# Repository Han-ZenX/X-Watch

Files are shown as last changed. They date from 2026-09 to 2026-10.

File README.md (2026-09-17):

# X-Watch

X-Watch 是一款开源智能手表项目，主控芯片为 **STM32L4R9AII6U**，图形界面基于 **TouchGFX** 开发。本仓库统一管理硬件设计、嵌入式固件、配套软件、文档与测试。

> 项目处于早期开发阶段（硬件 Rev1.0），接口与目录结构可能随迭代调整。

## 核心方案

| 项目 | 选型 |
|---|---|
| 主控 MCU | STM32L4R9AII6U（Arm Cortex-M4F，120 MHz，2 MB Flash，640 KB SRAM，UFBGA169） |
| 图形框架 | TouchGFX（配合 TouchGFX Designer 设计界面） |
| 图形加速 | Chrom-ART（DMA2D）、GFXMMU，显示接口可选 LTDC / MIPI DSI |
| 硬件 EDA | KiCad |
| 固件构建 | CMake + GCC ARM（arm-none-eabi） |
| 大文件管理 | Git LFS |

### 为什么选 STM32L4R9

- **超低功耗**：STM32L4+ 系列，适合电池供电的穿戴设备。
- **图形能力完整**：片上集成 LTDC、MIPI DSI Host、Chrom-ART 加速器和 GFXMMU（适合圆形屏帧缓冲），无需外置图形芯片。
- **TouchGFX 官方支持**：ST 提供 STM32L4R9I-DISCO 参考设计（圆形 AMOLED 屏），可作为软硬件起点，手册见 [docs/references/Rev1.0](docs/references/Rev1.0)。

## 目录结构

```
X-Watch/
├── firmware/      # 嵌入式固件（app / hal / drivers / services 四层架构）
├── hardware/      # 硬件设计（原理图、PCB、BOM、Gerber、3D、引脚表）
├── software/      # 配套软件（desktop / mobile / cloud）
├── tools/         # 构建脚本与辅助工具
├── docs/          # 项目文档
├── tests/         # 单元测试 / 集成测试 / 硬件在环测试
└── ci/            # CI/CD 流水线配置
```

完整的架构说明见 [docs/architecture/architecture.md](docs/architecture/architecture.md)。

## 快速开始

### 1. 获取代码

```bash
git lfs install
git clone git@github.com:Han-ZenX/X-Watch.git
```

### 2. 开发环境

- [STM32CubeMX](https://www.st.com/en/development-tools/stm32cubemx.html)：外设与时钟配置
- [TouchGFX Designer](https://www.st.com/en/development-tools/touchgfxdesigner.html)：UI 设计与代码生成
- GCC ARM 工具链（arm-none-eabi-gcc）、CMake ≥ 3.20、Ninja
- [KiCad](https://www.kicad.org/)：打开 `hardware/schematic/v1.0/XWatch_Rev1.0/` 下的工程
- 调试器：ST-LINK

### 3. 编译固件

```bash
cd firmware
cmake -B build -G Ninja -DBOARD=default
cmake --build build
```

或使用构建脚本：

```bash
python tools/scripts/build.py --board=default
```

## 硬件

- 原理图 / PCB：`hardware/schematic/v1.0/XWatch_Rev1.0/`（KiCad 工程）
- 引脚分配：[hardware/pinout/pinout.md](hardware/pinout/pinout.md)
- 每次硬件改版需同步更新引脚表与 `firmware/boards/` 下对应的板级配置。

## 开发计划

- [ ] 硬件 Rev1.0 原理图与 PCB 完成
- [ ] STM32L4R9 板级支持（时钟、电源、调试串口）
- [ ] 显示屏驱动与 TouchGFX 移植
- [ ] 触摸驱动接入
- [ ] 基础表盘与界面
- [ ] 低功耗管理

## 变更记录

见 [CHANGELOG.md](CHANGELOG.md)。

## 许可证

本项目基于 [MIT License](LICENSE) 开源。

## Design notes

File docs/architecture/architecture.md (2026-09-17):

# 项目架构说明文档

## 1. 项目概述

本项目采用 **Monorepo + 分层模块化** 架构，将固件、硬件、上位机软件、工具链、文档和测试统一管理在同一个仓库中。

**设计目标：**
- 支持长期持续迭代（创业级产品生命周期）
- 硬件多版本并行开发
- 团队扩张后各模块可独立维护
- CI/CD 自动化构建与测试

---

## 2. 目录结构总览

```
project-template/
├── firmware/          # 嵌入式固件（MCU代码）
├── hardware/          # 硬件设计（原理图/PCB/BOM）
├── software/          # 上位机 / 配套软件
├── tools/             # 构建脚本与调试工具
├── docs/              # 项目文档
├── tests/             # 系统级测试
├── ci/                # CI/CD 流水线配置
├── .gitignore         # Git忽略规则
├── .gitattributes     # Git LFS 大文件管理
├── CHANGELOG.md       # 变更日志
└── LICENSE            # 许可证
```

---

## 3. 各目录详细说明

### 3.1 firmware/ — 嵌入式固件

固件采用四层分离架构，核心原则：**更换MCU只改HAL层，业务逻辑零修改**。

```
firmware/
├── CMakeLists.txt            # 顶层构建入口
├── src/
│   ├── main.c               # 入口点（初始化→主循环）
│   ├── app/                 # 【应用层】业务逻辑、状态机、UI
│   ├── hal/                 # 【硬件抽象层】GPIO/时钟/外设封装
│   ├── drivers/             # 【驱动层】具体外设驱动(SPI/I2C/UART)
│   └── services/            # 【服务层】通信协议/存储/OTA
├── boards/                  # 板级配置（不同硬件版本）
│   └── default/
│       └── board_config.h   # 引脚映射、时钟频率等
├── include/                 # 对外公开头文件
├── lib/                     # 第三方库（FreeRTOS/FatFS等）
└── tests/                   # 固件模块单元测试
```

#### 分层职责

| 层级 | 职责 | 可替换性 | 示例 |
|---|---|---|---|
| **app** | 业务逻辑、产品功能 | 不可替换（产品核心） | 测试流程、数据算法、用户交互 |
| **hal** | 硬件抽象、引脚映射 | 换MCU时整体替换 | GPIO操作、时钟配置、中断管理 |
| **drivers** | 外设通信协议实现 | 随外设更换替换 | ADS1258驱动、TCA9548A驱动 |
| **services** | 后台持续运行的服务 | 可独立升级 | TCP通信、Flash存储、OTA升级 |

#### 构建方式

```bash
# Debug构建（默认板级）
cmake -B build -DBOARD=default
cmake --build build

# Release构建
cmake -B build -DBOARD=v2.0 -DCMAKE_BUILD_TYPE=Release
cmake --build build
```

#### 新增板级

```bash
# 复制默认板级配置，修改引脚映射即可
cp -r boards/default boards/v2.0
# 编辑 boards/v2.0/board_config.h
cmake -B build -DBOARD=v2.0
```

---

### 3.2 hardware/ — 硬件设计

管理所有硬件设计文件，按版本号组织，支持多版本并行开发。

```
hardware/
├── schematic/               # 原理图
│   └── v1.0/               # 硬件版本1.0的原理图文件
├── pcb/                     # PCB Layout
│   └── v1.0/               # 硬件版本1.0的PCB文件
├── bom/                     # BOM物料清单（CSV/Excel）
├── gerber/                  # 送厂生产的Gerber文件
├── 3d/                      # 3D外壳/结构件模型
└── pinout/                  # 引脚分配表
    └── pinout.md            # MCU引脚功能对照表
```

#### 版本管理规则

| 规则 | 说明 |
|---|---|
| 原理图改版 | 新建 `schematic/v2.0/`，保留旧版本 |
| BOM变更 | 更新 `bom/` 中的文件，CHANGELOG记录 |
| pinout同步 | 每次硬件改版必须更新 `pinout.md` |
| 大文件管理 | `.SchDoc`/`.PcbDoc` 等通过 Git LFS 跟踪 |

---

### 3.3 software/ — 上位机 / 配套软件

```
software/
├── desktop/                 # PC桌面应用（Qt/Electron等）
├── mobile/                  # 移动端App（iOS/Android）
└── cloud/                   # 云端服务（数据平台/API）
```

各子项目独立维护，通过通信协议（TCP/BLE/MQTT）与固件交互。

---

### 3.4 tools/ — 工具链与脚本

```
tools/
├── scripts/                 # 自动化脚本
│   └── build.py            # 一键构建脚本
├── configs/                 # 通用配置模板
└── utilities/               # 辅助工具
                             # - 固件烧录器
                             # - 校准工具
                             # - 日志分析器
```

#### build.py 用法

```bash
python tools/scripts/build.py --board=default          # Debug构建
python tools/scripts/build.py --board=v2.0 --release   # Release构建
python tools/scripts/build.py --flash                  # 构建+烧录
python tools/scripts/build.py --clean                  # 清理
```

---

### 3.5 docs/ — 项目文档

```
docs/
├── architecture/            # 系统架构设计文档
├── api/                     # API接口文档（通信协议）
├── hardware/                # 硬件说明文档
├── manufacturing/           # 生产工艺/SOP文档
└── user-guide/              # 用户使用手册
```

---

### 3.6 tests/ — 系统级测试

```
tests/
├── unit/                    # 单元测试（纯软件，不需要硬件）
├── integration/             # 集成测试（模块间交互）
└── hwt/                     # 硬件在环测试（Hardware-in-the-Loop）
```

#### 测试策略

| 测试类型 | 运行环境 | 触发时机 | 覆盖范围 |
|---|---|---|---|
| unit | PC (Host) | 每次commit | 算法/逻辑函数 |
| integration | PC + 模拟器 | PR合并前 | 模块间通信 |
| hwt | 实际硬件 | 发版前 | 全链路验证 |

---

### 3.7 ci/ — CI/CD 流水线

```
ci/
└── workflows/
    └── build.yml            # GitHub Actions 构建配置
```

流水线自动执行：
1. 编译固件（多板级）
2. 运行单元测试
3. 生成二进制产物
4. （可选）自动烧录/部署

---

## 4. 核心架构原则

| 原则 | 实践方式 |
|---|---|
| **Monorepo** | 硬件+固件+软件在同一仓库，版本一致 |
| **分层隔离** | app不直接调用寄存器，只通过hal/driver接口 |
| **板级抽象** | 引脚映射集中在 `boards/` 目录，代码中无硬编码 |
| **组件化** | 每个驱动/服务是独立编译单元（CMake library） |
| **测试前置** | 新增功能必须配套单元测试 |
| **二进制管理** | 原理图/PCB用Git LFS，避免仓库膨胀 |
| **版本关联** | 硬件版本与固件版本通过Git Tag关联 |

---

## 5. 开发工作流

### 5.1 新功能开发

```
1. 创建分支:  git checkout -b feat/xxx
2. 固件开发:  在 firmware/src/app/ 添加业务逻辑
3. 驱动开发:  在 firmware/src/drivers/ 添加外设驱动
4. 编写测试:  在 firmware/tests/ 或 tests/unit/ 添加测试
5. 本地验证:  python tools/scripts/build.py --board=default
6. 提交PR:    CI自动编译+测试
```

### 5.2 硬件改版

```
1. 新建版本:  cp -r hardware/schematic/v1.0 hardware/schematic/v2.0
2. 更新设计:  在EDA工具中修改v2.0原理图/PCB
3. 更新引脚:  修改 hardware/pinout/pinout.md
4. 新增板级:  cp -r firmware/boards/default firmware/boards/v2.0
5. 适配固件:  修改 boards/v2.0/board_config.h
6. 验证:      cmake -DBOARD=v2.0 编译通过
```

### 5.3 发版流程

```
1. 更新 CHANGELOG.md
2. Git Tag:   git tag v1.2.0-hw1.0 (固件版本-硬件版本)
3. CI自动:    编译Release固件 → 生成Gerber → 打包发布
```

---

## 6. 参考项目

本架构参考以下知名开源项目的组织方式：

| 项目 | 参考要素 |
|---|---|
| ESP-IDF | components组件化、CMake构建系统 |
| Zephyr RTOS | boards板级抽象、Kconfig配置 |
| RIOT-OS | cpu/drivers/sys分层、pkg第三方包 |
| FreeRTOS | 内核源码单一副本、Demo目录分离 |

---

## 7. 技术选型建议

| 领域 | 推荐方案 |
|---|---|
| 构建系统 | CMake + Ninja |
| 版本控制 | Git + Git LFS |
| CI/CD | GitHub Actions / GitLab CI |
| 测试框架 | Unity (C) / Google Test (C++) |
| 文档工具 | Doxygen + Sphinx |
| 硬件EDA | Altium Designer / KiCad |
| 通信协议 | 自定义二进制协议 / MQTT / SCPI |

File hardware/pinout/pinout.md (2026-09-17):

# 引脚分配表

| 引脚 | 功能 | 说明 |
|---|---|---|
| PA9  | UART_TX | 调试串口发送 |
| PA10 | UART_RX | 调试串口接收 |
| PA5  | SPI_SCK | SPI时钟 |
| PA6  | SPI_MISO | SPI主入从出 |
| PA7  | SPI_MOSI | SPI主出从入 |
| PA4  | SPI_CS | SPI片选 |
| PB6  | I2C_SCL | I2C时钟 |
| PB7  | I2C_SDA | I2C数据 |
| PC13 | LED_STATUS | 状态指示灯 |
| PA0  | BTN_USER | 用户按键 |

> 此文件应与原理图保持同步。每次硬件改版需更新。

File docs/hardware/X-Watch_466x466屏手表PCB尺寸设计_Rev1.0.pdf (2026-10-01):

X-Watch 466×466 屏手表 PCB 尺寸设计 Rev1.0 | 第 1 页

# 466×466 屏手表 PCB 尺寸设计

X-Watch Rev2.0 · 1.43″ 466×466 AMOLED（DO0143FMST02）· 主板外形估算 · Rev1.0 · 2026-10-01

## 1. 结论

项目 | 推荐值 | 依据
表壳外径 | Ø46 mm（厚约 11 mm） | 同屏商用表集中在 46–47 mm
中框内腔 | Ø42 mm | 壁厚 2 mm
屏模组 | Ø39.2 mm，显示区 Ø36.35 mm | DO0143FMST02 规格书第 3、6 页
主板 PCB | Ø36 mm，一侧切平 2 mm（可选范围 Ø34–38） | 比屏模组单边缩 1.6 mm，比内腔单边缩 3 mm
可用面积 | 单面约 1000 mm²，双面约 2000 mm² | 扣除安装孔、净空后实际可布约 60–70%
板厚 / 层数 | 0.8 mm，6 层（打样可 1.0 mm 4 层） | 商用表多为 0.6–0.8 mm 多层 HDI

一句话：1.43″ 466×466 屏配 Ø46 mm 表壳，主板做 Ø36 mm 左右的圆板（约 36 × 34 mm），与屏模组投影基本重合、略小一圈。这和项目已有的 1.2″ 屏方案的比例一致：Rev1.0 文档中屏模组 Φ33.22 → 主板约 Φ30，比值 0.90；本方案 39.2 → 36，比值 0.92。

## 2. 同屏商用手表参考

下表都是 1.43″ 466×466 AMOLED 的手表（Waveshare 为同屏开发板）。表壳尺寸来自官方或评测站点公开 参数；电池容量来自拆解报告。这些产品的拆解报告都没有公布主板的毫米尺寸，所以第 3 节用几何约束推算主板大小。

产品 | 表壳尺寸（mm） | 屏幕 | 电池 | 备注
华为 WATCH GT 4 46mm | 46 × 46 × 10.9 | 1.43″ 466×466 | —
Amazfit GTR 4 | 46 × 46 × 10.6 | 1.43″ 466×466 | —
小米 Watch S1 | 46.5 × 46.5 × 11 | 1.43″ 466×466 | 470 mAh | 主控 BES2500BP，PMIC DA9168
小米 Watch S3 | 47 × 47 × 12 | 1.43″ 466×466 | 486 mAh | 主控 BES2700BP，PMIC DA9168
OnePlus Watch 2 | 47 × 46.6 × 12.1 | 1.43″ 466×466 | — | Wear OS
TicWatch Pro 5 | 50 × 48 × 12 | 1.43″ 466×466 | — | Wear OS，双层屏
Waveshare ESP32-S3-Touch-AMOLED-1.43 | 盖板 Ø46，带壳 Ø48 × 12.3 | 1.43″ 466×466 | 外接 | 开发板，主板安装孔距 31.5 mm

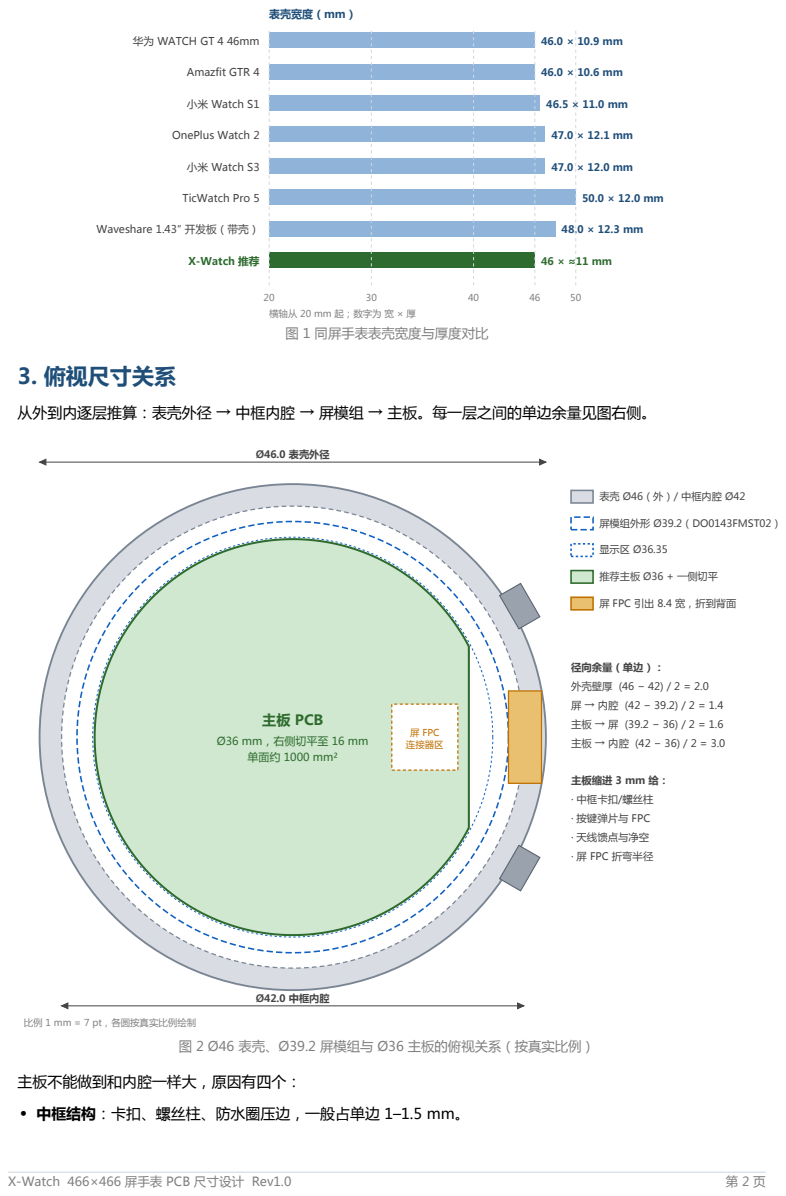
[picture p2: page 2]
X-Watch 466×466 屏手表 PCB 尺寸设计 Rev1.0; 表壳宽度（mm）; 华为 WATCH GT 4 46mm; Amazfit GTR 4; 小米 Watch S1; OnePlus Watch 2; 小米 Watch S3; TicWatch Pro 5; Waveshare 1.43″ 开发板（带壳）; X-Watch 推荐; 3. 俯视尺寸关系; 主板 PCB; 屏 FPC 连接器区; Ø46.0 表壳外径; Ø42.0 中框内腔; 表壳 Ø46（外）/ 中框内腔 Ø42; 屏模组外形 Ø39.2（DO0143FMST02）; 显示区 Ø36.35; 推荐主板 Ø36 + 一侧切平; 径向余量（单边）：; 外壳壁厚 (46 − 42) / 2 = 2.0; 主板缩进 3 mm 给：; · 中框卡扣/螺丝柱; · 按键弹片与 FPC; · 天线馈点与净空; · 屏 FPC 折弯半径; 主板不能做到和内腔一样大，原因有四个：

横轴从 20 mm 起；数字为 宽 × 厚
图 1 同屏手表表壳宽度与厚度对比

从外到内逐层推算：表壳外径 → 中框内腔 → 屏模组 → 主板。每一层之间的单边余量见图右侧。

屏 FPC 引出 8.4 宽，折到背面

Ø36 mm，右侧切平至 16 mm
单面约 1000 mm²

比例 1 mm = 7 pt，各圆按真实比例绘制

图 2 Ø46 表壳、Ø39.2 屏模组与 Ø36 主板的俯视关系（按真实比例）

• 中框结构：卡扣、螺丝柱、防水圈压边，一般占单边 1–1.5 mm。

## 4. 厚度方向堆叠

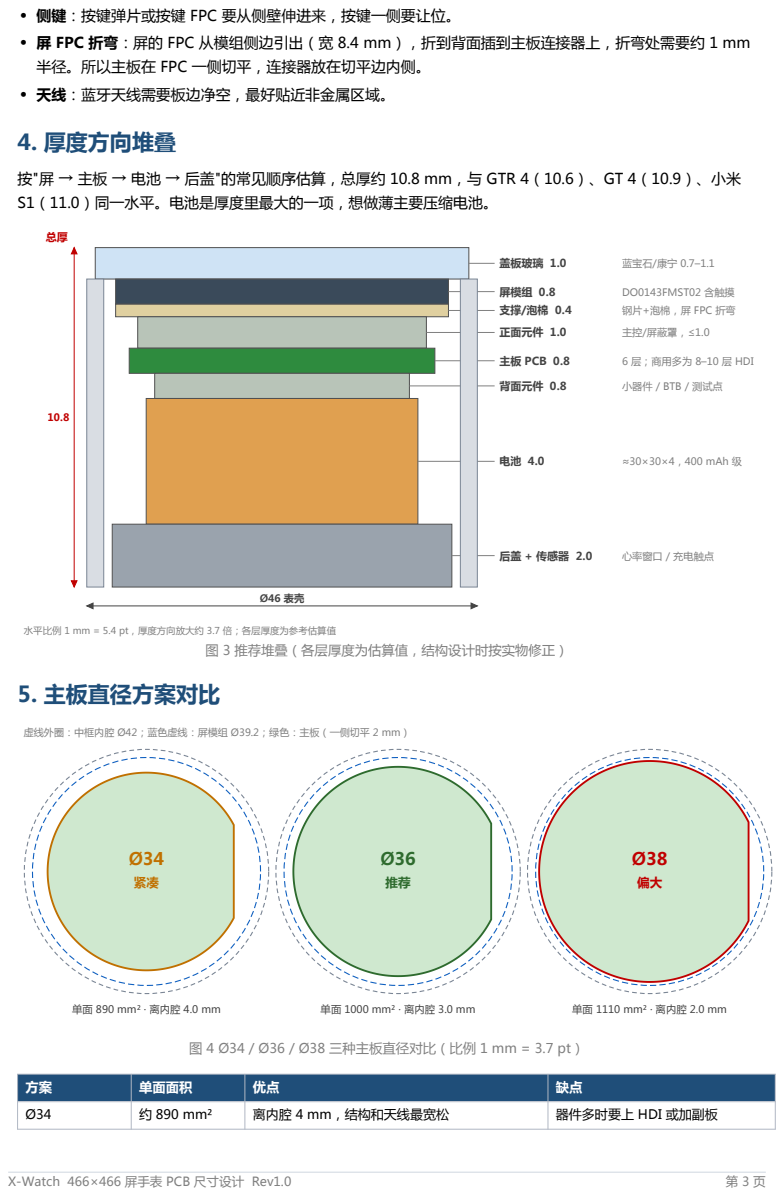
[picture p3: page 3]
X-Watch 466×466 屏手表 PCB 尺寸设计 Rev1.0; 盖板玻璃 1.0; 蓝宝石/康宁 0.7–1.1; 屏模组 0.8; DO0143FMST02 含触摸; 钢片+泡棉，屏 FPC 折弯; 正面元件 1.0; 主控/屏蔽罩，≤1.0; 主板 PCB 0.8; 6 层；商用多为 8–10 层 HDI; 背面元件 0.8; 小器件 / BTB / 测试点; ≈30×30×4，400 mAh 级; 后盖 + 传感器 2.0; 心率窗口 / 充电触点; 5. 主板直径方案对比

• 侧键：按键弹片或按键 FPC 要从侧壁伸进来，按键一侧要让位。
• 屏 FPC 折弯：屏的 FPC 从模组侧边引出（宽 8.4 mm），折到背面插到主板连接器上，折弯处需要约 1 mm
半径。所以主板在 FPC 一侧切平，连接器放在切平边内侧。
• 天线：蓝牙天线需要板边净空，最好贴近非金属区域。

按"屏 → 主板 → 电池 → 后盖"的常见顺序估算，总厚约 10.8 mm，与 GTR 4（10.6）、GT 4（10.9）、小米
S1（11.0）同一水平。电池是厚度里最大的一项，想做薄主要压缩电池。

水平比例 1 mm = 5.4 pt，厚度方向放大约 3.7 倍；各层厚度为参考估算值

图 3 推荐堆叠（各层厚度为估算值，结构设计时按实物修正）

虚线外圈：中框内腔 Ø42；蓝色虚线：屏模组 Ø39.2；绿色：主板（一侧切平 2 mm）

单面 890 mm² · 离内腔 4.0 mm

单面 1000 mm² · 离内腔 3.0 mm

单面 1110 mm² · 离内腔 2.0 mm

图 4 Ø34 / Ø36 / Ø38 三种主板直径对比（比例 1 mm = 3.7 pt）

方案 | 单面面积 | 优点 | 缺点

Ø34 | 约 890 mm² | 离内腔 4 mm，结构和天线最宽松 | 器件多时要上 HDI 或加副板

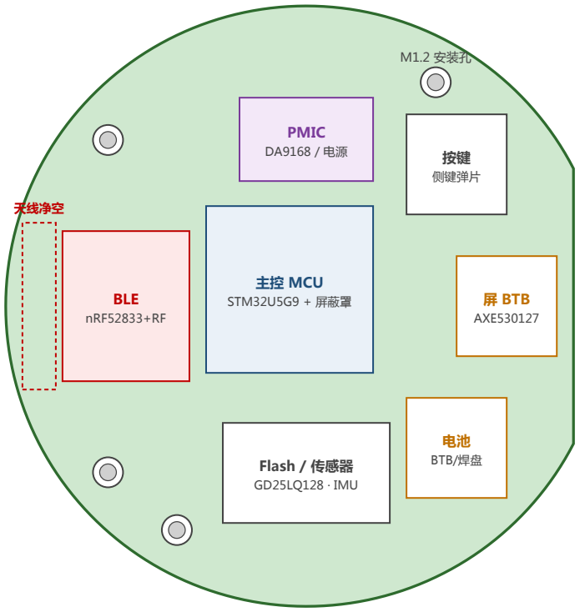
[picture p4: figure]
主控 MCU; STM32U5G9 + 屏蔽罩; 屏 BTB; AXE530127; BLE; nRF52833+RF; PMIC; Flash / 传感器; GD25LQ128 · IMU; 侧键弹片; BTB/焊盘; 天线净空; M1.2 安装孔

X-Watch 466×466 屏手表 PCB 尺寸设计 Rev1.0 | 第 4 页
方案 | 单面面积 | 优点 | 缺点
Ø36（推荐） | 约 1000 mm² | 面积与结构余量平衡；比屏小一圈，组装时屏能完 全盖住主板 | —
Ø38 | 约 1110 mm² | 面积最大 | 离内腔只剩 2 mm，侧键、卡扣、天 线都很挤；几乎与屏外形一样大

面积按"圆减去 2 mm 切平弓形"计算。按现有《商业手表拆解参考与芯片选型》文档的估算，主控、BLE、PMIC 、传感器等器件本体约 530 mm²，Ø36 双面约 2000 mm²，按 60% 可用率算约 1200
mm²，余量充足，不需要 HDI 也有机会放下（BGA 器件扇出除外）。

## 6. 主板分区建议

分区原则

- 屏 BTB 放在屏 FPC 折弯一侧（切平边）
位置按屏规格书第 6 页 FPC 尺寸定
- BLE 射频放在对侧板边，天线朝外
净空区所有层禁铜
- 主控居中，扇出走线最短
- PMIC 靠近电池与充电触点
- 按键区与中框侧键对位
- 安装孔 3–4 个，距板边 ≥1 mm

本图只表达相对位置，

不代表实际器件尺寸和最终布局

图 5 Ø36 主板功能分区示意（相对位置，非实际布局）

## 7. 下一步

- 先定结构，再定板框：表壳和中框的内腔、按键位置、螺丝柱位置确定后，在 KiCad 的 Edge.Cuts 层画 Ø36 板框。
- 导入屏的 3D 模型：用屏规格书第 6 页的 FPC 引出位置确定屏 BTB 连接器坐标，避免 FPC 折弯后够不着。
- 做纸板/3D 打印样件：把屏、主板外形、电池叠在一起验证厚度和装配。
- 确认电池：根据剩余厚度选电池，例如 4 mm 厚约 400 mAh 级；需要更大容量时表壳要加厚。

说明：表壳、屏幕、电池数据来自公开资料；主板尺寸、层厚和面积是按几何关系推算的工程估算值，不是某款产品的 实测值。最终尺寸以结构设计为准。

X-Watch 466×466 屏手表 PCB 尺寸设计 Rev1.0 | 第 5 页

## 8. 参考资料

- DWO DO0143FMST02 规格书 REV 0.0（docs/references/Rev2.0/显示屏）：模组 39.15 × 39.3 × 0.8 mm，显示区 36.35 mm
- HUAWEI WATCH GT 4 规格：consumer.huawei.com/uk/wearables/watch-gt4/specs/
- Amazfit GTR 4 规格：gadgetsandwearables.com/technical-specs/amazfit-gtr-4/
- 小米 Watch S1 / S3 规格：mi.com/global/product/xiaomi-watch-s1/specs/、mi.com/global/product/ xiaomi-watch-s3/specs/
- 小米 Watch S1 / S3 拆解：52audio.com/archives/115291.html、52audio.com/archives/189871.html
- OnePlus Watch 2 规格：gsmarena.com/oneplus_watch_2-12843.php；TicWatch Pro 5：androidcentral.com
- Waveshare ESP32-S3-Touch-AMOLED-1.43 尺寸图：docs.waveshare.com/ESP32-S3-Touch-AMOLED-1.43
- X-Watch 商业手表拆解参考与芯片选型 Rev1.0、显示屏候选方案对比 Rev1.0（docs/hardware）

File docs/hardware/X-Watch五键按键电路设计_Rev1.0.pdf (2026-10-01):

X-Watch 五键按键电路设计 Rev1.0

第 1 页

# 五键按键电路设计

X-Watch Rev2.0 · BUTTONS 页 · SW1–SW5 与 DA9168 / STM32U5G9 连接 · Rev1.0 · 2026-09-28

## 1. 方案概述

X-Watch Rev2.0 的 BUTTONS 页放了 5 个松下 EVPAEDB2A（立创 C79150）侧推轻触开关 SW1–SW5。按键布 局参考佳明 fēnix 7：左 3 右 2，左侧管"看"（电源、上下翻页），右侧管"做"（确认、返回），触摸屏只做辅助。

电路上分两类：SW1 是电源键，同时接 DA9168 的 RIN_N（Ship 模式唤醒、长按 12s 硬件复位）和 MCU； SW2–SW5 是功能键，只接 STM32U5G9 的 GPIO，任何误触都不会让整机断电。

X-Watch

1.43" AMOLED 触摸屏

12

6

SW1
PWR·LIGHT

SW2
UP·MENU

SW3
DOWN

SW4
START·OK

SW5
BACK
位号 位置 | 功能 | 连接
SW1 | 左上 10 点 | 电源 / 背光 | RIN_N + GPIO
SW2 | 左中 9 点 | 上翻 / 菜单 | GPIO
SW3 | 左下 8 点 | 下翻 | GPIO
SW4 | 右上 2 点 | 开始 / 确认 | GPIO
SW5 | 右下 4 点 | 返回 / 计圈 | GPIO

左侧 3 键管"看"：电源、上下翻页
右侧 2 键管"做"：确认、返回
只有 SW1 接 DA9168 RIN_N（唤醒 / 硬件复位）

图 1 五键布局与功能分配（佩戴视角正视图，左手佩戴）

位号 | 位置 | 功能 | 短按 | 长按 | 连接
SW1 | 左上 10 点 | 电源 / 背光 | 亮屏、Ship 唤醒 | 1s 控制菜单；3s 关机菜单；12s 硬件复 位 | DA9168 RIN_N + PA0
SW2 | 左中 9 点 | 上翻 / 菜单 | 向上滚动 | 1s 主菜单 | PA1
SW3 | 左下 8 点 | 下翻 | 向下滚动 | 1s 音乐控制 | PA2
SW4 | 右上 2 点 | 开始 / 确认 | 确认、开始/停止活 动 | 1s 可自定义 | PA3
SW5 | 右下 4 点 | 返回 / 计圈 | 返回、活动中计圈 | 1s 最近应用 | PA4

组合键：SW3 + SW4 同时长按 = 锁定 / 解锁触摸屏（同 fēnix 7 的 DOWN + START）。短按、长按的具体功能由固件定 义，表中为建议值。

## 2. 当前原理图状态

对 BUTTONS.kicad_sch 和顶层 XWatch_Rev2.0.kicad_sch 逐项核对的结果：

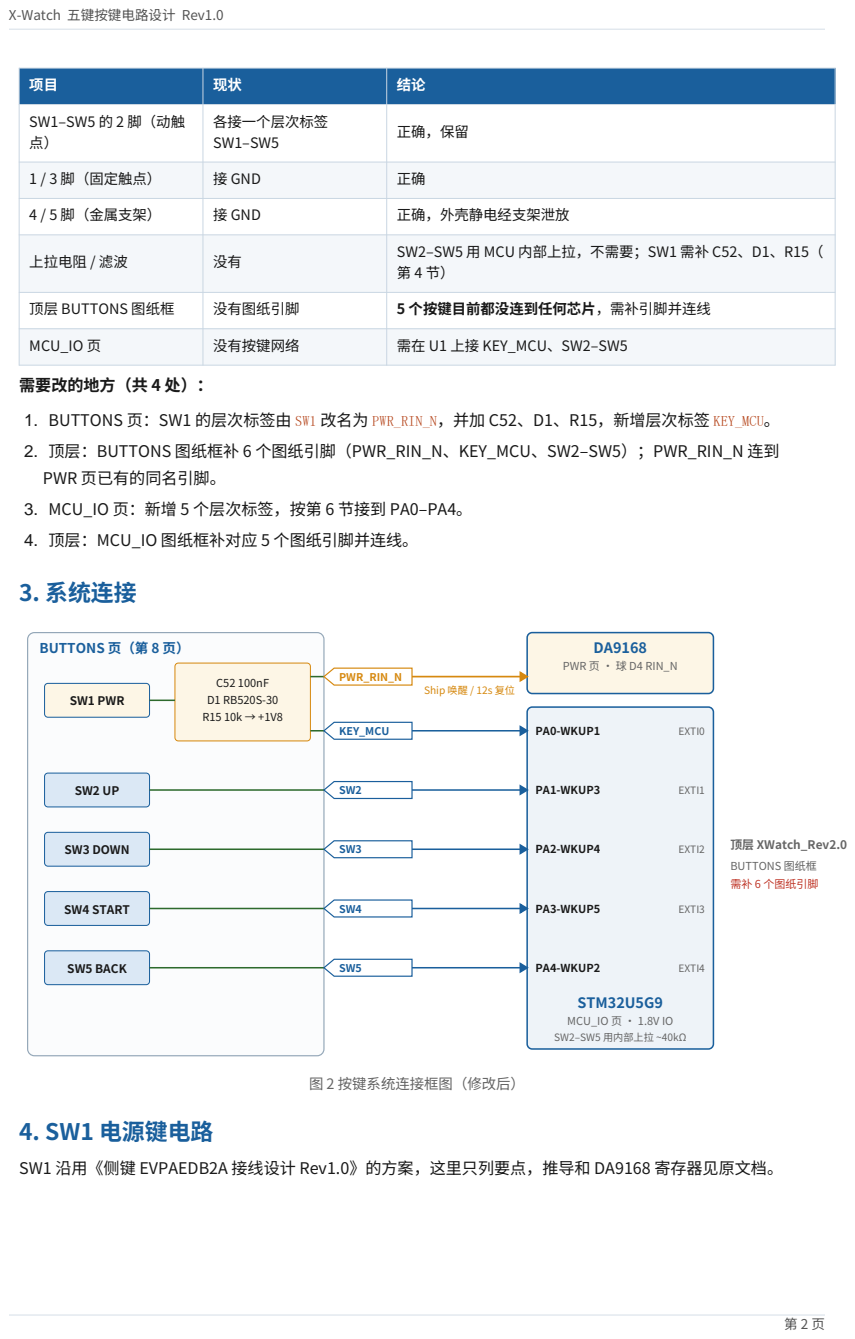
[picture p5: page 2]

SW1–SW5 的 2 脚（动触 点） | 各接一个层次标签 SW1–SW5 | 正确，保留

1 / 3 脚（固定触点） | 接 GND | 正确

4 / 5 脚（金属支架） | 接 GND | 正确，外壳静电经支架泄放

上拉电阻 / 滤波 | 没有 | SW2–SW5 用 MCU 内部上拉，不需要；SW1 需补 C52、D1、R15（ 第 4 节）

顶层 BUTTONS 图纸框 | 没有图纸引脚 | 5 个按键目前都没连到任何芯片，需补引脚并连线

MCU_IO 页 | 没有按键网络 | 需在 U1 上接 KEY_MCU、SW2–SW5

1. BUTTONS 页：SW1 的层次标签由 SW1 改名为 PWR_RIN_N，并加 C52、D1、R15，新增层次标签 KEY_MCU。

2. 顶层：BUTTONS 图纸框补 6 个图纸引脚（PWR_RIN_N、KEY_MCU、SW2–SW5）；PWR_RIN_N 连到
PWR 页已有的同名引脚。
3. MCU_IO 页：新增 5 个层次标签，按第 6 节接到 PA0–PA4。

SW1 沿用《侧键 EVPAEDB2A 接线设计 Rev1.0》的方案，这里只列要点，推导和 DA9168 寄存器见原文档。

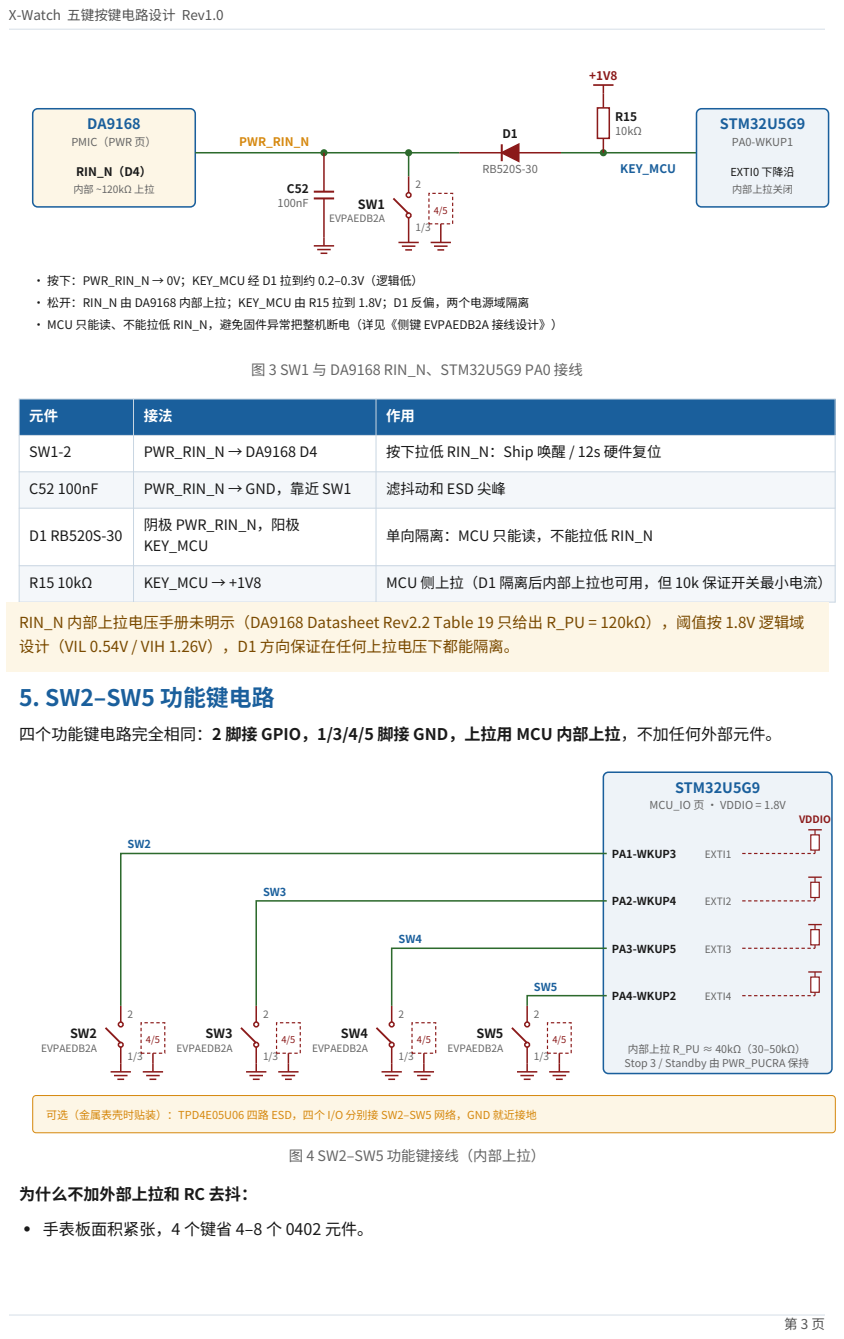
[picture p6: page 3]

• 按下：PWR_RIN_N → 0V；KEY_MCU 经 D1 拉到约 0.2–0.3V（逻辑低）
• 松开：RIN_N 由 DA9168 内部上拉；KEY_MCU 由 R15 拉到 1.8V；D1 反偏，两个电源域隔离
• MCU 只能读、不能拉低 RIN_N，避免固件异常把整机断电（详见《侧键 EVPAEDB2A 接线设计》）

SW1-2 | PWR_RIN_N → DA9168 D4 | 按下拉低 RIN_N：Ship 唤醒 / 12s 硬件复位

C52 100nF | PWR_RIN_N → GND，靠近 SW1 | 滤抖动和 ESD 尖峰

D1 RB520S-30 | 阴极 PWR_RIN_N，阳极 KEY_MCU | 单向隔离：MCU 只能读，不能拉低 RIN_N

R15 10kΩ | KEY_MCU → +1V8 | MCU 侧上拉（D1 隔离后内部上拉也可用，但 10k 保证开关最小电流）

RIN_N 内部上拉电压手册未明示（DA9168 Datasheet Rev2.2 Table 19 只给出 R_PU = 120kΩ），阈值按 1.8V 逻辑域
设计（VIL 0.54V / VIH 1.26V），D1 方向保证在任何上拉电压下都能隔离。

四个功能键电路完全相同：2 脚接 GPIO，1/3/4/5 脚接 GND，上拉用 MCU 内部上拉，不加任何外部元件。

可选（金属表壳时贴装）：TPD4E05U06 四路 ESD，四个 I/O 分别接 SW2–SW5 网络，GND 就近接地

第 4 页

- STM32U5 的内部上拉在 Run、Stop 0/1/2 模式下由 GPIOx_PUPDR 控制；进入 Stop 3、Standby、 Shutdown 时由 PWR_PUCRA 接管（需置 PWR_APCR.APC = 1），按键在所有低功耗模式下都有确定的高电 平。
- 规格书抖动时间最大 10ms，软件去抖 20ms 已足够，硬件 RC 只会增加元件和按下时的充放电电流。

电气校核：

检查项 | 计算 / 依据 | 结论
高电平 | 松开时内部上拉到 VDDIO = 1.8V，开关断开无漏电 | 满足
低电平 | 按下时 GPIO ≈ 0V（触点电阻 ≤ 1Ω，规格书），VIL ≤ 0.3 × 1.8V = 0.54V | 满足
按下电流 | 1.8V / 40kΩ ≈ 45µA（30–50kΩ 对应 36–60µA） | 只在按下期间耗电
开关最小负载 | EVP-AE 额定 10µA / 2V DC 起；45µA 远大于 10µA，但 1.8V 略低于 2V | 可用，同 SW1，样机验证
抖动 | 规格书 Bouncing ≤ 10ms（ON、OFF） | 软件去抖取 20ms，有 2 倍余 量
待机功耗 | 松开时开关断开，上拉无电流 | 0
ESD | 支架（4/5 脚）接 GND 吸收大部分静电 | 金属表壳建议加 TVS（见下）

如果表壳是金属或按键帽是金属，建议在 SW2–SW5 四个网络上加一颗四路 ESD 阵列（如 TI TPD4E05U06，USON-10 ，四个 I/O 正好对应四个键），SW1 那一路已有 C52。塑料外壳可以不贴，原理图上画出来并标 DNP 即可。

## 6. GPIO 分配

分配原则：

1. EXTI 线号不同：STM32 同一编号的 EXTI 线只能选一个端口（PA0 和 PB0 共用 EXTI0），5 个键必须用 5 个 不同的引脚编号，否则中断无法区分。
2. WKUP 编号不同：Stop 3、Standby、Shutdown 模式下普通 EXTI 不能唤醒，只能靠 WKUP1–WKUP8。每 个 WKUPn 只能从候选脚中选一个（PWR_WUCR3.WUSELn），所以 5 个键要占 5 个不同的 WKUP 编号。
3. 避开已用和特殊引脚：PG13/PG14（I2C1）、PH4/PH5（I2C5）、PH7/PH8（I2C3）已用；PA13/PA14（ SWD）、PH3（BOOT0）、PC14/PC15、PH0/PH1（晶振）不用。
网络 | 建议引脚 | EXTI | WKUP | 备选引脚（同一 WKUP 编号）
KEY_MCU（SW1） | PA0 | EXTI0 | WKUP1 | PB2、PE4
SW2 | PA1 | EXTI1 | WKUP3 | PB6、PE6
SW3 | PA2 | EXTI2 | WKUP4 | PB1、PB7
SW4 | PA3 | EXTI3 | WKUP5 | PB8、PC5
SW5 | PA4 | EXTI4 | WKUP2 | PC13、PE5

PA0–PA4 在同一端口，初始化和 PWR_PUCRA 配置最简单。如果 PCB 上这几个球离按键太远，可以换成备选列里的引 脚，但换完要再查一遍 EXTI 编号不能重复（比如 SW2 换 PB6 后，EXTI6 就不能再给别的键用）。WKUP 候选脚以 RM0456 的 PWR_WUCR3 为准，表中来自原理图符号的引脚名。

## 7. 元件清单

第 5 页

位号 | 规格 | 封装 | 数量 | 说明
SW1–SW5 | EVPAEDB2A（C79150），3.0N，20 万 次 | 板边侧推 4.5 × 2.6mm | 5 | 已放置
D1 | RB520S-30，30V / 200mA 肖特基 | SOD-523 | 1 | SW1 用，待添加
R15 | 10kΩ / 1% | 0402 | 1 | SW1 用，待添加
C52 | 100nF / 10V / X5R | 0402 | 1 | SW1 用，待添加
U13 | TPD4E05U06 四路 ESD | USON-10 | 1 | 可选，金属外壳时贴装，否则 DNP

位号按当前原理图顺延：已用到 R14、C49、U12；D1 目前未使用。

## 8. PCB 与结构要点

- 板边缺口：EVPAEDB2A 封装自带 3.8 × 1.35mm 的 Edge.Cuts 缺口，5 个开关都要让缺口正好落在板框上并 连成一体。左侧 3 个开关在同一条板边上，间距按表壳按键孔位定，建议中心距不小于 7mm，避免手指同时 按到两个键。
- 走线：按键信号是低速信号，没有阻抗要求；1/3 脚各打一个 GND 过孔，4/5 脚就近接地。SW1 的 C52 紧靠 2 脚；ESD 阵列（如贴装）放在开关和 MCU 之间、靠近开关。
- 结构：按键帽与开关按压头之间留 0.1–0.2mm 间隙，每个按键轴加 O 型圈防水。SW4（START）按键帽建议 用红色或带标识，方便盲按。

## 9. 固件要点

0 | 20ms | 1s | 3s | 12s按住时间
SW1 电源 | 去抖 | 短按：亮屏 | 长按 1s：控制菜单 | 按住 3s：关机菜单 | 硬复位
SW2 UP | 去抖 | 短按：上翻 | 长按 1s：主菜单
SW3 DOWN | 去抖 | 短按：下翻 | 长按 1s：音乐控制
SW4 START | 去抖 | 短按：确认/开始 | 长按 1s：自定义
SW5 BACK | 去抖 | 短按：返回/计圈 | 长按 1s：最近应用

DA9168 t_PRESS

图 5 按住时间与动作阈值（示意，时间轴非比例）

- GPIO 配置：PA1–PA4 设为输入 + 内部上拉；PA0（KEY_MCU）设为输入、关闭内部上拉（外部已有 R15）。 全部配置为 EXTI 下降沿中断。
- 去抖：中断触发后启动 20ms 定时器，到时再读电平确认；按住期间用定时器计时，区分短按（1s 内松开） 和长按（按住满 1s）。
- 低功耗：进入 Stop 3 / Standby 前，把 PWR_PUCRA 的 PU0–PU4 置 1、PWR_APCR.APC 置 1，并在 PWR_WUCR1/2/3 里使能 WKUP1–WKUP5、选下降沿和对应引脚。
- 与硬件复位的关系：SW1 的关机菜单设在 3s，远小于 DA9168 的 12s 硬件复位（t_PRESS），两者不冲突； 其他 4 个键没有硬件复位功能，长按多久都安全。

第 6 页

- 组合键：两个键都处于按下状态并持续 ≥ 1s 才触发组合功能，先按下的键的单键长按要推迟到另一个键确定 没有按下后再执行。

## 10. 待确认事项

- 引脚：规格书 Circuit Diagram 标为 1、2、1'（1 与 1' 内部相连），与工程符号的 1/3 固定触点、2 动触点一 致；首批样品仍建议用万用表确认一次。
- 1.8V 下开关导通可靠性（额定最小 2V / 10µA）需在样机上做按压寿命和接触电阻测试。
- 外壳材质确定后决定 U13（ESD 阵列）是否贴装。
- PCB 布局后按实际 BGA 球位置复核第 6 节的引脚分配。

## 11. 参考资料

- X-Watch 侧键 EVPAEDB2A 接线设计 Rev1.0（docs/hardware）
- X-Watch 佳明 fēnix 7 按键布局与功能分析 Rev1.0（docs/hardware）
- EVPAEDB2A 规格书：docs/references/Rev2.0/按键/C79150_轻触开关_EVPAEDB2A_规格书 _WJ129045.PDF
- ST RM0456 STM32U5 参考手册：GPIO、EXTI、PWR（WUCR、PUCR、APCR）章节
- 原理图：hardware/schematic/v1.0/XWatch_Rev2.0/BUTTONS.kicad_sch、MCU_IO.kicad_sch

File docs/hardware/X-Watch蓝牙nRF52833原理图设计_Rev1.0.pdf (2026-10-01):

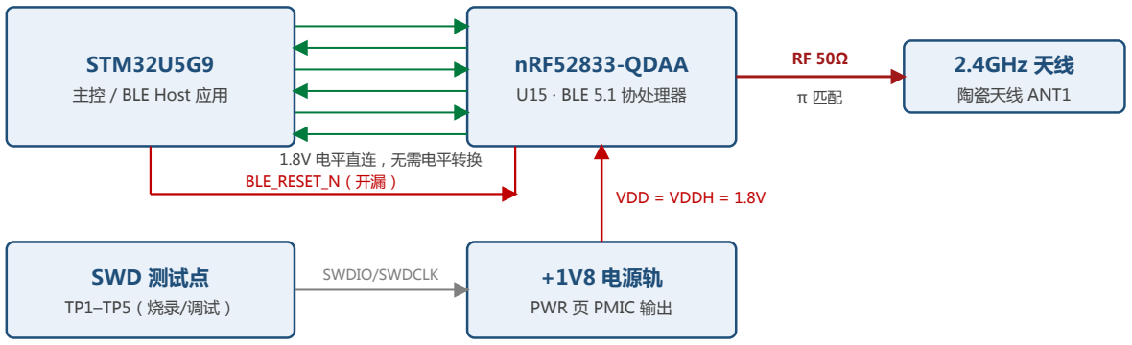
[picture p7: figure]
STM32U5G9; 主控 / BLE Host 应用; nRF52833-QDAA; U15 · BLE 5.1 协处理器; 2.4GHz 天线; 陶瓷天线 ANT1; +1V8 电源轨; PWR 页 PMIC 输出; SWD 测试点; 1.8V 电平直连，无需电平转换 BLE_RESET_N（开漏）; VDD = VDDH = 1.8V; SWDIO/SWDCLK

X-Watch 蓝牙 nRF52833 原理图设计 Rev1.0 | 第 1 页

# 蓝牙 nRF52833 原理图设计

X-Watch Rev2.0 · nRF52833-QDAA-R（QFN40）蓝牙协处理器 · Rev1.0 · 2026-10-01

## 1. 方案概述

nRF52833-QDAA-R（立创 C2895249）作为 BLE 协处理器，挂在 STM32U5G9 的一路 UART 上（4 线带硬件流控），另用 BLE_IRQ / BLE_WAKE 两根 GPIO 做双向唤醒，STM32 通过 BLE_RESET_N 控制蓝牙芯片复位。

供电直接取系统 +1V8 轨：VDD 与 VDDH 短接，芯片工作在 Normal Voltage 模式，GPIO 电平 = 1.8V，与 STM32U5G9 的 IO 电平一致，不需要电平转换。开启 REG1 DC/DC（外接 L6/L7）降低收发电流。USB 和 NFC 不使用。

外围电路取自 Nordic《nRF52833 Product Specification v1.7》第 7.3 节 QDAA QFN40 参考电路：以配置 6（外部供电、无 USB/NFC）为基础，加上配置 5 的 DC/DC 滤波（L3 10µH + L4 15nH + C14 47nF），元件值与官方一致。位号按当前 Rev2.0 原理图已用编号顺延（U14、C78、L3、X2、R22 之后）。

## 2. 系统连接框图

UART 4 线 + 2 根握手

工作模式：Normal Voltage（VDD 与 VDDH 短接）+ REG1 DC/DC；不用 USB / NFC 时钟：32MHz 晶振（必须）+ 32.768kHz 晶振（低功耗计时）

图 1 蓝牙子系统连接关系

## 3. 详细原理图

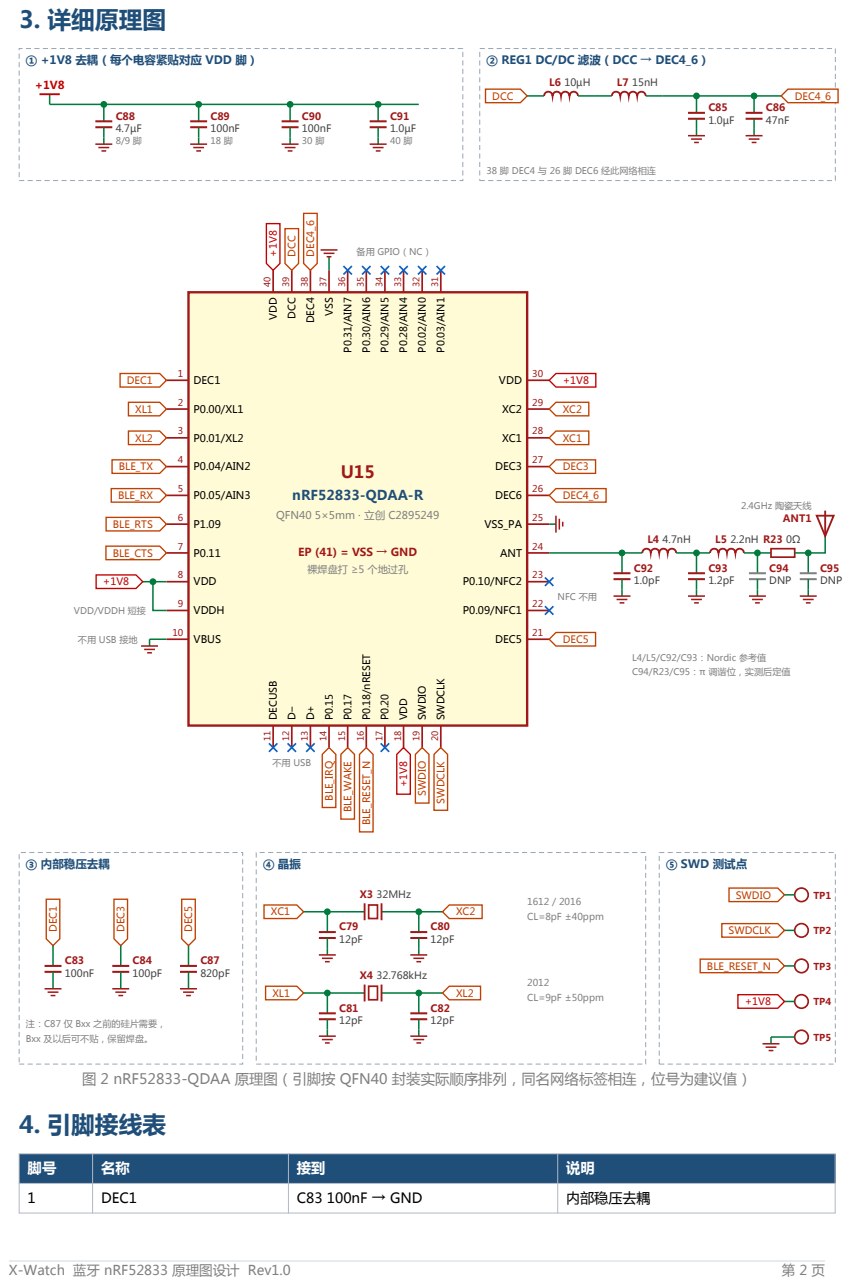
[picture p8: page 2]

② REG1 DC/DC 滤波（DCC → DEC4_6）

图 2 nRF52833-QDAA 原理图（引脚按 QFN40 封装实际顺序排列，同名网络标签相连，位号为建议值）
4. 引脚接线表

1 | DEC1 | C83 100nF → GND | 内部稳压去耦

X-Watch 蓝牙 nRF52833 原理图设计 Rev1.0 | 第 3 页
脚号 | 名称 | 接到 | 说明
2 / 3 | P0.00/XL1 · P0.01/XL2 | X4 32.768kHz + C81/C82 12pF | 低频晶振；不贴时这两脚可作 GPIO，改用内部 RC（精度 ±500ppm，更耗电）
4 | P0.04 | BLE_TX → STM32 RX | UART TXD（nRF 发送）
5 | P0.05 | BLE_RX ← STM32 TX | UART RXD（nRF 接收）
6 | P1.09 | BLE_RTS → STM32 CTS | UART RTS（硬件流控）
7 | P0.11 | BLE_CTS ← STM32 RTS | UART CTS（硬件流控）
8 / 9 | VDD / VDDH | +1V8，C88 4.7µF | 两脚短接 → Normal Voltage 模式
10 | VBUS | GND | 不用 USB 时接地（按参考电路配置 6）
11–13 | DECUSB / D− / D+ | 悬空 | 不用 USB
14 | P0.15 | BLE_IRQ → STM32 EXTI | nRF 有数据时拉高，唤醒主控
15 | P0.17 | BLE_WAKE ← STM32 GPIO | 主控唤醒 nRF（配合 UART 低功耗）
16 | P0.18/nRESET | BLE_RESET_N ← STM32（开漏）+ TP3 | 需在 UICR.PSELRESET 中使能为复位脚；片内有上拉
17 | P0.20 | 悬空 | 备用 GPIO
18 | VDD | +1V8，C89 100nF
19 / 20 | SWDIO / SWDCLK | TP1 / TP2 | 烧录调试；SWDCLK 片内下拉、SWDIO 片内上拉
21 | DEC5 | C87 820pF（Bxx 版 DNP） | 仅 Bxx 之前的硅片版本需要，保留焊盘
22 / 23 | P0.09/NFC1 · P0.10/NFC2 | 悬空 | 不用 NFC；默认即 NFC 模式，悬空无影响
24 | ANT | C92 / L4 / C93 / L5 → π 匹配 → ANT1 | 50Ω 单端射频输出
25 | VSS_PA | GND | 功放地，就近打过孔
26 | DEC6 | DEC4_6 | 与 38 脚 DEC4 相连
27 | DEC3 | C84 100pF → GND
28 / 29 | XC1 / XC2 | X3 32MHz + C79/C80 12pF | 射频主时钟，必须外接
30 | VDD | +1V8，C90 100nF
31–36 | P0.03 / P0.02 / P0.28–P0.31 | 悬空 | 备用 GPIO / ADC
37 | VSS | GND
38 | DEC4 | DEC4_6：C85 1.0µF + C86 47nF | 1.3V 内核电源
39 | DCC | L6 10µH → L7 15nH → DEC4_6 | DC/DC 开关输出
40 | VDD | +1V8，C91 1.0µF
41 (EP) | VSS | GND | 裸焊盘，≥5 个过孔连到地平面

注意：DC/DC 打开（DCDCEN=1）之前必须已经贴好 L6/L7，否则芯片无法工作，连 SWD 都连不上。Normal 模式下 DC/DC 输入只有 1.8V，省电效果比 3V 供电时小；如果首版想简化，可以 L6/L7 不贴、固件不开 DC/DC，芯片用内部 LDO 照样能用。

## 5. 外围元件清单

位号 | 规格 | 封装 | 用途
U15 | nRF52833-QDAA-R（C2895249） | QFN40 5×5mm | BLE 5.1 SoC
X3 | 32MHz，CL=8pF，总误差 ±40ppm | 1612 或 2016 | 高频主时钟

X-Watch 蓝牙 nRF52833 原理图设计 Rev1.0 | 第 4 页
位号 | 规格 | 封装 | 用途
X4 | 32.768kHz，CL=9pF，±50ppm | 2012 | 低频时钟
C79, C80, C81, C82 | 12pF / NP0 / ±2% | 0201 | 晶振负载电容
C83 | 100nF / X7R | 0201 | DEC1
C84 | 100pF / NP0 | 0201 | DEC3
C85 | 1.0µF / X7R | 0402 | DEC4_6
C86 | 47nF / X7R | 0201 | DEC4_6（DC/DC 高频）
C87 | 820pF / X7R（Bxx 版 DNP） | 0201 | DEC5
C88 | 4.7µF / X7R / 6.3V | 0603 | VDD/VDDH 储能
C89, C90 | 100nF / X7R | 0201 | VDD 18、30 脚
C91 | 1.0µF / X7R | 0402 | VDD 40 脚
C92 | 1.0pF / NP0 / ±5% | 0201 | RF 匹配
C93 | 1.2pF / NP0 / ±5% | 0201 | RF 匹配
L4 | 4.7nH 高频电感 ±5% | 0201 | RF 匹配
L5 | 2.2nH 高频电感 ±5% | 0201 | RF 匹配
L6 | 10µH，IDC ≥ 50mA，±20% | 0603 | DC/DC 功率电感
L7 | 15nH 高频电感 ±10% | 0402 | DC/DC 高频滤波
C94, C95, R23 | π 调谐位：R23 = 0Ω，C94/C95 DNP | 0201 | 天线调谐，由网络分析仪实测 确定
ANT1 | 2.4GHz 贴片陶瓷天线（如 Johanson 2450AT18A100E） | 按选型 | 具体型号以立创库存为准
TP1–TP5 | Ø0.8–1.0mm 测试焊盘 | — | SWDIO / SWDCLK / RESET / +1V8 / GND

RF 匹配和去耦元件的封装按 Nordic 参考设计用 0201；匹配值和封装、走线有关，改成 0402 或改动布局后需要重新测试匹配。C87 是否需要，取决于采购批次的硅片版本：Nordic 说明 Bxx 及以后版本不需要，焊盘保留、默认不贴即可。

## 6. PCB 布局建议

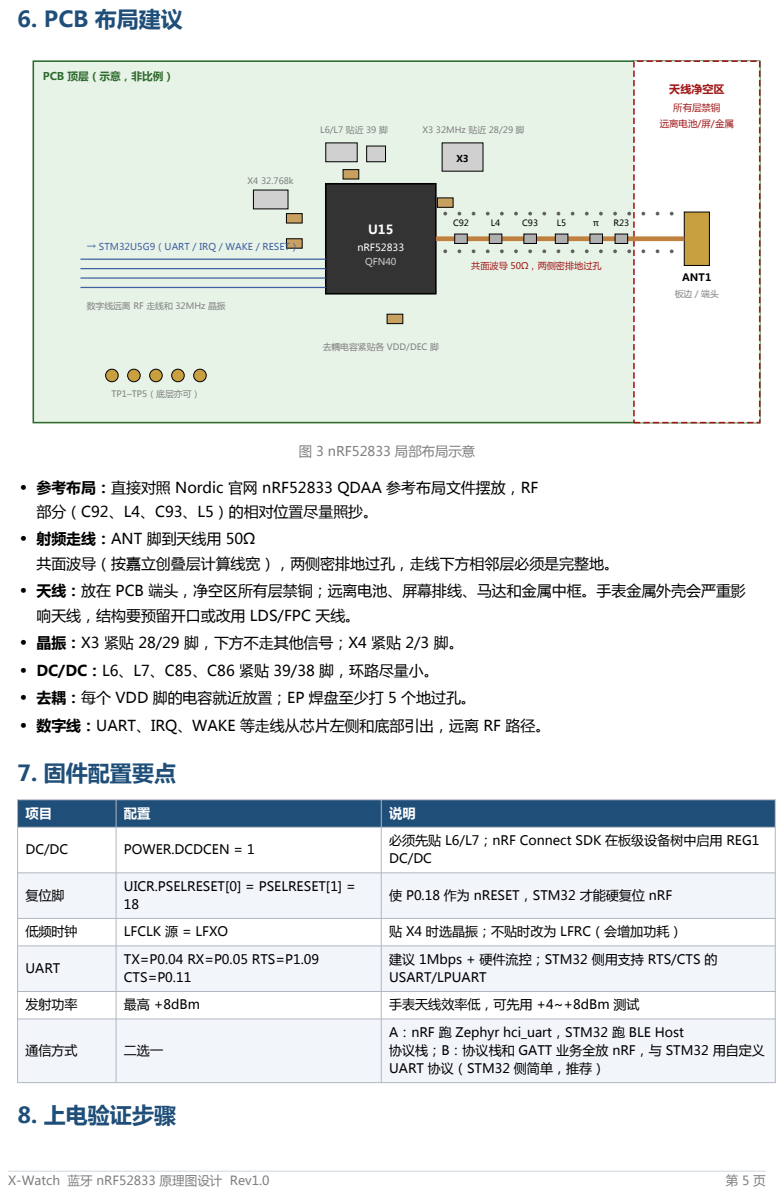
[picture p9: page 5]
X-Watch 蓝牙 nRF52833 原理图设计 Rev1.0; 天线净空区; 所有层禁铜; 远离电池/屏/金属; ANT1; nRF52833 QFN40; 共面波导 50Ω，两侧密排地过孔; X3 32MHz 贴近 28/29 脚; TP1–TP5（底层亦可）; 图 3 nRF52833 局部布局示意; 7. 固件配置要点; 8. 上电验证步骤

PCB 顶层（示意，非比例）

→ STM32U5G9（UART / IRQ / WAKE / RESET）

数字线远离 RF 走线和 32MHz 晶振

去耦电容紧贴各 VDD/DEC 脚

• 参考布局：直接对照 Nordic 官网 nRF52833 QDAA 参考布局文件摆放，RF
部分（C92、L4、C93、L5）的相对位置尽量照抄。
• 射频走线：ANT 脚到天线用 50Ω
共面波导（按嘉立创叠层计算线宽），两侧密排地过孔，走线下方相邻层必须是完整地。
• 天线：放在 PCB 端头，净空区所有层禁铜；远离电池、屏幕排线、马达和金属中框。手表金属外壳会严重影
响天线，结构要预留开口或改用 LDS/FPC 天线。
• 晶振：X3 紧贴 28/29 脚，下方不走其他信号；X4 紧贴 2/3 脚。
• DC/DC：L6、L7、C85、C86 紧贴 39/38 脚，环路尽量小。
• 去耦：每个 VDD 脚的电容就近放置；EP 焊盘至少打 5 个地过孔。
• 数字线：UART、IRQ、WAKE 等走线从芯片左侧和底部引出，远离 RF 路径。

DC/DC | POWER.DCDCEN = 1 | 必须先贴 L6/L7；nRF Connect SDK 在板级设备树中启用 REG1 DC/DC

复位脚 | UICR.PSELRESET[0] = PSELRESET[1] = 18 | 使 P0.18 作为 nRESET，STM32 才能硬复位 nRF

低频时钟 | LFCLK 源 = LFXO | 贴 X4 时选晶振；不贴时改为 LFRC（会增加功耗）

UART | TX=P0.04 RX=P0.05 RTS=P1.09 CTS=P0.11 | 建议 1Mbps + 硬件流控；STM32 侧用支持 RTS/CTS 的 USART/LPUART

发射功率 | 最高 +8dBm | 手表天线效率低，可先用 +4~+8dBm 测试

通信方式 | 二选一 | A：nRF 跑 Zephyr hci_uart，STM32 跑 BLE Host 协议栈；B：协议栈和 GATT 业务全放 nRF，与 STM32 用自定义 UART 协议（STM32 侧简单，推荐）

X-Watch 蓝牙 nRF52833 原理图设计 Rev1.0 | 第 6 页
步骤 | 操作 | 预期结果
1 | 不上电，量 +1V8 对地、DEC4_6 对地电阻 | 无短路
2 | 上电，量 8/9/18/30/40 脚电压 | ≈ 1.8V
3 | 量 DEC4（38 脚） | 约 1.3V
4 | 用 J-Link / nRF 调试器经 TP1–TP5 连接，nrfjprog --deviceversion 读芯片型号 | 能识别 nRF52833
5 | 烧录测试固件，确认 32MHz 和 32.768kHz 晶振起振 | HFXO / LFXO 启动成功
6 | 烧录 Beacon 例程，手机 nRF Connect App 扫描 | 能扫到设备；RSSI 与 DK 板对比
7 | 网络分析仪测天线回损，调整 C94/R23/C95 | 2.40–2.48GHz 内 S11 ≤ −10dB
8 | STM32 与 nRF 互发 UART 数据，测试 IRQ / WAKE / RESET | 收发正常，复位有效

## 9. 参考资料

- Nordic nRF52833 Product Specification v1.7，第 7.3.11、7.3.12 节（QDAA QFN40 参考电路配置 5、6）
- Nordic nRF52833 QDAA 参考布局：nordicsemi.com → nRF52833 → Downloads
- 立创商城 nRF52833-QDAA-R：编号 C2895249
- X-Watch 电源模块接线设计 Rev2.0、STM32U5G9 电源域原理图设计 Rev2.0（docs/hardware）

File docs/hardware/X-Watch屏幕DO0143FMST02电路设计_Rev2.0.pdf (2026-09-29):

# X-Watch 屏幕 DO0143FMST02 电路设计（Rev2.0）

## 设计要点

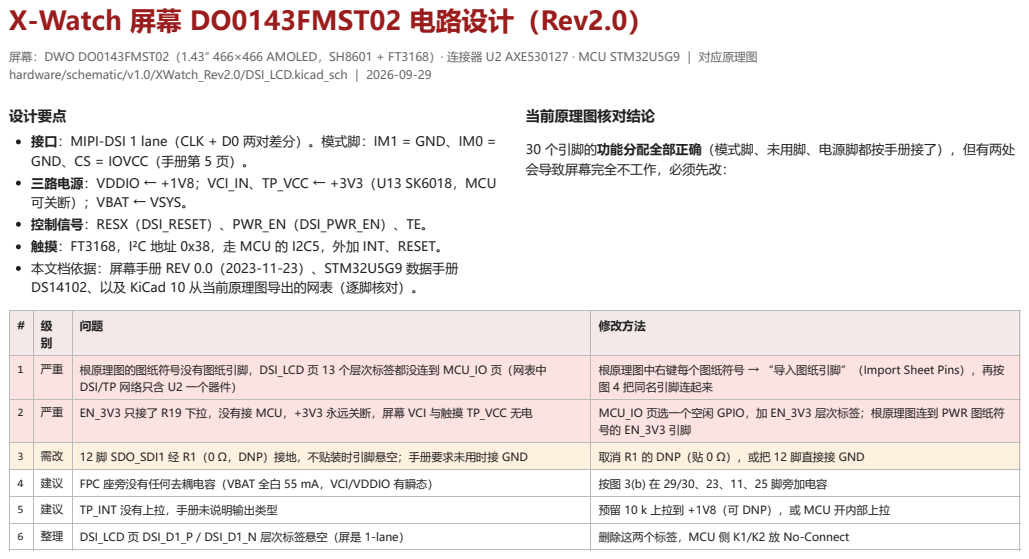
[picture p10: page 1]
当前原理图核对结论

屏幕：DWO DO0143FMST02（1.43″ 466×466 AMOLED，SH8601 + FT3168）· 连接器 U2 AXE530127 · MCU STM32U5G9 ｜ 对应原理图
hardware/schematic/v1.0/XWatch_Rev2.0/DSI_LCD.kicad_sch ｜ 2026-09-29

接口：MIPI-DSI 1 lane（CLK + D0 两对差分）。模式脚：IM1 = GND、IM0 =
GND、CS = IOVCC（手册第 5 页）。
三路电源：VDDIO ← +1V8；VCI_IN、TP_VCC ← +3V3（U13 SK6018，MCU
可关断）；VBAT ← VSYS。
控制信号：RESX（DSI_RESET）、PWR_EN（DSI_PWR_EN）、TE。
触摸：FT3168，I²C 地址 0x38，走 MCU 的 I2C5，外加 INT、RESET。
本文档依据：屏幕手册 REV 0.0（2023-11-23）、STM32U5G9 数据手册
DS14102、以及 KiCad 10 从当前原理图导出的网表（逐脚核对）。

30 个引脚的功能分配全部正确（模式脚、未用脚、电源脚都按手册接了），但有两处
会导致屏幕完全不工作，必须先改：

# | 级 别 | 问题 | 修改方法

1 | 严重 | 根原理图的图纸符号没有图纸引脚，DSI_LCD 页 13 个层次标签都没连到 MCU_IO 页（网表中 DSI/TP 网络只含 U2 一个器件） | 根原理图中右键每个图纸符号 → “导入图纸引脚”（Import Sheet Pins），再按 图 4 把同名引脚连起来

2 | 严重 | EN_3V3 只接了 R19 下拉，没有接 MCU，+3V3 永远关断，屏幕 VCI 与触摸 TP_VCC 无电 | MCU_IO 页选一个空闲 GPIO，加 EN_3V3 层次标签；根原理图连到 PWR 图纸符 号的 EN_3V3 引脚

3 | 需改 | 12 脚 SDO_SDI1 经 R1（0 Ω，DNP）接地，不贴装时引脚悬空；手册要求未用时接 GND | 取消 R1 的 DNP（贴 0 Ω），或把 12 脚直接接 GND
4 | 建议 | FPC 座旁没有任何去耦电容（VBAT 全白 55 mA，VCI/VDDIO 有瞬态） | 按图 3(b) 在 29/30、23、11、25 脚旁加电容
5 | 建议 | TP_INT 没有上拉，手册未说明输出类型 | 预留 10 k 上拉到 +1V8（可 DNP），或 MCU 开内部上拉
6 | 整理 | DSI_LCD 页 DSI_D1_P / DSI_D1_N 层次标签悬空（屏是 1-lane） | 删除这两个标签，MCU 侧 K1/K2 放 No-Connect

## 图 1 · 屏幕子系统框图

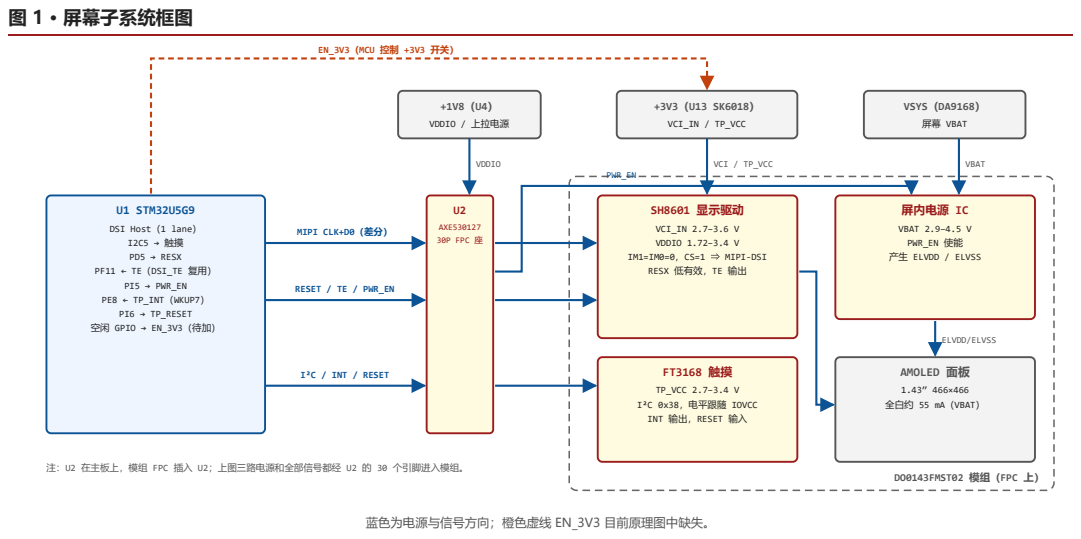
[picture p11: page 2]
U1 STM32U5G9; DSI Host（1 lane） I2C5 → 触摸 PD5 → RESX PF11 ← TE（DSI_TE 复用） PI5 → PWR_EN PE8 ← TP_INT（WKUP7） PI6 → TP_RESET 空闲 GPIO → EN_3V3（待加）; VDDIO / 上拉电源; VCI_IN / TP_VCC; VSYS（DA9168）; 屏幕 VBAT; AXE530127 30P FPC 座; DO0143FMST02 模组（FPC 上）; SH8601 显示驱动; 屏内电源 IC; AMOLED 面板; RESET / TE / PWR_EN; PWR_EN; VDDIO; VCI / TP_VCC; VBAT; ELVDD/ELVSS

EN_3V3（MCU 控制 +3V3 开关）

MIPI CLK+D0（差分）

VCI_IN 2.7–3.6 V
VDDIO 1.72–3.4 V
IM1=IM0=0，CS=1 ⇒ MIPI-DSI
RESX 低有效，TE 输出

VBAT 2.9–4.5 V
PWR_EN 使能
产生 ELVDD / ELVSS

I²C / INT / RESET

TP_VCC 2.7–3.4 V
I²C 0x38，电平跟随 IOVCC
INT 输出，RESET 输入

全白约 55 mA（VBAT）

注：U2 在主板上，模组 FPC 插入 U2；上图三路电源和全部信号都经 U2 的 30 个引脚进入模组。

蓝色为电源与信号方向；橙色虚线 EN_3V3 目前原理图中缺失。

## 图 2 · U2 FPC 座 30 脚完整接线

D0 差分对
100 Ω

CLK 差分对
100 Ω

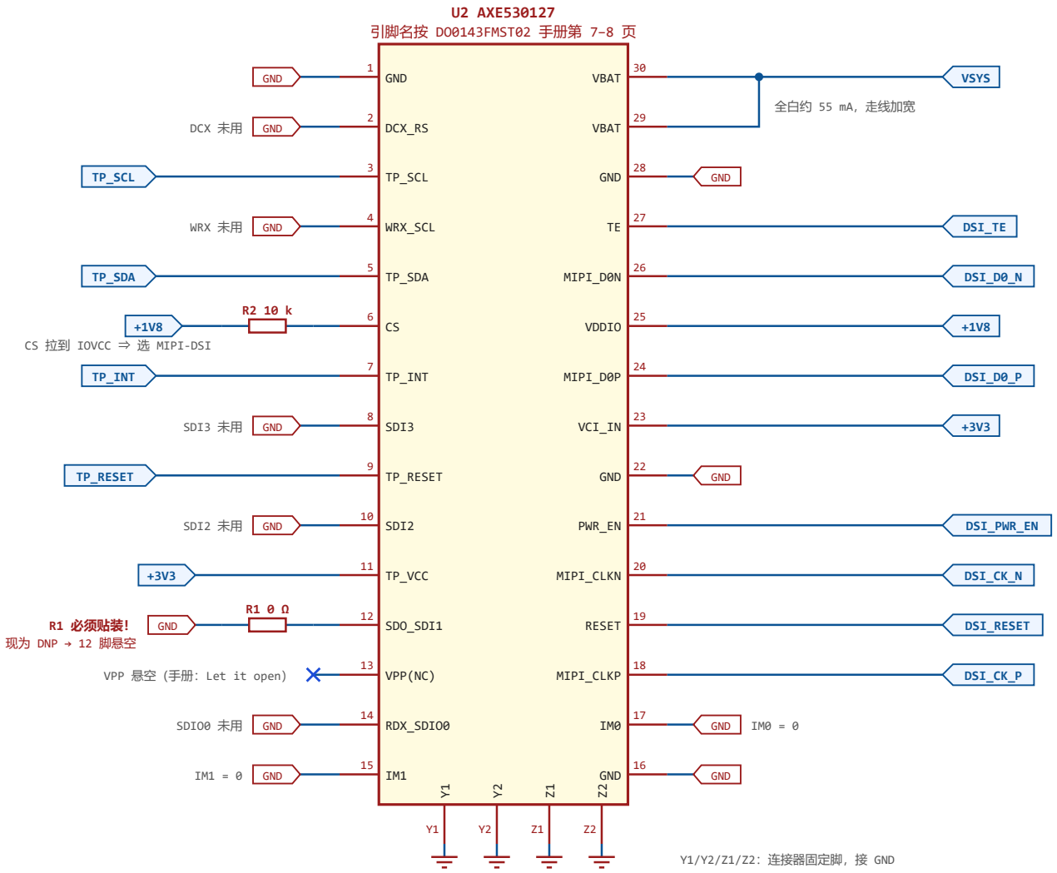
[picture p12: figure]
U2 AXE530127 引脚名按 DO0143FMST02 手册第 7–8 页; GND; DCX_RS; TP_SCL; WRX_SCL; TP_SDA; TP_INT; SDI3; TP_RESET; SDI2; TP_VCC; SDO_SDI1; VPP(NC); RDX_SDIO0; VBAT; MIPI_D0N; VDDIO; MIPI_D0P; VCI_IN; PWR_EN; MIPI_CLKN; RESET; MIPI_CLKP; DCX 未用; WRX 未用; SDI3 未用; SDI2 未用; SDIO0 未用; +1V8 CS 拉到 IOVCC ⇒ 选 MIPI-DSI; R1 必须贴装！; 现为 DNP → 12 脚悬空; VPP 悬空（手册：Let it open）; VSYS; 全白约 55 mA，走线加宽; DSI_TE; DSI_D0_N; DSI_D0_P; DSI_PWR_EN; DSI_CK_N; DSI_RESET; DSI_CK_P; Y1/Y2/Z1/Z2：连接器固定脚，接 GND

模式选择（手册第 5 页）：IM1 = GND、IM0 = GND、CS = IOVCC ⇒ MIPI-DSI；其余并口/SPI 数据脚未用时接 GND

引脚排布与 DSI_LCD.kicad_sch 中 U2 符号一致（左 1–15，右 30–16）；框内为屏幕手册引脚名。蓝色旗形框为网络/层次标签，红色 GND 框为接地。

## 图 3 · 触摸上拉 / FPC 座旁去耦 / +3V3 LDO

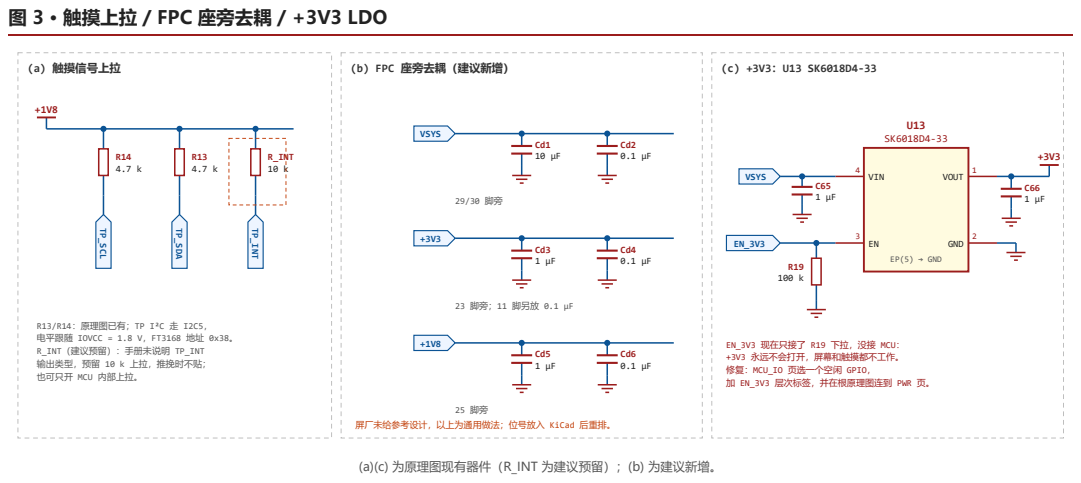
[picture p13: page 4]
(a) 触摸信号上拉; (b) FPC 座旁去耦（建议新增）; TP_SCL; TP_SDA; R_INT 10 k; TP_INT; VSYS; VIN; VOUT; GND; EP(5) → GND

23 脚旁；11 脚另放 0.1 µF

R13/R14：原理图已有；TP I²C 走 I2C5，
电平跟随 IOVCC = 1.8 V，FT3168 地址 0x38。
R_INT（建议预留）：手册未说明 TP_INT
输出类型，预留 10 k 上拉，推挽时不贴；
也可只开 MCU 内部上拉。

EN_3V3 现在只接了 R19 下拉，没接 MCU：
+3V3 永远不会打开，屏幕和触摸都不工作。
修复：MCU_IO 页选一个空闲 GPIO，
加 EN_3V3 层次标签，并在根原理图连到 PWR 页。

屏厂未给参考设计，以上为通用做法；位号放入 KiCad 后重排。

(a)(c) 为原理图现有器件（R_INT 为建议预留）；(b) 为建议新增。

## 图 4 · 跨页连接（根原理图需补的连线）

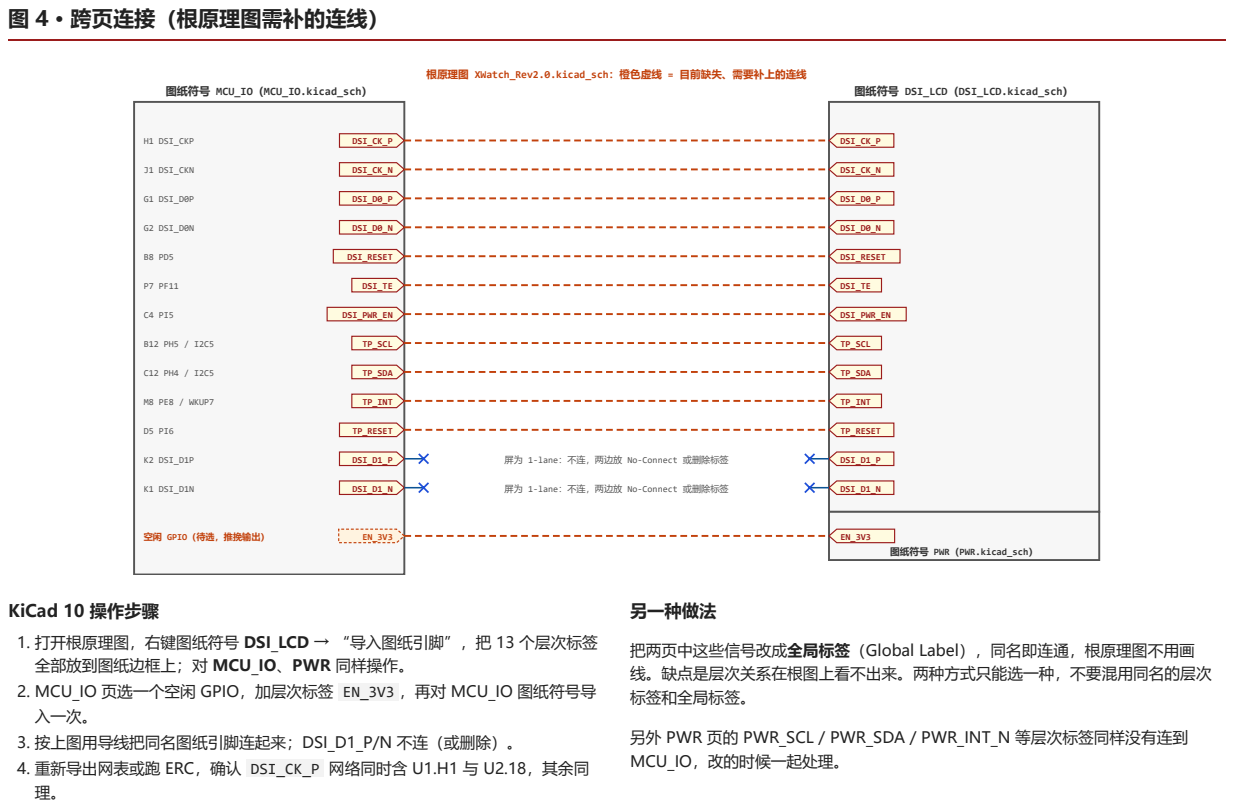
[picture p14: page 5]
图纸符号 MCU_IO（MCU_IO.kicad_sch）; 图纸符号 DSI_LCD（DSI_LCD.kicad_sch）; H1 DSI_CKP; DSI_CK_P; J1 DSI_CKN; DSI_CK_N; G1 DSI_D0P; DSI_D0_P; G2 DSI_D0N; DSI_D0_N; DSI_RESET; DSI_TE; DSI_PWR_EN; TP_SCL; TP_SDA; M8 PE8 / WKUP7; TP_INT; TP_RESET; K2 DSI_D1P; DSI_D1_P; 屏为 1-lane：不连，两边放 No-Connect 或删除标签; K1 DSI_D1N; DSI_D1_N; 空闲 GPIO（待选，推挽输出）; 2. MCU_IO 页选一个空闲 GPIO，加层次标签; EN_3V3 ，再对 MCU_IO 图纸符号导; 4. 重新导出网表或跑 ERC，确认; 网络同时含 U1.H1 与 U2.18，其余同; 另一种做法

根原理图 XWatch_Rev2.0.kicad_sch：橙色虚线 = 目前缺失、需要补上的连线

图纸符号 PWR（PWR.kicad_sch）

KiCad 10 操作步骤
1. 打开根原理图，右键图纸符号 DSI_LCD → “导入图纸引脚”，把 13 个层次标签
全部放到图纸边框上；对 MCU_IO、PWR 同样操作。
入一次。
3. 按上图用导线把同名图纸引脚连起来；DSI_D1_P/N 不连（或删除）。

把两页中这些信号改成全局标签（Global Label），同名即连通，根原理图不用画
线。缺点是层次关系在根图上看不出来。两种方式只能选一种，不要混用同名的层次
标签和全局标签。

另外 PWR 页的 PWR_SCL / PWR_SDA / PWR_INT_N 等层次标签同样没有连到
MCU_IO，改的时候一起处理。

## 图 5 · 屏幕上电 / 下电时序（依据屏幕手册 8.1 节）

+1V8（VDDI）

EN_3V3 / +3V3（VCI）

VSYS（VBAT）

DSI_RESET（RESX）

MIPI 链路

DSI_PWR_EN（PWR_EN）

上电（亮屏）

LP11+初始化 SLPOUT | DISPON

≥10 ms

≥20 ms

≥50 ms

+1 帧

下电（熄屏断电）

DISPOFF SLPIN

≥5 帧（60 Hz ≥83 ms）

≥0

+1V8 与 VSYS 常开，不参与屏幕开关

## 复位参数（手册 7-1 节）

参数 | 符号 | 要求
复位低脉宽 | tRW | ≥ 10 µs
复位完成时间（Sleep In 中复位） | tSRT | ≤ 5 ms
复位完成时间（Sleep Out 中复位） | tSRT | ≤ 150 ms
不响应的毛刺宽度 | tET | ≤ 5 µs

## 固件顺序（摘要）

EN_3V3 = 1 | // +3V3 上电，+1V8 常开
delay ≥ 10 ms
DSI_RESET = 1 | // 释放复位（此前保持 0）
delay ≥ 20 ms ; DSI 进入 LP11，发初始化序列 + SLPOUT delay ≥ 50 ms ; DISPON
wait 1 frame ; DSI_PWR_EN = 1 // 打开 ELVDD/ELVSS -- 熄屏 --
DISPOFF ; SLPIN ; DSI_PWR_EN = 0
delay ≥ 83 ms ; DSI_RESET = 0 ; EN_3V3 = 0

## 逐脚核对表（手册 vs 当前原理图网表）

脚 | 手册引脚 | 手册要求 | 当前原理图 | 结论
1 | GND | 地 | GND | ✔ 正确
3 | TP_SCL | 触摸 I²C 时钟，电平跟 随 IOVCC | TP_SCL，R14 4.7 k→+1V8 | ⚠ 未连到 MCU（见图 4）
5 | TP_SDA | 触摸 I²C 数据 | TP_SDA，R13 4.7 k→+1V8 | ⚠ 未连到 MCU
7 | TP_INT | 触摸中断输出 | TP_INT | ⚠ 未连 MCU；建议预 留上拉
9 | TP_RESET | 触摸复位输入 | TP_RESET | ⚠ 未连到 MCU
11 | TP_VCC | 2.7–3.4 V | +3V3 | ⚠ +3V3 不会打开 （EN_3V3）
13 | VPP(NC) | OTP 电源，悬空 | 未连（NC） | ✔ 正确
15 | IM1 | MIPI：接 GND | GND | ✔ 正确
17 | IM0 | MIPI：接 GND | GND | ✔ 正确
19 | RESET | AMOLED 复位 （RESX） | DSI_RESET | ⚠ 未连到 MCU
21 | PWR_EN | 屏内电源 IC 使能 | DSI_PWR_EN | ⚠ 未连到 MCU
23 | VCI_IN | 2.7–3.6 V | +3V3 | ⚠ +3V3 不会打开 （EN_3V3）
25 | VDDIO | 1.72–3.4 V | +1V8 | ✔ 正确
脚 | 手册引脚 | 手册要求 | 当前原理图 | 结论
2 | DCX_RS | SPI 用，MIPI 下不用 | GND | ✔ 正确
4 | WRX_SCL | SPI 用，MIPI 下不用 | GND | ✔ 正确
6 | CS | MIPI：接 IOVCC | R2 10 k → +1V8 | ✔ 正确
8 | SDI3 | 未用接 GND | GND | ✔ 正确
10 | SDI2 | 未用接 GND | GND | ✔ 正确
12 | SDO_SDI1 | 未用接 GND | R1 0 Ω（DNP）→ GND | ✘ R1 不贴 ⇒ 悬空
14 | RDX_SDIO0 | 未用接 GND | GND | ✔ 正确
16 | GND | 地 | GND | ✔ 正确
18 | MIPI_CLKP | DSI 时钟 + | DSI_CK_P | ⚠ 未连到 MCU
20 | MIPI_CLKN | DSI 时钟 − | DSI_CK_N | ⚠ 未连到 MCU
22 | GND | 地 | GND | ✔ 正确
24 | MIPI_D0P | DSI 数据 0 + | DSI_D0_P | ⚠ 未连到 MCU
26 | MIPI_D0N | DSI 数据 0 − | DSI_D0_N | ⚠ 未连到 MCU
28 | GND | 地 | GND | ✔ 正确
30 | VBAT | 2.9–4.5 V | VSYS | ✔ 正确

### Y1/Y2/Z1/Z2（连接器固定脚）→ GND ✔。“未连到 MCU”的根因都是问题 1；修好层次连接后这些行全部变为 ✔。

## MCU 引脚分配（取自 MCU_IO 页现有标签）

信号 | MCU 球号 / 端口 | 方向 | 说明
DSI_CK_P / DSI_CK_N | H1 / J1（DSI_CKP / CKN） | MCU→屏 | DSI 专用引脚
DSI_D0_P / DSI_D0_N | G1 / G2（DSI_D0P / D0N） | 双向 | DSI 专用引脚；D0 在 LP 模式可回读
DSI_D1_P / DSI_D1_N | K2 / K1 | — | 屏为 1-lane，不用
DSI_RESET | B8（PD5） | MCU→屏 | 推挽输出，上电时保持低电平
DSI_TE | P7（PF11） | 屏→MCU | PF11 有 GFXTIM_TE/DSI_TE 复用；CubeMX 中确认后用硬件 TE
DSI_PWR_EN | C4（PI5） | MCU→屏 | 推挽输出，DISPON 之后拉高
TP_SCL / TP_SDA | B12（PH5）/ C12（PH4），I2C5 | 双向 | 开漏复用，上拉 R14/R13 在屏幕页
TP_INT | M8（PE8，WKUP7） | 屏→MCU | EXTI；可作为低功耗唤醒源（抬腕/点击亮屏）
TP_RESET | D5（PI6） | MCU→屏 | 推挽输出
EN_3V3 | 待选空闲 GPIO | MCU→LDO | 推挽输出；R19 保证 MCU 复位期间关断

### MCU 侧 DSI 电源已核对：VDDDSI(G5) → +1V8，VDD11DSI(H5) → VDD11，VSSDSI → GND，符合 DS14102 要求。

## 物料（屏幕部分）

位号 | 规格 | 状态 | 用途
U2 | Panasonic AXE530127（30P 板对板座） | 已有 | 屏幕 FPC 连接
U13 | SK6018D4-33（DFN1x1-4L） | 已有 | +3V3 LDO
C65 / C66 | 1 µF X5R | 已有 | U13 输入 / 输出
R19 | 100 kΩ | 已有 | EN_3V3 下拉
R2 | 10 kΩ | 已有 | CS → IOVCC
R1 | 0 Ω | 改为贴装 | SDO_SDI1 → GND
R13 / R14 | 4.7 kΩ | 已有 | TP I²C 上拉
R_INT | 10 kΩ（可 DNP） | 建议新增 | TP_INT 上拉
Cd1 / Cd2 | 10 µF 10 V / 0.1 µF | 建议新增 | VBAT(29/30) 去耦
Cd3 / Cd4 + 0.1 µF | 1 µF / 0.1 µF / 0.1 µF | 建议新增 | VCI(23) / TP_VCC(11) 去耦
Cd5 / Cd6 | 1 µF / 0.1 µF | 建议新增 | VDDIO(25) 去耦

## PCB 布局与 MIPI 布线

### 1. 差分阻抗 100 Ω（按板厂叠层计算线宽/线距），CLK 与 D0 两对都按差分对走

线。

2. 对内等长：P/N 长度差尽量 < 0.1 mm；对间 CLK 与 D0 长度差尽量 < 1 mm。 3. 参考平面保持完整的 GND，不跨分割；换层时在过孔旁加 GND 回流过孔，P/N 过孔对称。 4. 差分对远离 DC-DC 开关节点（U3 的 L1/CHG_LX、U4 的 L2/SW）和 32 kHz、 16 MHz 晶振。 5. U2 尽量靠近 MCU 的 DSI 球（G1/G2/H1/J1），走线越短越好；差分对之间及与 其他信号间距 ≥ 3 倍线宽。 6. VSYS 到 29/30 脚按 55 mA 以上加宽；去耦电容贴 U2 引脚放，地孔就近。 7. TP_SCL/SDA、RESET、TE 等低速信号与差分对分开走。

## 待确认事项

1. U2 封装引脚 1 的朝向：AXE530127 与屏 FPC 上的 AXE630124 面对面扣合， PCB 上 1 脚位置要对照屏幕外形图（手册第 6 页）和连接器规格书确认，避免左 右镜像。 2. TP_INT 输出类型（开漏/推挽）向屏厂确认，决定 R_INT 是否贴装。 3. 屏厂是否有 FPC 座旁去耦的参考设计；有则以其为准替换图 3(b)。 4. PF11 的 DSI_TE 复用在 CubeMX 中确认（本文依据数据手册引脚表）。 5. 熄屏策略：常亮/只睡眠时保持 EN_3V3 = 1、只发 SLPIN；彻底断电则按图 5 下 电时序。 6. 触摸 I²C（I2C5）上若还挂其他器件，确认地址不与 0x38 冲突，且上拉只保留一

组。

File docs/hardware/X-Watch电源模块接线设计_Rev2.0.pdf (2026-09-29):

# X-Watch 电源模块接线设计（Rev2.0）

器件：U3 DA9168 · U4 TPS62840DLCR · U5 MAX17048G+T10 · U7 SK6018D4-33 ｜ 对应原理图 hardware/schematic/v1.0/XWatch_Rev2.0/PWR.kicad_sch ｜ 2026-09-29 更新：新增 3.3 V LDO 与屏幕电源连接

### 设计目标

单节锂电池（3.0–4.2 V）供电，5 V 触点充电。
产生 +1V8 给 MCU（STM32U5G9）及全部 1.8 V 负载，最大 750 mA。
产生 +3V3 给 AMOLED 屏幕的 VCI_IN 与触摸 TP_VCC（<5 mA），可由 MCU 关断。
通过 I²C 读取充电状态（DA9168）和电量（MAX17048）。

### 四颗芯片的分工

U3 DA9168：充电器 + 动态电源路径，输出系统母线 VSYS 。 U4 TPS62840： VSYS → +1V8 ，VSET 接地即 1.8 V，无需反馈 电阻。
U5 MAX17048：直接挂在电池 VBAT 上测量电量。
U7 SK6018D4-33： VSYS → +3V3 ，只给屏幕用，EN 由 MCU 控制。

### 为什么屏幕要单独一路 3.3 V

屏幕手册：VCI_IN 2.7–3.6 V、TP_VCC 2.7–3.4 V。1.8 V 不够；VSYS （最高约 4.5 V）又超上限，所以只能单独稳压。DA9168 的 VOUT1/VOUT2 由 VMID 供电，纯电池时需开反向升压（空载 25–60 µA），因此不用。

### 网络名约定（KiCad 中照此命名即可连通各页）

网络名 | 说明
VBUS | 充电触点 5 V 输入
VBAT | 电池正极（DA9168 VBAT、VBAT_SNS、MAX17048 CELL/VDD）
VSYS | DA9168 系统输出 → TPS62840 VIN、SK6018 VIN、屏幕 VBAT
+1V8 | TPS62840 输出，使用现有 power:+1V8 符号
+3V3 | SK6018D4-33 输出，屏幕 VCI_IN / TP_VCC，使用现有 power:+3V3 符号
BAT_NTC | 电池 NTC ↔ DA9168 TMP_SNS
PWR_SCL / PWR_SDA | 电源 I²C 总线（0x68 + 0x36）
PMIC_INT_N / FG_ALRT_N | 两个开漏中断，接 MCU EXTI
CHG_EN_N | 充电使能（低有效），可选接 MCU
LCD_3V3_EN | U7 使能（高有效），接 MCU GPIO
DSI_PWR_ON | 屏幕 PWR_EN（屏内 ELVDD/ELVSS 使能），原理图已有

## 图 1 · 电源树与信号关系

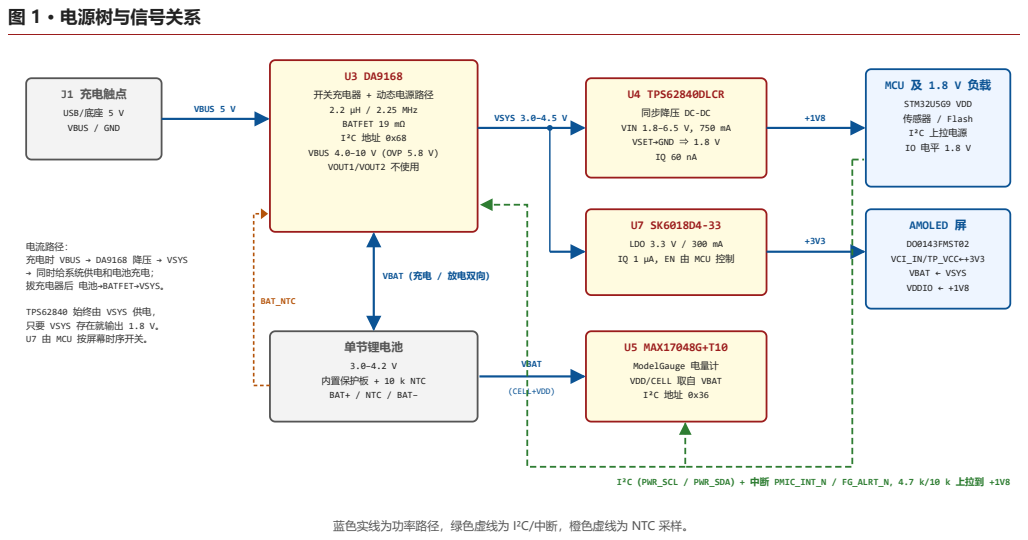
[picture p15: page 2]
J1 充电触点; USB/底座 5 V VBUS / GND; 开关充电器 + 动态电源路径 2.2 µH / 2.25 MHz BATFET 19 mΩ I²C 地址 0x68 VBUS 4.0–10 V (OVP 5.8 V) VOUT1/VOUT2 不使用; MCU 及 1.8 V 负载; STM32U5G9 VDD 传感器 / Flash I²C 上拉电源 IO 电平 1.8 V; AMOLED 屏; DO0143FMST02 VCI_IN/TP_VCC←+3V3 VBAT ← VSYS VDDIO ← +1V8; 单节锂电池; VBUS 5 V; VSYS 3.0–4.5 V; VBAT; (CELL+VDD); BAT_NTC

U4 TPS62840DLCR
同步降压 DC-DC
VIN 1.8–6.5 V, 750 mA
VSET→GND ⇒ 1.8 V

LDO 3.3 V / 300 mA
IQ 1 µA, EN 由 MCU 控制

电流路径：
充电时 VBUS → DA9168 降压 → VSYS
→ 同时给系统供电和电池充电；
拔充电器后 电池→BATFET→VSYS。

VBAT（充电 / 放电双向）

TPS62840 始终由 VSYS 供电，
只要 VSYS 存在就输出 1.8 V。
U7 由 MCU 按屏幕时序开关。

U5 MAX17048G+T10
ModelGauge 电量计
VDD/CELL 取自 VBAT
I²C 地址 0x36

内置保护板 + 10 k NTC
BAT+ / NTC / BAT−

I²C（PWR_SCL / PWR_SDA）+ 中断 PMIC_INT_N / FG_ALRT_N，4.7 k/10 k 上拉到 +1V8

蓝色实线为功率路径，绿色虚线为 I²C/中断，橙色虚线为 NTC 采样。

## 图 2 · U3 DA9168 完整接线

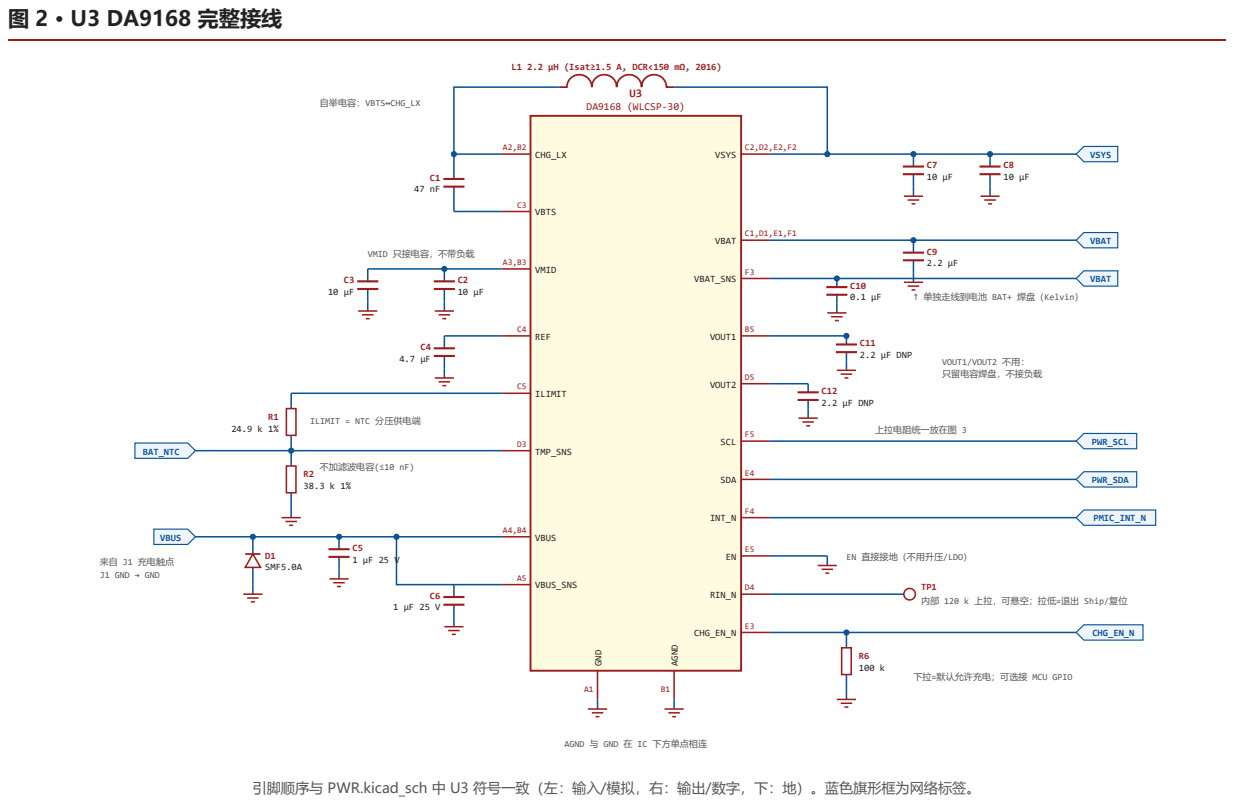
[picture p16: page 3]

L1 2.2 µH (Isat≥1.5 A, DCR<150 mΩ, 2016)

↑ 单独走线到电池 BAT+ 焊盘（Kelvin）

EN 直接接地（不用升压/LDO）

内部 120 k 上拉，可悬空；拉低=退出 Ship/复位

下拉=默认允许充电；可选接 MCU GPIO

AGND 与 GND 在 IC 下方单点相连

引脚顺序与 PWR.kicad_sch 中 U3 符号一致（左：输入/模拟，右：输出/数字，下：地）。蓝色旗形框为网络标签。

## 图 3 · U4 TPS62840 / U5 MAX17048 / 电池 / 上拉与 MCU

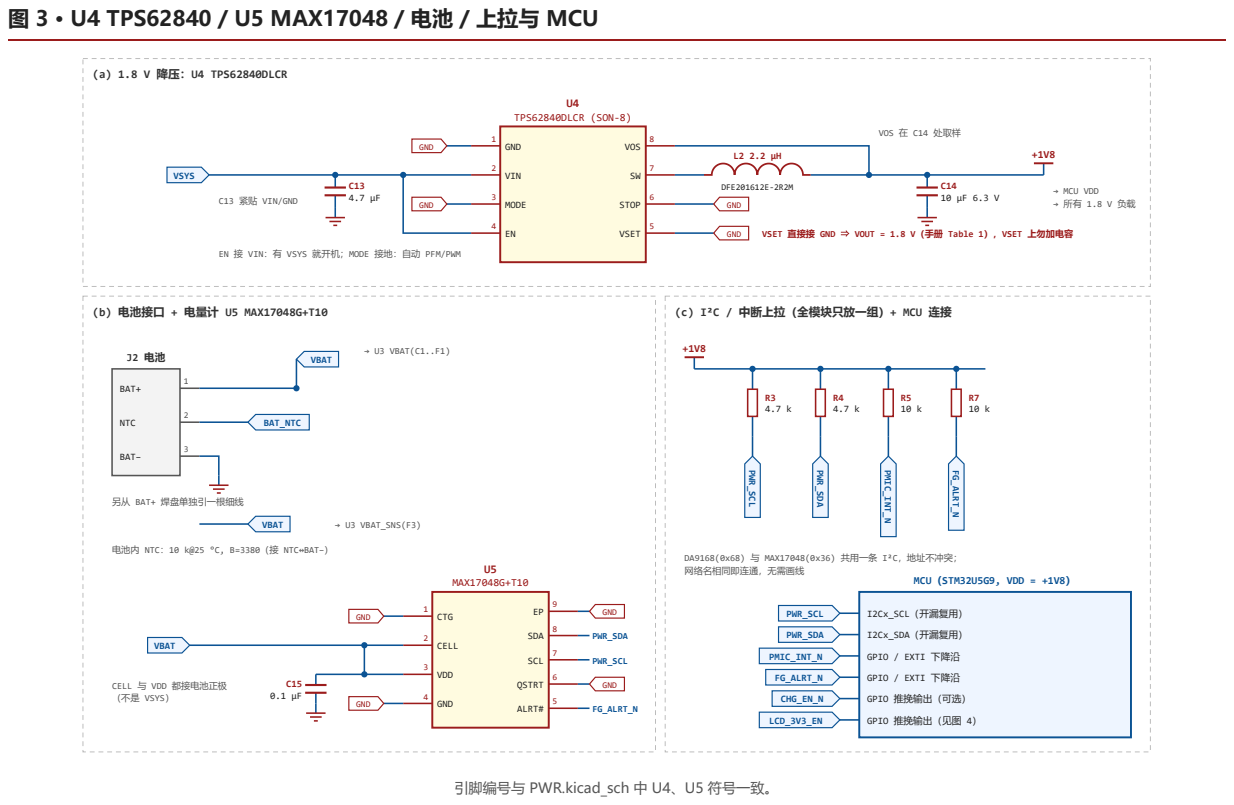
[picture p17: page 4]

EN 接 VIN：有 VSYS 就开机；MODE 接地：自动 PFM/PWM

电池内 NTC：10 k@25 °C, B=3380（接 NTC↔BAT−）

## 图 4 · U7 SK6018D4-33（+3V3）与屏幕电源连接

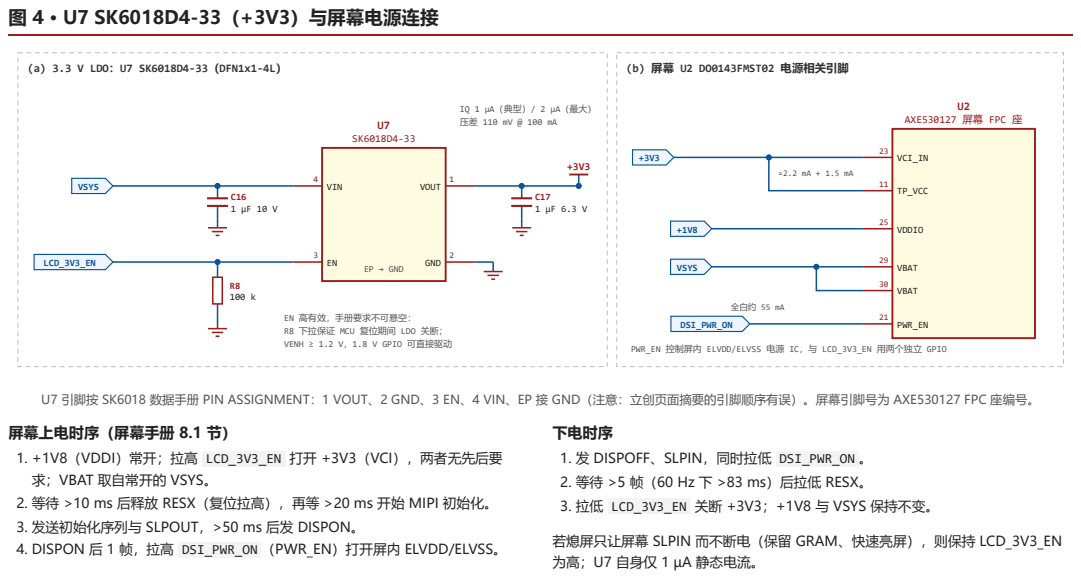
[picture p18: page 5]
(a) 3.3 V LDO：U7 SK6018D4-33（DFN1x1-4L）; (b) 屏幕 U2 DO0143FMST02 电源相关引脚; VIN; VOUT; GND; EP → GND; VSYS; LCD_3V3_EN; U2 AXE530127 屏幕 FPC 座; VCI_IN; TP_VCC; VDDIO; VBAT; PWR_EN; 全白约 55 mA; DSI_PWR_ON

EN 高有效，手册要求不可悬空：
R8 下拉保证 MCU 复位期间 LDO 关断；
VENH ≥ 1.2 V，1.8 V GPIO 可直接驱动

PWR_EN 控制屏内 ELVDD/ELVSS 电源 IC，与 LCD_3V3_EN 用两个独立 GPIO

U7 引脚按 SK6018 数据手册 PIN ASSIGNMENT：1 VOUT、2 GND、3 EN、4 VIN、EP 接 GND（注意：立创页面摘要的引脚顺序有误）。屏幕引脚号为 AXE530127 FPC 座编号。
屏幕上电时序（屏幕手册 8.1 节）
1. +1V8（VDDI）常开；拉高 LCD_3V3_EN 打开 +3V3（VCI），两者无先后要
求；VBAT 取自常开的 VSYS。
2. 等待 >10 ms 后释放 RESX（复位拉高），再等 >20 ms 开始 MIPI 初始化。
3. 发送初始化序列与 SLPOUT，>50 ms 后发 DISPON。
4. DISPON 后 1 帧，拉高 DSI_PWR_ON （PWR_EN）打开屏内 ELVDD/ELVSS。

下电时序
1. 发 DISPOFF、SLPIN，同时拉低 DSI_PWR_ON 。
2. 等待 >5 帧（60 Hz 下 >83 ms）后拉低 RESX。
3. 拉低 LCD_3V3_EN 关断 +3V3；+1V8 与 VSYS 保持不变。

若熄屏只让屏幕 SLPIN 而不断电（保留 GRAM、快速亮屏），则保持 LCD_3V3_EN
为高；U7 自身仅 1 µA 静态电流。

## 逐脚接线表 · U3 DA9168

球号 | 引脚 | 连接到 | 说明
A2, B2 | CHG_LX | L1(2.2 µH) 一端；C1(47 nF) 一端 | L1 另一端 → VSYS；C1 另一端 → VBTS。开关节点，铜皮尽量小
C3 | VBTS | C1(47 nF) → CHG_LX | 自举电容，紧贴 IC
A3, B3 | VMID | C2、C3 10 µF → GND | 仅接电容，不带任何负载
C4 | REF | C4 4.7 µF → GND | 电容紧贴 IC
C5 | ILIMIT | R1 24.9 k → TMP_SNS | 当前 OTP 下 ILIMIT 仅作 NTC 分压供电端（手册 Table 1 注）
D3 | TMP_SNS | R1 / R2 38.3 k→GND / BAT_NTC | 不要加 >10 nF 的滤波电容
A4, B4 | VBUS | J1 充电触点 +5 V；C5 1 µF；D1 TVS | 两个球都要连
A5 | VBUS_SNS | 接 VBUS；C6 1 µF
C2, D2, E2, F2 | VSYS | L1 另一端；C7、C8 10 µF；→ U4 VIN、U7 VIN、屏幕 VBAT | 四个球全部连通，宽铜皮
C1, D1, E1, F1 | VBAT | J2 BAT+；C9 2.2 µF；→ U5 CELL/VDD | 四个球全部连通，宽铜皮
F3 | VBAT_SNS | 单独细线到 BAT+ 焊盘；C10 0.1 µF | Kelvin 采样，保证 4.2 V ±0.5% 精度
B5 | VOUT1 | C11 2.2 µF（DNP） | 不使用，不接负载
D5 | VOUT2 | C12 2.2 µF（DNP） | 不使用，不接负载
F5 | SCL | PWR_SCL | R3 4.7 k 上拉到 +1V8（图 3c）
E4 | SDA | PWR_SDA | R4 4.7 k 上拉到 +1V8
F4 | INT_N | PMIC_INT_N | 开漏，R5 10 k 上拉到 +1V8
E5 | EN | GND | 只控制反向升压/LDO，本设计不用；内部下拉默认关闭，不能悬空
D4 | RIN_N | TP1（可选侧键到 GND） | 内部 120 k 上拉，可悬空
E3 | CHG_EN_N | R6 100 k → GND；可选接 MCU GPIO | 低电平允许充电
A1 | GND | GND 平面 | 功率地
B1 | AGND | GND | 与 GND 在 IC 下方单点相连

## 逐脚接线表 · U4 TPS62840DLCR

脚 | 引脚 | 连接到 | 说明
1 | GND | GND | C13、C14 地端就近回到此脚
2 | VIN | VSYS；C13 4.7 µF → GND | C13 是最关键的布局元件，贴脚放
3 | MODE | GND | 自动 PFM/PWM（轻载省电）；必须端接，不能悬 空
4 | EN | VIN（VSYS） | VSYS 上电即输出 1.8 V
5 | VSET | GND（直连） | TPS62840DLC：VSET=GND ⇒ 1.8 V；寄生电容 须 <100 pF
6 | STOP | GND | 正常开关工作
7 | SW | L2 2.2 µH → +1V8 | 开关节点，走线短
8 | VOS | +1V8（在 C14 焊盘处 取样） | 反馈脚，远离 SW/L2

## 逐脚接线表 · U5 MAX17048G+T10

脚 | 引脚 | 连接到 | 说明
1 | CTG | GND
2 | CELL | VBAT（电池正极） | 测电池电压，不要接 VSYS
3 | VDD | VBAT；C15 0.1 µF → GND | 供电范围 2.5–4.5 V
4 | GND | GND
5 | ALRT# | FG_ALRT_N | 开漏，R7 10 k 上拉到 +1V8
6 | QSTRT | GND | 不用快速启动
7 | SCL | PWR_SCL | 与 DA9168 共用总线
8 | SDA | PWR_SDA | 与 DA9168 共用总线
9 | EP | GND | 散热焊盘

## 逐脚接线表 · U7 SK6018D4-33

脚 | 引脚 | 连接到 | 说明
1 | VOUT | +3V3；C17 1 µF → GND | → 屏幕 VCI_IN(23)、 TP_VCC(11)
2 | GND | GND
3 | EN | LCD_3V3_EN（MCU GPIO）；R8 100 k → GND

高有效，不可悬空；VENH ≥
1.2 V
4 | VIN | VSYS；C16 1 µF → GND | 输入 2.5–6.5 V
EP | 散热焊盘 | GND

## 屏幕电源脚 · U2 DO0143FMST02

脚 | 引脚 | 连接到 | 说明
23 | VCI_IN | +3V3 | 显示驱动 SH8601 模拟电源，2.7–3.6 V
11 | TP_VCC | +3V3 | 触摸 FT3168 模拟电源，2.7–3.4 V（TP 表 2.8–3.6 V）
25 | VDDIO | +1V8 | IO 电平 1.72–3.4 V
29, 30 | VBAT | VSYS | 屏内 ELVDD/ELVSS 电源 IC，2.9–4.5 V； 不能接 VBUS
21 | PWR_EN | DSI_PWR_ON（MCU GPIO）

屏内电源 IC 使能，DISPON 之后再拉高

## MCU 需要的连接

网络 | MCU 侧 | 方向 | 说明
+1V8 | VDD / VDDA / VDDIO2 等 | 电源 | MCU_PWR 页已使用 +1V8 符号，直接相连
PWR_SCL | 任一 I2C 的 SCL | MCU→ | 可与传感器 I²C 共用：LSM6DSOX 0x6A/0x6B、LIS2MDL 0x1E 与 0x68/0x36 不冲突
PWR_SDA | 同一 I2C 的 SDA | 双向 | 上拉只保留一组（本模块 R3/R4），共用总线时别处不再重复上拉
PMIC_INT_N | GPIO + EXTI（下降沿） | →MCU | DA9168 发 256 µs 低脉冲，必须用边沿中断，轮询会漏
FG_ALRT_N | GPIO + EXTI（下降沿） | →MCU | 低电量/SOC 变化告警，电平保持直到清除
CHG_EN_N | GPIO 推挽（可选） | MCU→ | 不接则由 R6 下拉，充电始终允许（仍可用 I²C 的 CHG_EN 位关闭）
LCD_3V3_EN | GPIO 推挽 | MCU→ | 高=打开 +3V3；MCU 复位期间 IO 为高阻，由 R8 下拉保持关断
DSI_PWR_ON | GPIO 推挽（原理图已有） | MCU→ | 屏幕 PWR_EN，与 LCD_3V3_EN 分开，按时序先 +3V3 后 PWR_EN

## 物料清单（本模块）

位号 | 规格 | 封装 | 用途
U3 | DA9168-xxU72 | WLCSP-30 2.145×2.545 | 充电 + 电源路径
U4 | TPS62840DLCR | SON-8 1.5×2 | 1.8 V 降压
U5 | MAX17048G+T10 | TDFN-8 2×2 | 电量计
U7 | SK6018D4-33（立创 C2682758） | DFN1x1-4L | 3.3 V LDO（屏 幕）
L1 | 2.2 µH, Isat≥1.5 A, DCR<150 mΩ | 2016 | DA9168 充电电 感
L2 | 2.2 µH, 如 Murata DFE201612E-2R2M | 2016 | TPS62840 电感
C1 | 47 nF X7R 10 V | 0201/0402 | VBTS
C2, C3 | 10 µF X5R 6.3 V | 0402 | VMID
C4 | 4.7 µF X5R 6.3 V | 0402 | REF
C5, C6 | 1 µF X5R 25 V | 0402 | VBUS / VBUS_SNS
C7, C8 | 10 µF X5R 10 V | 0603 | VSYS
C9 | 2.2 µF X5R 6.3 V | 0402 | VBAT
位号 | 规格 | 封装 | 用途
C13 | 4.7 µF X5R 10 V | 0402 | U4 输入
C14 | 10 µF X5R 6.3 V | 0402 | U4 输出（+1V8）
C15 | 0.1 µF X7R | 0201/0402 | U5 VDD
C16 | 1 µF X5R 10 V | 0201/0402 | U7 输入
C17 | 1 µF X5R 6.3 V | 0201/0402 | U7 输出（+3V3）
R1 | 24.9 kΩ 1% | 0201/0402 | NTC 分压 R_HI
R2 | 38.3 kΩ 1% | 0201/0402 | NTC 分压 R_LO
R3, R4 | 4.7 kΩ | 0201/0402 | I²C 上拉
R5, R7 | 10 kΩ | 0201/0402 | INT_N / ALRT# 上拉
R6 | 100 kΩ | 0201/0402 | CHG_EN_N 下拉
R8 | 100 kΩ | 0201/0402 | LCD_3V3_EN 下拉
D1 | SMF5.0A 或同类 5 V TVS | SOD-123FL | VBUS 浪涌
TP1 | 测试点 | — | RIN_N
J1 / J2 | 充电触点 / 电池座 | — | 按结构定

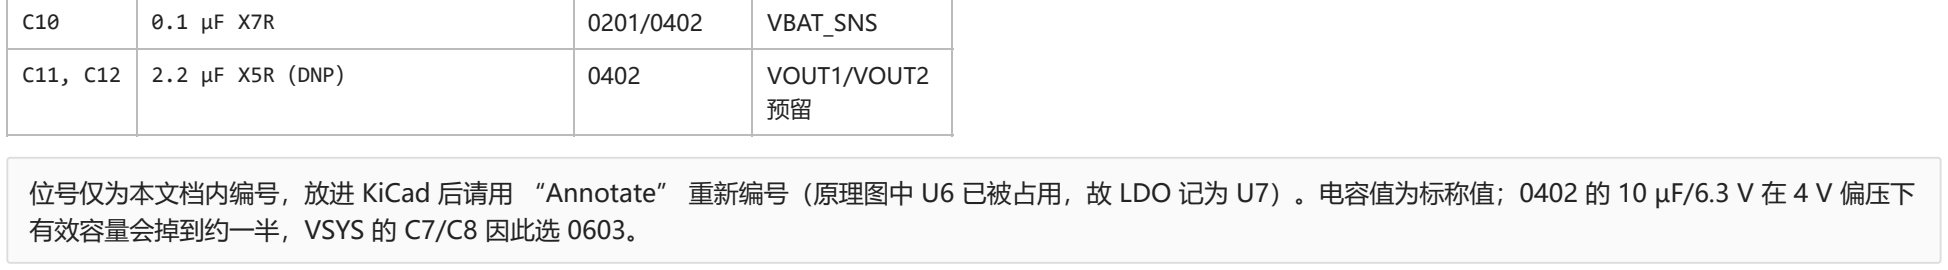
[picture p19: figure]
VBAT_SNS; 2.2 µF X5R（DNP）; VOUT1/VOUT2 预留; 有效容量会掉到约一半，VSYS 的 C7/C8 因此选 0603。

位号仅为本文档内编号，放进 KiCad 后请用 “Annotate” 重新编号（原理图中 U6 已被占用，故 LDO 记为 U7）。电容值为标称值；0402 的 10 µF/6.3 V 在 4 V 偏压下

## 关键参数计算

### 1. 输出电压 1.8 V

TPS62840DLC 的 VSET 表（手册 Table 1）中 VSET 电阻 = GND（<10 Ω）对应 1.8 V。所以 VSET 直接接地，不用电阻。电压只在上电启动时读取一次。

### 2. NTC 分压（R1、R2）

DA9168 温度门限为 REF 电压的固定百分比：T_LO 39.8 %、T_COOL 36 %、 T_WARM 20.5 %、T_HI 15 %。以 10 k/B3380 NTC、充电窗口 0–45 °C 计算（R(0 °C)=28.2 k，R(45 °C)=4.90 k）：

R_LO = Rc·Rh·(1/0.398−1/0.15) / [Rh·(1/0.15−1) − Rc·(1/0.398−1)] = 38.6 k
R_HI = (1/0.398−1) / (1/R_LO + 1/Rc) = 24.7 k

取 E96：R2 = 38.3 k，R1 = 24.9 k。电池 NTC 参数不同时需重算。

### 3. 电流能力

TPS62840 最大 750 mA，对 MCU + 1.8 V 外设有充足余量。 SK6018D4-33 最大 300 mA；屏幕 VCI 约 2.2 mA + 触摸约 1.5 mA，余量约 60 倍。
U7 压差 110 mV @ 100 mA，在 5 mA 下仅几 mV：VSYS ≥ 约 3.35 V 时稳在 3.3 V；更低时输出≈VSYS，直到 VSYS ≈ 2.8 V 仍满足 VCI/TP_VCC 下限。 U7 损耗 (4.2−3.3) V × 5 mA ≈ 4.5 mW，可忽略。

## 上电与工作状态

状态 | VSYS | +1V8 | +3V3 | 说明
只插电池 | ≈VBAT | 有 | MCU 控 制 | BATFET 导通，电池直接供 VSYS
插充电器 | VSYS_MIN~4.5 V | 有 | MCU 控 制 | 充电同时给系统供电
MCU 复位中 | 有 | 有 | 关 | R8 下拉使 U7 关断
Ship 模式 | 0 | 无 | 无 | 整机 <1 µA；插充电器或拉低 RIN_N 退出
MAX17048 | — | — | — | 由 VBAT 直接供电，Ship 模式下仍 在（约 3 µA）

## 上电后软件初始化（摘要）

DA9168（0x68）：先读 OTP_VARIANT_ID(0x0043) 确认 OTP 版本；按电池规 格写充电电流 CHG_ICHG 、终止电压 CHG_VBATREG （4.20 V）、输入限流 IINDPM ；清中断并按需配置 MASK。
MAX17048（0x36）：读 VERSION 确认通信；按电池写 RCOMP ，设置 CONFIG.ATHD 低电量告警阈值。
屏幕：按图 4 下方时序操作 LCD_3V3_EN → RESX → MIPI 初始化 → DISPON → DSI_PWR_ON。
详细寄存器表见 X-WatchDA9168电源子系统设计_Rev1.0.pdf 第 8 节。

## PCB 布局要点

## 接线自检清单

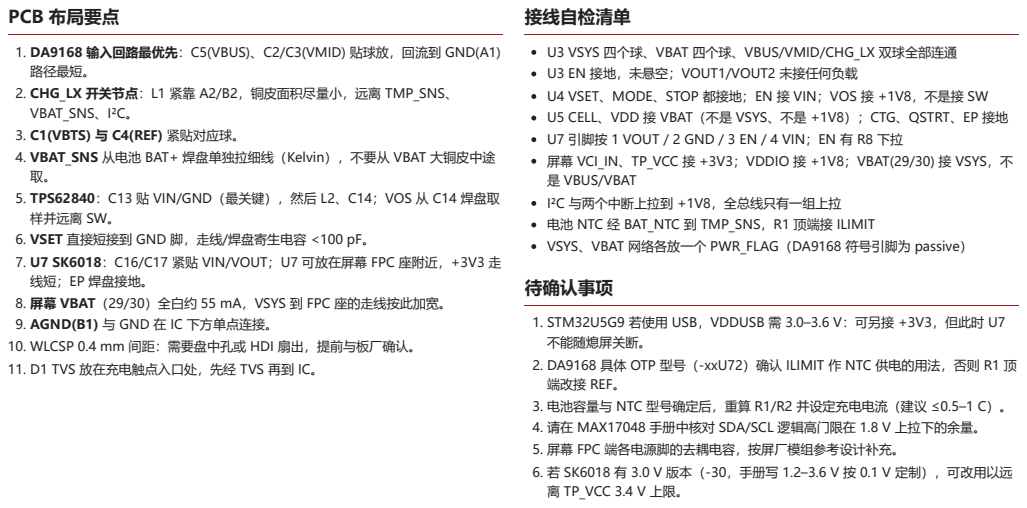
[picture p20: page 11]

1. DA9168 输入回路最优先：C5(VBUS)、C2/C3(VMID) 贴球放，回流到 GND(A1)
路径最短。
2. CHG_LX 开关节点：L1 紧靠 A2/B2，铜皮面积尽量小，远离 TMP_SNS、
VBAT_SNS、I²C。
3. C1(VBTS) 与 C4(REF) 紧贴对应球。
4. VBAT_SNS 从电池 BAT+ 焊盘单独拉细线（Kelvin），不要从 VBAT 大铜皮中途
5. TPS62840：C13 贴 VIN/GND（最关键），然后 L2、C14；VOS 从 C14 焊盘取
样并远离 SW。
6. VSET 直接短接到 GND 脚，走线/焊盘寄生电容 <100 pF。
7. U7 SK6018：C16/C17 紧贴 VIN/VOUT；U7 可放在屏幕 FPC 座附近，+3V3 走
线短；EP 焊盘接地。
8. 屏幕 VBAT（29/30）全白约 55 mA，VSYS 到 FPC 座的走线按此加宽。
9. AGND(B1) 与 GND 在 IC 下方单点连接。
10. WLCSP 0.4 mm 间距：需要盘中孔或 HDI 扇出，提前与板厂确认。
11. D1 TVS 放在充电触点入口处，先经 TVS 再到 IC。

U3 VSYS 四个球、VBAT 四个球、VBUS/VMID/CHG_LX 双球全部连通
U3 EN 接地，未悬空；VOUT1/VOUT2 未接任何负载
U4 VSET、MODE、STOP 都接地；EN 接 VIN；VOS 接 +1V8，不是接 SW
U5 CELL、VDD 接 VBAT（不是 VSYS、不是 +1V8）；CTG、QSTRT、EP 接地
U7 引脚按 1 VOUT / 2 GND / 3 EN / 4 VIN；EN 有 R8 下拉
屏幕 VCI_IN、TP_VCC 接 +3V3；VDDIO 接 +1V8；VBAT(29/30) 接 VSYS，不
是 VBUS/VBAT
I²C 与两个中断上拉到 +1V8，全总线只有一组上拉
电池 NTC 经 BAT_NTC 到 TMP_SNS，R1 顶端接 ILIMIT
VSYS、VBAT 网络各放一个 PWR_FLAG（DA9168 符号引脚为 passive）
待确认事项

1. STM32U5G9 若使用 USB，VDDUSB 需 3.0–3.6 V：可另接 +3V3，但此时 U7
不能随熄屏关断。
2. DA9168 具体 OTP 型号（-xxU72）确认 ILIMIT 作 NTC 供电的用法，否则 R1 顶
端改接 REF。
3. 电池容量与 NTC 型号确定后，重算 R1/R2 并设定充电电流（建议 ≤0.5–1 C）。
4. 请在 MAX17048 手册中核对 SDA/SCL 逻辑高门限在 1.8 V 上拉下的余量。
5. 屏幕 FPC 端各电源脚的去耦电容，按屏厂模组参考设计补充。
6. 若 SK6018 有 3.0 V 版本（-30，手册写 1.2–3.6 V 按 0.1 V 定制），可改用以远
离 TP_VCC 3.4 V 上限。

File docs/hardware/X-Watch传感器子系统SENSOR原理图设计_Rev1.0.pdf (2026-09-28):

# X-Watch 传感器子系统 SENSOR 原理图设计

## 1. 设计概述

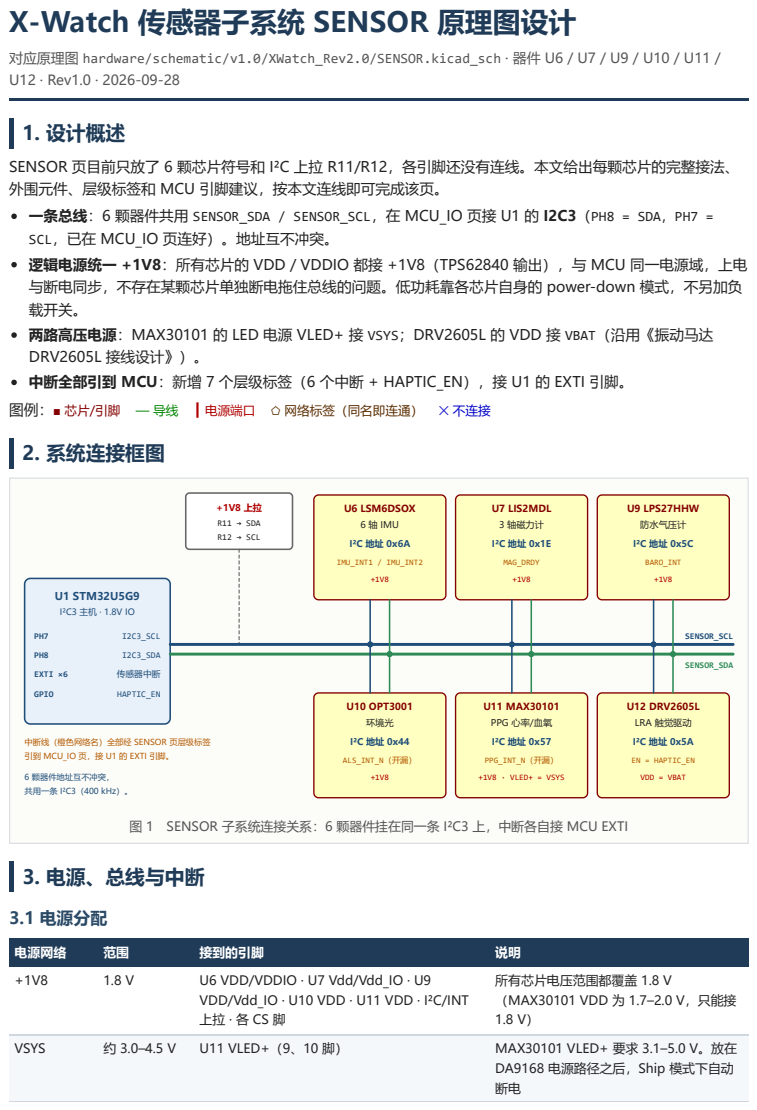
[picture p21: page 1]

对应原理图 hardware/schematic/v1.0/XWatch_Rev2.0/SENSOR.kicad_sch · 器件 U6 / U7 / U9 / U10 / U11 /
U12 · Rev1.0 · 2026-09-28

SENSOR 页目前只放了 6 颗芯片符号和 I²C 上拉 R11/R12，各引脚还没有连线。本文给出每颗芯片的完整接法、
外围元件、层级标签和 MCU 引脚建议，按本文连线即可完成该页。
一条总线：6 颗器件共用 SENSOR_SDA / SENSOR_SCL，在 MCU_IO 页接 U1 的 I2C3（PH8 = SDA，PH7 =
SCL，已在 MCU_IO 页连好）。地址互不冲突。
逻辑电源统一 +1V8：所有芯片的 VDD / VDDIO 都接 +1V8（TPS62840 输出），与 MCU 同一电源域，上电
与断电同步，不存在某颗芯片单独断电拖住总线的问题。低功耗靠各芯片自身的 power-down 模式，不另加负
载开关。
两路高压电源：MAX30101 的 LED 电源 VLED+ 接 VSYS；DRV2605L 的 VDD 接 VBAT（沿用《振动马达
DRV2605L 接线设计》）。
中断全部引到 MCU：新增 7 个层级标签（6 个中断 + HAPTIC_EN），接 U1 的 EXTI 引脚。
图例：■ 芯片/引脚 — 导线 ┃ 电源端口 ⬠ 网络标签（同名即连通） ✕ 不连接
2. 系统连接框图

中断线（橙色网络名）全部经 SENSOR 页层级标签
引到 MCU_IO 页，接 U1 的 EXTI 引脚。

图 1 SENSOR 子系统连接关系：6 颗器件挂在同一条 I²C3 上，中断各自接 MCU EXTI

VDD/Vdd_IO · U10 VDD · U11 VDD · I²C/INT

## 3.2 I²C 地址

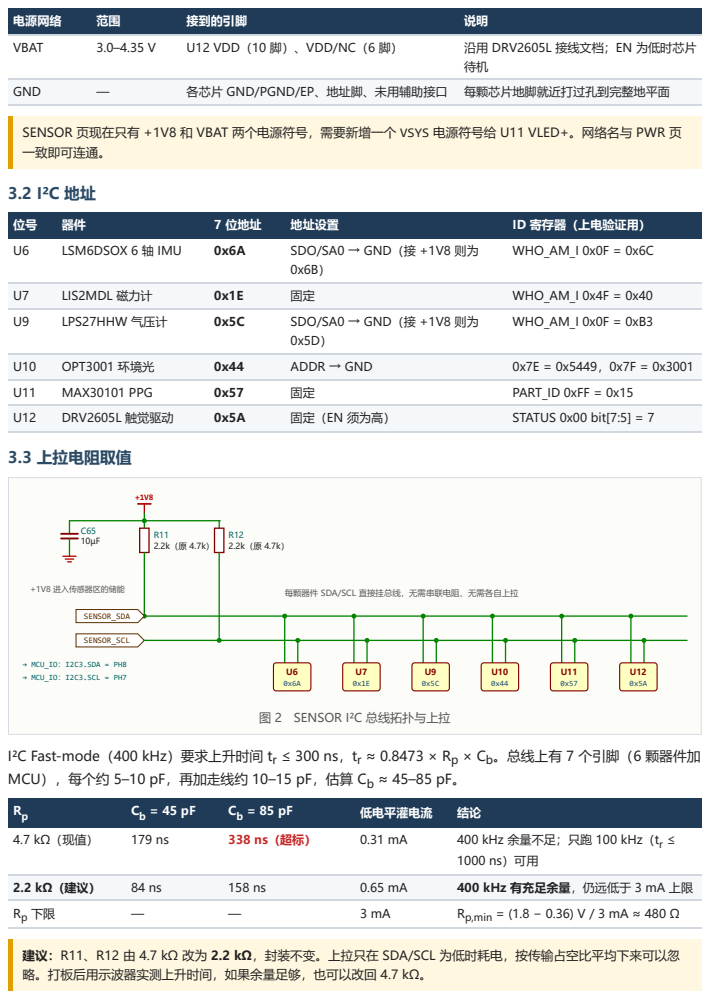
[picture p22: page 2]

SENSOR 页现在只有 +1V8 和 VBAT 两个电源符号，需要新增一个 VSYS 电源符号给 U11 VLED+。网络名与 PWR 页
一致即可连通。

每颗器件 SDA/SCL 直接挂总线，无需串联电阻、无需各自上拉

I²C Fast-mode（400 kHz）要求上升时间 tr ≤ 300 ns，tr ≈ 0.8473 × Rp × Cb。总线上有 7 个引脚（6 颗器件加
MCU），每个约 5–10 pF，再加走线约 10–15 pF，估算 Cb ≈ 45–85 pF。

建议：R11、R12 由 4.7 kΩ 改为 2.2 kΩ，封装不变。上拉只在 SDA/SCL 为低时耗电，按传输占空比平均下来可以忽
略。打板后用示波器实测上升时间，如果余量足够，也可以改回 4.7 kΩ。

## 3.4 层级标签与 MCU 引脚建议

SENSOR 页需要新增以下层级标签，并在顶层图的 SENSOR 页框上补出对应引脚，连到 MCU_IO 页。STM32U5 的 EXTI 线按引脚号分配（PA0 与 PB0 共用 EXTI0），所以 6 个中断必须用不同编号的引脚。MCU_IO 中已用 PE8（触摸 INT，EXTI8）和 PF11（屏 TE，EXTI11），下表避开了这两个编号。

层级标签 | 来源 | 电气特性 | 建议 MCU 引脚 | EXTI | MCU 配置
SENSOR_SDA /
SCL
总线 | 开漏，外部上拉 PH8 / PH7（已
| | | 连） | — | I2C3 AF，开漏
IMU_INT1 | U6 4 脚 | 推挽，高有效 | PA0-WKUP1 | 0 | 上升沿；可做 Standby 唤醒（抬腕/计步）
IMU_INT2 | U6 9 脚 | 推挽，高有效 | PB1 | 1 | 上升沿；FIFO 水位
PPG_INT_N | U11 13 脚 | 开漏，低有效 | PF2-WKUP8 | 2 | 下降沿；外部 R16 上拉
ALS_INT_N | U10 5 脚 | 开漏，低有效 | PF3 | 3 | 下降沿；外部 R15 上拉
BARO_INT | U9 7 脚 | 推挽，高有效 | PB9 | 9 | 上升沿
MAG_DRDY | U7 7 脚 | 推挽，高有效 | PC10 | 10 | 上升沿
HAPTIC_EN | → U12 5 脚 | MCU 输出 | PD4 | — | 推挽输出，默认低；外部 R17 下拉

上表只是建议：所选引脚在 MCU_IO 页当前均为空闲，且避开了 PG 口（VDDIO2 需软件使能）和 SWD 引脚 PA13/PA14。最终以 MCU_IO 整体引脚规划为准，只要保证 EXTI 编号不冲突即可。PWR 页的 PMIC_INT_N、 FG_ALRT_N 还没分配引脚，可以用剩下的 EXTI12/15。

## 4. 各器件详细接线

下列各图的引脚排列与 SENSOR.kicad_sch 中的符号一致（左侧、右侧顺序相同），可以对照着直接连线。网络标 签同名即连通，去耦电容单独画在芯片下方，布局时必须贴近标注的引脚。新增位号从现有最大编号顺延：C50 起、R15 起（全工程已用到 C49、R14）。

## 4.1 U6 LSM6DSOX 6 轴 IMU（加速度 + 陀螺仪）

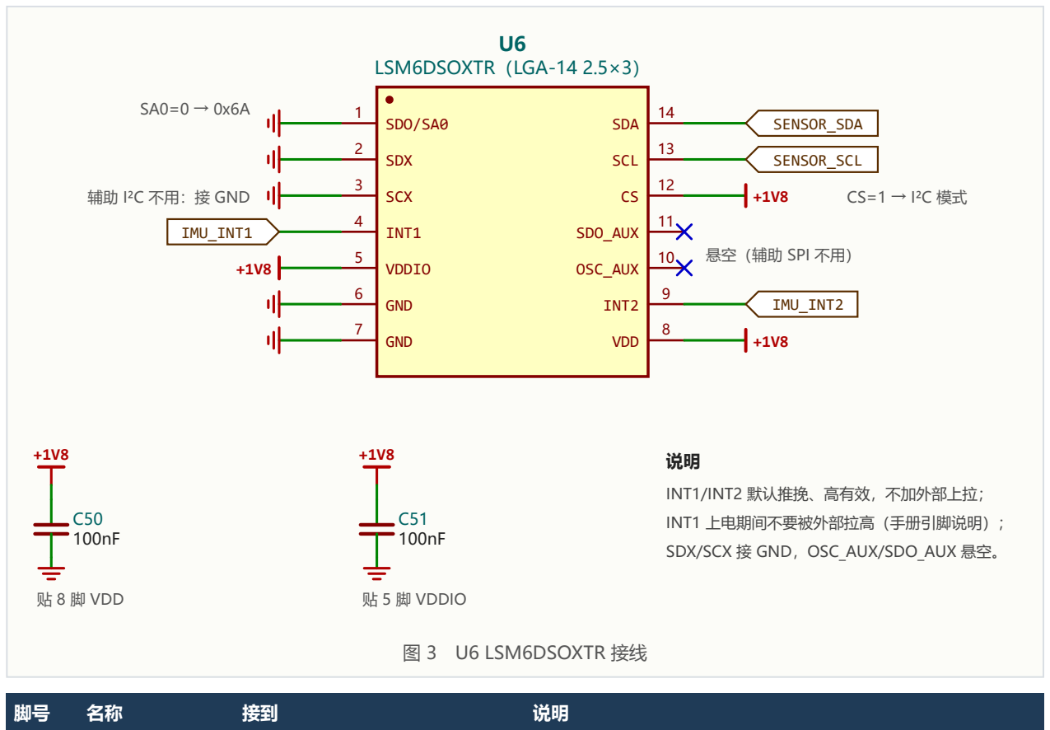
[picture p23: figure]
U6 LSM6DSOXTR（LGA-14 2.5×3）; SDO/SA0; SDX; SCX; INT1; VDDIO; GND; SDA; SCL; SDO_AUX; OSC_AUX; INT2; VDD; 辅助 I²C 不用：接 GND; IMU_INT1; SENSOR_SDA; SENSOR_SCL; CS=1 → I²C 模式; 悬空（辅助 SPI 不用）; IMU_INT2; 贴 8 脚 VDD; 贴 5 脚 VDDIO; INT1/INT2 默认推挽、高有效，不加外部上拉； INT1 上电期间不要被外部拉高（手册引脚说明）； SDX/SCX 接 GND，OSC_AUX/SDO_AUX 悬空。; 图 3 U6 LSM6DSOXTR 接线

1 | SDO/SA0 | GND | I²C 地址最低位 = 0 → 0x6A
2 | SDX | GND | 辅助 I²C 主机数据（Mode 1 不用），手册要求接 VDDIO 或 GND
3 | SCX | GND | 辅助 I²C 主机时钟，同上
4 | INT1 | IMU_INT1 | 推挽高有效；抬腕、计步、FIFO 等中断。不要外加上拉
5 | VDDIO | +1V8 + C51 100nF | IO 电源 1.62–3.6 V
6, 7 | GND | GND
8 | VDD | +1V8 + C50 100nF | 内核电源 1.71–3.6 V
9 | INT2 | IMU_INT2 | 推挽高有效；第二路中断（数据就绪/FIFO）
10 | OSC_AUX | 悬空 | 辅助 SPI 不用
11 | SDO_AUX | 悬空 | 辅助 SPI 不用（也可接 VDDIO）
12 | CS | +1V8 | 高电平 = I²C 模式；悬空或为低会进入 SPI 模式
13 | SCL | SENSOR_SCL
14 | SDA | SENSOR_SDA

## 4.2 U7 LIS2MDL 3 轴磁力计

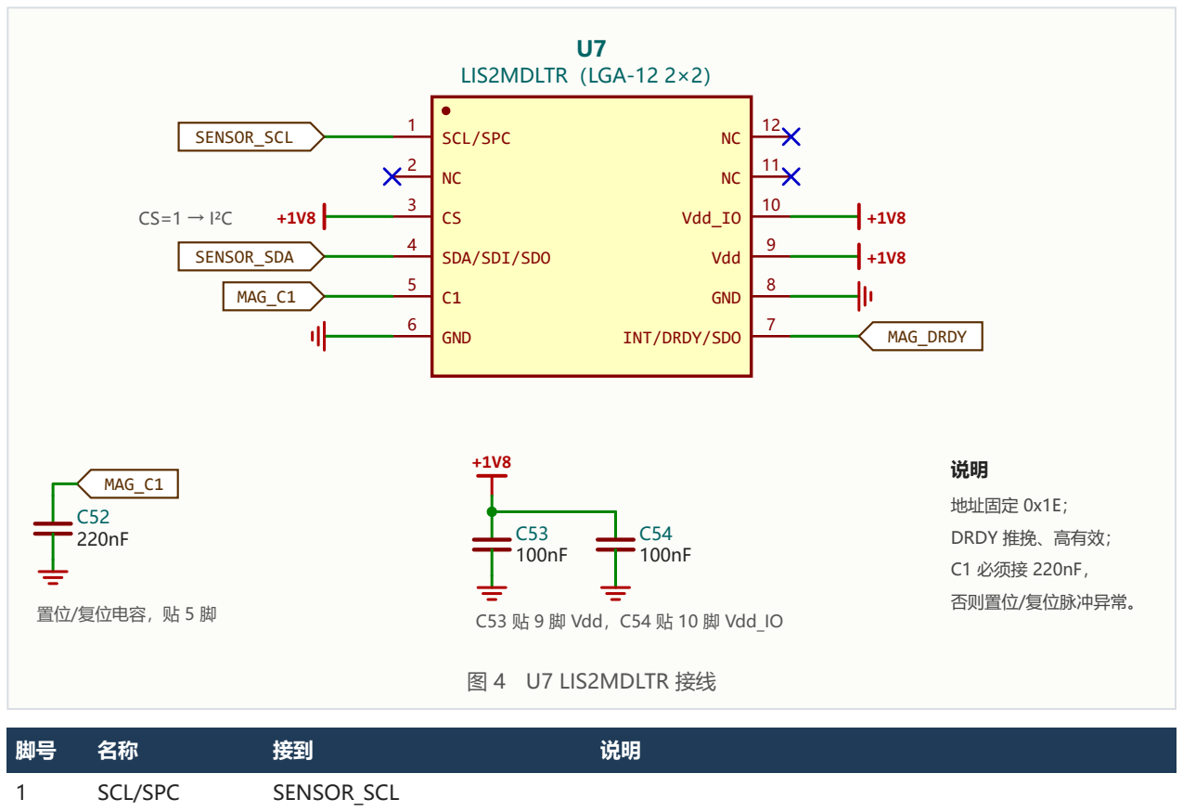
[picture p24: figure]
U7 LIS2MDLTR（LGA-12 2×2）; SCL/SPC; SDA/SDI/SDO; GND; Vdd_IO; Vdd; INT/DRDY/SDO; SENSOR_SCL; CS=1 → I²C; SENSOR_SDA; MAG_C1; MAG_DRDY; MAG_C1 C52 220nF; 置位/复位电容，贴 5 脚; C53 贴 9 脚 Vdd，C54 贴 10 脚 Vdd_IO; 地址固定 0x1E； DRDY 推挽、高有效； C1 必须接 220nF， 否则置位/复位脉冲异常。; 图 4 U7 LIS2MDLTR 接线

2 | NC | 悬空
3 | CS | +1V8 | 高电平 = I²C 使能
4 | SDA/SDI/SDO | SENSOR_SDA
5 | C1 | C52 220nF → GND | 置位/复位电路的外接电容，必须按手册取 220 nF
6, 8 | GND | GND
7 | INT/DRDY/SDO MAG_DRDY | I²C 模式下作数据就绪/中断输出，推挽高有效
9 | Vdd | +1V8 + C53 100nF | 1.71–3.6 V
10 | Vdd_IO | +1V8 + C54 100nF | 不高于 Vdd + 0.1 V；与 Vdd 同接 +1V8 满足要求
11, 12 NC | 悬空

磁力计对磁场干扰很敏感。LRA 马达（内有永磁体）、功率电感 L1/L2/L3、电池、大电流走线都会造成硬铁/软铁偏 移。布局上尽量远离这些器件，U7 下方不要走大电流线。固件里仍需做硬铁/软铁校准。

## 4.3 U9 LPS27HHW 防水气压计

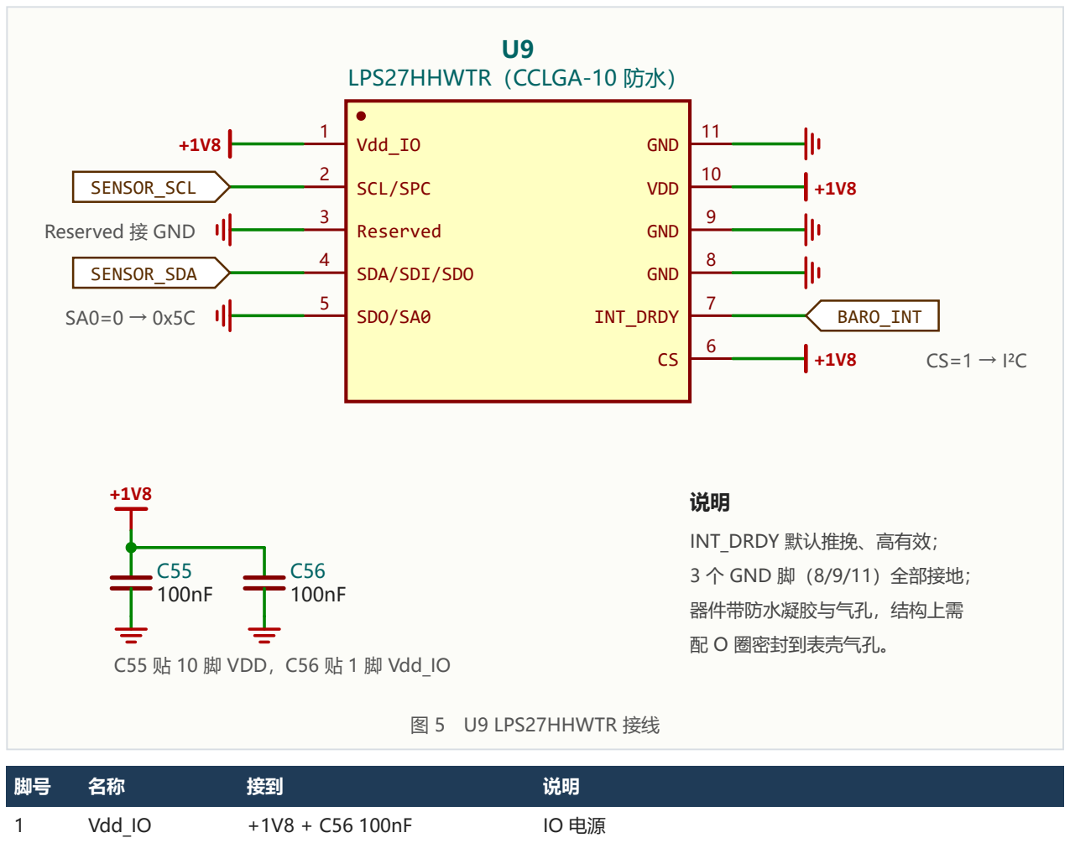
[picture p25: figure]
U9 LPS27HHWTR（CCLGA-10 防水）; Vdd_IO; SCL/SPC; Reserved; SDA/SDI/SDO; SDO/SA0; GND; VDD; INT_DRDY; SENSOR_SCL; Reserved 接 GND; SENSOR_SDA; BARO_INT; CS=1 → I²C; C55 贴 10 脚 VDD，C56 贴 1 脚 Vdd_IO; INT_DRDY 默认推挽、高有效； 3 个 GND 脚（8/9/11）全部接地； 器件带防水凝胶与气孔，结构上需 配 O 圈密封到表壳气孔。; 图 5 U9 LPS27HHWTR 接线

2 | SCL/SPC | SENSOR_SCL
3 | Reserved | GND | 手册要求接 GND
4 | SDA/SDI/SDO | SENSOR_SDA
5 | SDO/SA0 | GND | 地址最低位 = 0 → 0x5C
6 | CS | +1V8 | 高电平 = I²C 模式
7 | INT_DRDY | BARO_INT | 默认推挽高有效（可改为开漏）
8, 9,
11 | GND | GND | 三个地脚全部接地
10 | VDD | +1V8 + C55 100nF | 1.7–3.6 V

## 4.4 U10 OPT3001 环境光传感器

U10 OPT3001DNPR（USON-6 2×2）; VDD; ADDR; GND; SDA; INT; SCL; ADDR=GND → 0x44; SENSOR_SDA; ALS_INT_N; SENSOR_SCL; EP 接 GND; 贴 1 脚 VDD; ALS_INT_N INT 为开漏，需上拉; ADDR 可选 GND/VDD/SDA/SCL → 0x44/0x45/0x46/0x47； INT 低有效，可设窗口阈值中断； 感光面朝上，对准表壳透光窗。; 图 6 U10 OPT3001DNPR 接线

2 | ADDR | GND | → 0x44；接 VDD/SDA/SCL 分别为 0x45/0x46/0x47
3 | GND | GND
4 | SCL | SENSOR_SCL
5 | INT | ALS_INT_N + R15 10k 上拉 +1V8 | 开漏低有效；可设亮度上下阈值，越限才唤醒 MCU
6 | SDA | SENSOR_SDA
7 | EP | GND | 散热焊盘，内部不连电路，接 GND（手册也允许悬空）

OPT3001 放在 TOP 面，感光面朝向表盘玻璃上的透光孔（常见做法是放在屏幕边框下方开小窗或加导光柱）。盖板玻 璃或油墨会衰减光强，固件里要乘一个结构校准系数。

## 4.5 U11 MAX30101 PPG 心率/血氧传感器

U11 MAX30101EFD+T（OESIP-14）; SCL; SDA; PGND; INT#; GND; VDD; VLED+; SENSOR_SCL; SENSOR_SDA; LED 功率地; NC 焊盘照常焊接（机械固定）; PPG_INT_N; VSYS; （3.1–5.0V，两脚并联）; 贴 11 脚 VDD（1.7–2.0V）; 贴 9/10 脚 VLED+，承受 LED 脉冲; PPG_INT_N INT# 开漏，低有效; 图 7 U11 MAX30101EFD+T 接线; 焊盘照常焊接，起机械固定作用

14
2 | SCL | SENSOR_SCL
3 | SDA | SENSOR_SDA
4 | PGND | GND | LED 驱动功率地，就近打过孔
9, 10 | VLED+ | VSYS + C60 100nF + C61 10µF LED 电源 3.1–5.0 V；两脚并联。LED 脉冲电流大（最高约 50
| | | mA），电容紧贴
11 | VDD | +1V8 + C58 100nF + C59 1µF | 1.7–2.0 V，只能接 1.8 V
12 | GND | GND
13 | INT# | PPG_INT_N + R16 10k 上拉 +1V8 | 开漏低有效；FIFO 将满、数据就绪等

电池电量低时 VSYS 可能低于 3.1 V，绿光 LED 电流会下降、信号变差。固件里应结合 MAX17048 电量，在 VBAT < 3.3 V 时停止 PPG 或降低 LED 电流。MAX30101 放在 BOTTOM 面（贴皮肤一侧），LED 与光电管之间要有挡光墙， 开窗区用黑色阻焊。

## 4.6 U12 DRV2605L 触觉驱动


内部 LDO 输出，只接电容

本节与《X-Watch 振动马达 DRV2605L 接线设计 Rev1.0》接法相同，但位号不同：原文档的 U13、C49–C51、R13
在当前工程中已被占用（U12 已是 DRV2605L，C49 在 PWR 页，R13 在 DSI_LCD 页），本文改为 U12、C62–C64、
R17。另外 HAPTIC 页目前是空的，U12 放在 SENSOR 页或挪到 HAPTIC 页都可以，电气上没有区别。
5. 新增外围元件清单


位号 | 规格 | 封装 | 所属器件 / 用途 | 放置要求
C57 | 100nF / 10V / X5R | 0201/0402 | U10 VDD 去耦 | 贴 1 脚

合计新增 16 颗电容、3 颗电阻，改值 2 颗（R11/R12）。手表板空间紧，1.8 V 网络上的 100 nF 可以用 0201；
VBAT/VSYS 上的电容额定电压选 ≥10 V，以减小直流偏压带来的容值衰减。
6. PCB 布局建议

磁力计与马达/电感保持 ≥10 mm（越远越好）

OUT± 走线远离 PPG 模拟区

U6 IMU：尽量靠近 PCB 几何中心、远离板边和安装孔，避免板弯应力；不要放在马达正上方，以免振动饱
U7 磁力计：远离马达、功率电感、电池、充电触点磁铁，建议 ≥10 mm；正下方各层不走大电流线。
U9 气压计：对准表壳气孔，用 O 圈或防水透气膜密封；远离 MCU、充电芯片等发热源，避免温漂。
U10 环境光：TOP 面，正对透光窗；周围不放高器件挡光；AMOLED 屏发光会漏进来，结构上要隔光。
U11 PPG：BOTTOM 面居中，对准后盖光学窗；LED 与 PD 间挡光墙；VLED+ 电容紧贴，PGND 就近多打过
U12 DRV2605L：靠近马达焊盘；OUT± 并行短走线，远离 PPG 模拟区和天线。

## 7. 上电验证步骤

预期结果; 测 +1V8、VSYS、VBAT 到各芯片电源脚的电压; +1V8 = 1.8 V ±3%；VLED+ ≈ VSYS；U12 VDD ≈ VBAT; HAPTIC_EN 拉高，I2C3 以 100 kHz 扫描 0x08–; 应答地址：0x1E、0x44、0x57、0x5A、0x5C、0x6A，共 6 个; 逐个读 ID 寄存器（见 3.2 节表格）; 6 颗芯片的 ID 全部正确; 示波器测 SCL 上升沿（10%–90%）; 400 kHz 下 ≤ 300 ns；否则减小 R11/R12; IMU 设 104 Hz 数据就绪中断到 INT1; IMU_INT1 出现 104 Hz 脉冲，MCU EXTI0 触发; OPT3001 连续转换，遮光/照光; 照度读数随光变化；设阈值后 ALS_INT_N 拉低; MAX30101 SpO2 模式，手指贴上; FIFO 有数据，PPG_INT_N 周期拉低；红光/红外波形随脉搏起; LPS27HHW / LIS2MDL 单次测量; 气压约 1013 hPa（随海拔）；磁场模值约 25–65 µT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

I²C 走线：SDA/SCL 一起走，总长尽量短；不要与 DSI 差分对、开关电源节点平行长距离走线。
去耦：所有 100 nF 电容放在对应电源脚旁边，地端就近打孔。

去耦电容取值按各芯片数据手册“典型应用电路”取常用值，尤其是 MAX30101 的 VDD/VLED+ 和 LIS2MDL
的电容，画图前请再对照一次手册。
R11/R12 改为 2.2 kΩ 是按估算的总线电容给出的；打板后以示波器实测上升时间为准。
3.4 节的 MCU 引脚是建议值，需与 MCU_IO 页整体规划（屏、触摸、按键、电源中断）统一确认。
PPG 选型文档推荐的是 MAX86141，而原理图用的是 MAX30101。两者引脚与寄存器不兼容，请确认最终以
哪一颗为准；本文按原理图中的 MAX30101 编写。
OPT3001、LPS27HHW、MAX30101 的开孔位置与结构设计需要和外壳一起确定。
9. 参考资料

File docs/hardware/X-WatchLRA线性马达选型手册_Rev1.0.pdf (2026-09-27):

X-Watch LRA 线性马达选型手册 Rev1.0 | 第 1 页

# LRA 线性马达选型手册

X-Watch Rev2.0 触觉反馈子系统 · 配套驱动 TI DRV2605LDGSR · Rev1.0 · 2026-09-27

## 1. 结论速览

定位 | 推荐型号 | 尺寸 | 理由
首选 | Vybronics VG0832013D | Φ8.0 × 3.25 mm | 235 Hz / 1.8 Vrms，自带双面胶便于装配；资料完整 ，官方页面直接注明适配 DRV2605 类驱动
同款无胶 | Vybronics VG0832012 | Φ8.0 × 3.25 mm | 电气参数与 VG0832013D 相同，不带背胶，需要自行点胶固定
国产替代 | NFP-ELV0832B（235 Hz 款） | Φ8.0 × 3.25 mm | 振感更强（1.2–1.5 Grms），100 mm 引线，价格更低；205 Hz 款可选
薄型备选 | 通用 0825 LRA（如 LRA0825BC-0167F） | Φ8.0 × 2.5 mm | 厚度受限时使用；额定 1.2 Vrms，振感较弱。Vybronics 的 0825 系列均已停产

建议：X-Watch Rev2.0 第一版选用 VG0832013D（或参数一致的国产 0832/235 Hz LRA）。0832 规格是手表和手环最常见的尺寸，Z 轴振动方向垂直于表盘，佩戴时手腕感知最明显。

## 2. 推荐型号参数对比

参数 | VG0832013D / VG0832012 | NFP-ELV0832B (235 Hz) | LRA0825BC-0167F
厂商 | Vybronics（金龙机电品牌） | NFP Motor | 通用 0825（MikroE 模块所用）
尺寸 | Φ8.0 × 3.25 mm | Φ8.0 ± 0.1 × 3.25 ± 0.05 mm | Φ8 × 2.5 mm
振动方向 | Z 轴 | Z 轴 | Z 轴
额定电压 | 1.8 Vrms（AC 正弦） | 1.8 Vrms（AC 正弦） | 1.2 ± 0.05 Vrms
工作电压范围 | 0.1 – 1.85 Vrms | — | —
谐振频率 | 235 Hz | 235 ± 5 Hz（另有 205 Hz 款） | 240 ± 10 Hz
电流 | 典型 58 mA / 最大 80 mA | 典型 50–70 mA / 最大 90 mArms | ≤ 90 mArms
振动量 | 1.00 Grms | 1.2 – 1.5 Grms | ≥ 0.7 Grms
线圈电阻 | 未公布 | 22.5 Ω ± 10% | —
启动 / 停止时间 | ≤ 50 ms / ≤ 80 ms（50% 最大 G） | — | —
引线 / 安装 | 013D 带双面胶；012 无胶；022D 为 100 mm 长引线版 | 100 mm 引线，长度可定制 | —
重量 | — | 1.00 ± 0.1 g | —

参数来自各厂商产品页（2026-09
查询），“—”表示页面未公布。下单前请以最新数据手册为准；嘉立创/立创商城是否有现货未核实，国产同规格 0832 LRA 较多，选型时对照本表参数即可替换。

X-Watch LRA 线性马达选型手册 Rev1.0 | 第 2 页

## 3. 选型要点

检查项 | 要求 | 原因
类型 | LRA（线性谐振），不要选 ERM（偏心转子） | DRV2605L 的 LRA 闭环模式支持自动谐振追踪，振感清脆、启停快、功耗低
谐振频率 | 150–240 Hz，手册必须写明具体值和公差 | 用来计算 DRIVE_TIME 寄存器；手腕对 150–250 Hz 振动最敏感
额定电压 | 明确的 Vrms 值和最大工作电压 | 用来计算 RATED_VOLTAGE 与 OD_CLAMP，超压会损坏弹簧和线圈
电流 | ≤ 100 mA | 从 VBAT 直接取电，减小对电池和其他电源轨的冲击
厚度 | 0832（3.25 mm）优先；空间不够再用 0825（2.5 mm） | 越薄的马达动子质量越小，振感越弱
引线形式 | 焊线或 FPC | 焊线便于调试；量产可换 FPC 或弹片接触

## 4. 与 DRV2605L 的硬件连接

DRV2605L 引脚 | 连接 | 说明
VDD | VBAT，就近放 1 µF + 4.7–10 µF | 工作电压 2.0–5.2 V；不要接 +1V8（低于最低工作电压）
REG | 1 µF 到 GND | 内部 LDO 输出，不能给其他器件供电
SDA / SCL | SENSOR_SDA / SENSOR_SCL（上拉到 +1V8） | I²C 地址固定 0x5A，与现有传感器不冲突；VIH 最小 1.3 V，1.8 V 电平可直接用
EN | MCU GPIO（1.8 V） | 不振动时拉低，关断电流极小，有利于续航
IN/TRIG | GND（纯 I²C 控制）或 MCU GPIO | 需要外部触发或 PWM 输入时才接 GPIO
OUT+ / OUT− | 马达两根引线 | 内部 H 桥驱动，不需要续流二极管；LRA 不分极性
GND | GND | —

## 5. DRV2605L 寄存器计算（LRA 闭环模式）

公式来自 TI DRV2605L 数据手册，默认采样时间 SAMPLE_TIME = 300 µs。 额定电压：VLRA,rms = 20.58×10⁻³ × RATED_VOLTAGE / √(1 − (4×tsample + 300 µs) × fLRA)

过驱钳位：VOD(峰值) = 21.96×10⁻³ × OD_CLAMP

驱动时间：LRA 驱动时间 = DRIVE_TIME × 0.1 ms + 0.5 ms，取谐振周期的一半

寄存器 | VG0832013D / NFP 235 Hz | NFP 205 Hz | 0825（1.2 Vrms / 240 Hz）
RATED_VOLTAGE (0x16) | 70 → 0x46 | 73 → 0x49 | 47 → 0x2F
OD_CLAMP (0x17) | 116 → 0x74（2.55 Vpk） | 116 → 0x74 | 77 → 0x4D（1.70 Vpk）
DRIVE_TIME（0x1B[4:0]） | 16 → 0x10 | 19 → 0x13 | 16 → 0x10
CONTROL1 (0x1B) | 0x90（STARTUP_BOOST=1） | 0x93 | 0x90
FEEDBACK (0x1A) | 0xB6（LRA 模式，默认增益） | 0xB6 | 0xB6
LIBRARY_SEL (0x03) | 0x06（LRA 效果库） | 0x06 | 0x06

OD_CLAMP 按“额定 Vrms × √2”取值，属于保守设置。VG0832 系列允许最大 1.85 Vrms，对应 OD_CLAMP 最大约 0x77。换用其他马达时，把新的额定电压和谐振频率代入上面三个公式重新计算。

X-Watch LRA 线性马达选型手册 Rev1.0 | 第 3 页

## 6. 初始化与自动校准流程

首次上电执行一次自动校准，把结果存入 MCU Flash，以后上电直接写回，不必每次校准。

1. EN 拉高，等待 > 250 µs
2. MODE(0x01) = 0x07 ; 退出待机，进入自动校准模式
3. RATED_VOLTAGE(0x16) = 0x46
4. OD_CLAMP(0x17) = 0x74
5. FEEDBACK(0x1A) = 0xB6 ; N_ERM_LRA=1
6. CONTROL1(0x1B) = 0x90 ; DRIVE_TIME=16
7. CONTROL4(0x1E) = 0x30 ; AUTO_CAL_TIME=1000 ms
8. GO(0x0C) = 0x01，轮询直到 GO 变回 0
9. 读 STATUS(0x00)，DIAG_RESULT(bit3)=0 表示校准成功
10. 保存 0x18 (A_CAL_COMP)、0x19 (A_CAL_BEMF)、0x1A[1:0] (BEMF_GAIN)
11. LIBRARY_SEL(0x03) = 0x06，MODE(0x01) = 0x00 ; 内部触发模式
12. 播放效果：WAV_SEQ1(0x04) = 效果编号，WAV_SEQ2(0x05) = 0，GO = 0x01

校准失败（DIAG_RESULT=1）的常见原因：马达没有固定、处于悬空状态；引线虚焊；RATED_VOLTAGE 或 DRIVE_TIME 与马达参数不匹配。

## 7. 结构与装配注意事项

- 马达要用背胶或结构胶牢牢贴在外壳或中框上，不能只靠 PCB 上的两个焊点支撑，否则振感会被吸收，校准也可能失败。
- Z 轴马达的安装面要与表盘平行，这样振动方向垂直于手腕，感知最明显。
- 马达周围预留约 0.2 mm 间隙，避免振动时碰到电池或屏幕 FPC 产生异响。
- 引线走线远离 PPG 传感器和天线，马达驱动电流会带来干扰。
- 马达不要贴在电池正上方直接受力的位置，长期振动可能损伤软包电池。

## 8. 参考资料

Vybronics VG0832012：https://www.vybronics.com/coin-vibration-motors/lra/v-g0832012
Vybronics VG0832013D：https://www.vybronics.com/coin-vibration-motors/lra/v-g0832013d
Vybronics VG0825001D（已停产）：https://www.vybronics.com/coin-vibration-motors/lra/v-g0825001dNFP-ELV0832B：https://nfpmotor.com/8mm-linear-resonant-actuator-3mm-type-nfp-elv0832b-205hz-or-235hz MikroE Vibration LRA Motor 240Hz（LRA0825BC-0167F）：https://www.mikroe.com/vibration-lra-motor-240hz TI DRV2605L 数据手册：https://www.ti.com/product/DRV2605L

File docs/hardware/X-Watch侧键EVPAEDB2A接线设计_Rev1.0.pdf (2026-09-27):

X-Watch 侧键 EVPAEDB2A 接线设计 Rev1.0 | 第 1 页

# 侧键 EVPAEDB2A 接线设计

X-Watch Rev2.0 · BUTTONS 页 · SW1 与 DA9168 RIN_N / STM32U5G9 GPIO 连接 · Rev1.0 · 2026-09-27

## 1. 方案概述

手表侧键 SW1 选用松下 EVPAEDB2A（立创 C79150）侧推式轻触开关。一个按键同时承担三个功能：给 MCU 当普通按键、在 Ship 模式下唤醒 DA9168、死机时长按硬件复位。按键一端接 GND，另一端直接接 DA9168 的 RIN_N（网络 PWR_RIN_N），再经过一个肖特基二极管接到 STM32U5G9 的 GPIO（网络 KEY_MCU）。

按键动作 | 谁响应 | 效果
短按 | STM32U5G9（KEY_MCU 下降沿中断） | 普通按键：亮屏、返回、菜单等，由固件定义
Ship 模式下按住 ≥ t_EXIT_KEY | DA9168（RIN_N） | 退出 Ship 模式，整机上电。时间由 RIN_N_SHIP_EXIT_TMR 选 2s 或 20–50ms
长按 ≥ t_PRESS（默认 12s） | DA9168（RIN_N） | 硬件复位：VSYS 断电，松开后经 SYS_WAIT 重新上电，寄存器复位

## 2. EVPAEDB2A 引脚定义

脚号 | 功能 | 说明
1 | 固定触点 | 与 3 脚内部相连
2 | 动触点 | 按下时与 1/3 脚导通；松开时断开（常开）
3 | 固定触点 | 与 1 脚内部相连
4、5 | 接地端（金属支架） | 松下官网标注本型号带 Ground Terminal；焊在板边，承受按压的横向力

注意：1/3 与 2 的对应关系来自立创 EasyEDA 符号（工程库 XWatch_Rev2.0.kicad_sym）。松下原厂数据手册本次没能下载核对。首批样品到手后请用万用表确认：按下时 2 脚与 1、3 脚导通，松开时断开。即使实际是其他组合，也只需把“动触点”那一脚接 PWR_RIN_N、另一组接 GND。

PMIC（PWR 页） D4 RIN_N; D4 PWR_RIN_N; SW1 EVPAEDB2A; 内部相连; 接地端（金属支架） 引到 GND 泄放 ESD; R15 10k KEY_MCU; STM32U5G9; GPIO / EXTI; 下降沿中断

X-Watch 侧键 EVPAEDB2A 接线设计 Rev1.0 | 第 2 页

## 3. 详细接线原理图

- 按下：2 脚与 1/3 脚导通 → PWR_RIN_N 被拉到 GND；KEY_MCU 经 D1 被拉到约 0.2–0.3V（逻辑低）。
- 松开：PWR_RIN_N 由 DA9168 内部上拉为高；KEY_MCU 由 R15 上拉到 1.8V；D1 反偏，两个电源域互不干扰。
- 引脚按 LCSC 符号绘制，未按实际封装位置排列；位号 C52 / D1 / R15 为建议值。
图 1 SW1 与 DA9168 RIN_N、STM32U5G9 GPIO 接线原理图

## 4. 连接说明

连接 | 接法 | 原因
SW1-2 | PWR_RIN_N（→ DA9168 D4） | RIN_N 内部有约 120kΩ 上拉，按下即拉低。VIL ≤ 0.54V，接 GND 完全满足
SW1-1、SW1-3 | GND（两脚都接） | 两脚内部相连，都焊到 GND 能增加焊接强度和触点冗余
SW1-4、SW1-5 | GND | 金属支架接地，外壳静电经支架泄放到地，不打进 RIN_N
C52 100nF | PWR_RIN_N → GND，靠近 SW1 | 滤除按键抖动和 ESD 尖峰；DA9168 内部另有 10µs 去抖
D1 RB520S-30 | 阴极接 PWR_RIN_N，阳极接 KEY_MCU | 隔离两个电源域：RIN_N 内部上拉电压未知（可能是 VSYS），不能直接灌进 1.8V 的 MCU 引脚
R15 10k | KEY_MCU → +1V8 | MCU 侧上拉；按下时开关电流约 180µA，保证触点可靠导通（见第 6 节）
KEY_MCU | STM32U5G9 任一 1.8V GPIO | 配置为输入、下降沿 EXTI 中断，可从 Stop 模式唤醒 MCU；内部上拉可关闭

### 为什么不让 MCU 直接驱动 RIN_N：

RIN_N 被拉低超过 t_PRESS 会让 DA9168 切断 VSYS，整机掉电。MCU 如果用输出脚驱动 RIN_N，一旦固件异常把它拉低，就会把自己断电。所以这里用二极管单向连接：MCU 只能读，不能拉低 RIN_N。需要软件重启时，用 I²C 写 DA9168 的 RST_SYS 位（PMC_SYS_06 bit7）。

X-Watch 侧键 EVPAEDB2A 接线设计 Rev1.0 | 第 3 页

## 5. 外围元件清单

位号 | 规格 | 封装 | 说明
SW1 | EVPAEDB2A（C79150），3.0N，20 万次 | 板边侧推 4.5 × 2.6mm | 已在 BUTTONS 页放置
D1 | RB520S-30，30V / 200mA 肖特基 | SOD-523 | 也可用 BAT54 系列、RB521S 等低 Vf 肖特基
C52 | 100nF / 10V / X5R | 0402 | 靠近 SW1-2 放置
R15 | 10kΩ / 1% | 0402 | 上拉到 +1V8
位号按当前原理图已用编号顺延（已用到 R14、C48）。C49–C51 已在振动马达文档中预留，故电容从 C52 起。

## 6. 电气校核

检查项 | 计算 / 依据 | 结论
RIN_N 低电平 | 按下时 RIN_N ≈ 0V；DA9168 VIL 最大 0.54V | 满足
KEY_MCU 低电平 | 按下时 = D1 正向压降，约 0.2–0.3V（电流 180µA）；STM32U5 VIL ≤ 0.3 × 1.8V = 0.54V | 满足
KEY_MCU 高电平 | 松开时 R15 拉到 1.8V；D1 反偏漏电 < 1µA，压降可忽略 | 满足
开关最小负载 | EVP-AE 额定 10µA / 2V DC 起；MCU 侧 1.8V × 180µA，电压略低于 2V，电流远大于 10µA | 可用，建议样机验证
待机功耗 | 松开时无电流；按下时约 180µA（R15）+ 约 15–35µA（RIN_N 内部上拉） | 只在按下期间耗电
ESD | 外壳静电经支架（4/5 脚）到 GND；C52 吸收残余尖峰 | 如外壳为金属，可在 PWR_RIN_N 加一颗 TVS

## 7. 按键行为时序

RIN_N

KEY_MCU

VSYS

① 短按
MCU 读键

② 按住 ≥ t_EXIT_KEY
Ship 模式下唤醒

③ 长按 ≥ t_PRESS
硬件复位（整机断电重启）
2s（或 20–50ms） | t_PRESS = 12s（默认）
VSYS 关断 | t_SHDN / SYS_WAIT RIN_N 松开后 等 SYS_WAIT 恢复

示意图，时间轴非比例。RST_OPT = 1（默认）：VSYS 在 RIN_N 松开后、再经过 SYS_WAIT 才恢复。
图 2 RIN_N 短按、唤醒、长按复位时序

### 相关 DA9168 寄存器（数据手册 Rev2.2 Table 46 / 49 / 60）：

X-Watch 侧键 EVPAEDB2A 接线设计 Rev1.0; 8. PCB 与结构设计; PCB（顶层视图，1mm ≈ 26pt）; PWR_RIN_N（2 脚）; GND 过孔; 按键帽; • 板边缺口：3.8mm 宽 × 1.35mm 深; • 贴装高度 0.95mm; 图 3 SW1 板边安装与外壳结构示意

寄存器 | 字段 | 复位值 | 含义 / 建议

PMC_SYS_03 (0x0012) | RST_TMR [2:1] | 0x2 = 12s | 长按复位时间：0=4s、1=8s、2=12s、3=20s。建 议保持 12s，避免误触

PMC_SYS_03 (0x0012) | SYS_WAIT [7:6] | 0x0 = 1s | VSYS 断电时间：1/2/3/4s

PMC_SYS_06 (0x0015) | RIN_N_SHIP_EXIT_TMR [6] 见说明 | | Ship 模式唤醒去抖时间：0=2s、1=20–50ms。寄 存器表写复位值 0x1，特性表写默认 2s，以实测读回为准。建议用 2s，防止运输中误唤醒

PMC_SYS_06 (0x0015) | RST_SYS [7] | 0 | 写 1 触发 VSYS 重启，给固件做软件重启用

PMC_LDO_04 (0x0021) | RST_OPT [4] | 1 | 1 = 松开 RIN_N 后再经 SYS_WAIT 恢复 VSYS（推荐保持）

PMC_LDO_04 (0x0021) | RST_OPT_PWRCYC [6] | 1 | 仅 RST_OPT = 0 时有效：长按是否触发重启

封装尺寸（来自 XWatch_Rev2.0.pretty）

4/5 脚就近打 GND 过孔

按压方向（与 PCB 平行）

• 板边缺口：工程封装 EVPAEDB2A.kicad_mod 自带 Edge.Cuts 缺口（3.8mm ×
1.35mm），开关本体半沉入板内。画 PCB 时让缺口正好落在板框上，并和板框线连成一体，否则会出现 DRC
错误或缺口没加工出来。

• 焊盘：1/2/3 脚在板内，4/5 脚在缺口两侧。四周不要放高器件，避免挡住回流焊时的热风和目检。

• 走线：2 脚引出 PWR_RIN_N，C52 紧靠 2 脚；1/3 脚各打一个 GND 过孔；4/5 脚就近接地。

• D1、R15：放在 SW1 和 MCU 之间，靠近 SW1 即可。KEY_MCU 是低速信号，没有特殊要求。

• 结构：按键帽和开关按压头之间留 0.1–0.2mm 间隙，防止常压；按键轴上加 O
型圈防水。外壳的按压力会加到开关本体的 3.0N 上，手感会更重一些。
9. 固件要点

• KEY_MCU 配置为输入、EXTI 下降沿中断；因为有外部 R15 上拉，内部上拉可以关掉，省一点电流。

X-Watch 侧键 EVPAEDB2A 接线设计 Rev1.0 | 第 5 页
- 软件去抖 10–20ms；长按功能（如关机菜单）建议设在 2–3s，远低于硬件复位的 12s，两者不冲突。
- 进入 Ship 模式前（SHIP_MODE = 1），确认按键已松开：RIN_N 为低时 DA9168 会推迟进入 Ship 模式。
- 上电后读 PMC_SYS_06 确认 RIN_N_SHIP_EXIT_TMR 的实际值，按需要写入。

## 10. 参考资料

DA9168 数据手册 Rev2.2：docs/references/Rev2.0/电源管理/（第 9、21–23、25、34、37–38、64–66、86 页） Panasonic EVP-AE
系列：https://na.industrial.panasonic.com/products/switches-encoders-interface-devices/switches/series/79271 立创商城 EVPAEDB2A：C79150
X-Watch DA9168 电源子系统设计 Rev1.0（docs/hardware）

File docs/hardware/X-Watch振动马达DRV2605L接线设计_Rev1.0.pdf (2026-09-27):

STM32U5G9; I²C 主机 + GPIO; DRV2605LDGSR; 触觉驱动 / 地址 0x5A; LRA 线性马达; 锂电池 VBAT; 其他传感器; IMU / 气压 / 磁 / 光; I²C (SENSOR_SDA/SCL); HAPTIC_EN; OUT+; OUT−; 共享 I²C 总线; VDD（直接取电）; 1.8V 逻辑电平直连（VIH ≥ 1.3V），无需电平转换

X-Watch 振动马达 DRV2605L 接线设计 Rev1.0 | 第 1 页

# 振动马达 DRV2605L 接线设计

X-Watch Rev2.0 · DRV2605LDGSR + 0832 LRA 线性马达 · Rev1.0 · 2026-09-27

## 1. 方案概述

DRV2605LDGSR 挂在现有的 SENSOR I²C 总线上（地址 0x5A），由 STM32U5G9 通过 I²C 写寄存器触发振动效果，另用一个 GPIO（HAPTIC_EN）控制使能。芯片直接从锂电池 VBAT 取电，内部 H 桥差分驱动 LRA 马达。外围只需要 3 个电容和 1 个电阻。

## 2. 系统连接框图

图 1 触觉子系统连接关系

DRV2605LDGSR (VSSOP-10); REG; SCL; SDA; IN/TRIG; 10 VDD; OUT−; GND; OUT+; VDD/NC; 内部 LDO，仅接电容; SENSOR_SCL; SENSOR_SDA; 仅 I²C 控制时接地; HAPTIC_EN; → STM32U5 GPIO (1.8V); VBAT; 3.0–4.35V（锂电池）; LRA; 马达引线 B; 马达引线 A; VG0832013D 0832 / 235Hz / 1.8Vrms 不分极性; 已有上拉：R11/R12 4.7k → +1V8 无需另加

X-Watch 振动马达 DRV2605L 接线设计 Rev1.0 | 第 2 页

## 3. 详细接线原理图

图 2 DRV2605LDGSR 与 LRA 马达接线原理图（引脚按封装实际顺序排列，位号为建议值）

## 4. 引脚接线表

脚号 | 名称 | 接到 | 说明
1 | REG | C49 1µF → GND | 内部 1.8V LDO 输出，只接电容，不能给其他器件供电
2 | SCL | SENSOR_SCL | 共用现有 R12 4.7k 上拉（+1V8），不用另加
3 | SDA | SENSOR_SDA | 共用现有 R11 4.7k 上拉（+1V8）；I²C 地址固定 0x5A
4 | IN/TRIG | GND | 只用 I²C 控制时接地；需要 PWM 或外部触发时改接 MCU GPIO
5 | EN | HAPTIC_EN（MCU GPIO）+ R13 100k 下拉 | 高电平工作；下拉保证 MCU 复位期间马达不乱振
6 | VDD/NC | VBAT | 可悬空，建议与 10 脚并联接 VBAT，降低电源阻抗
7 | OUT+ | 马达引线 A | H 桥输出，无需续流二极管
8 | GND | GND | 焊盘旁至少打 2 个 GND 过孔
9 | OUT− | 马达引线 B | LRA 不分极性，A/B 接反不影响工作
10 | VDD | VBAT + C50 1µF + C51 10µF | 工作电压 2.0–5.2V；电容贴近引脚

注意：DGS 封装的输出脚顺序：7 脚是 OUT+，9 脚是 OUT−，中间 8 脚是 GND。画符号前请对照 TI 数据手册第 5 节，或直接从立创商城 C527464 导出符号和封装。

## 5. 外围元件清单

X-Watch 振动马达 DRV2605L 接线设计 Rev1.0; DRV2605L; VBAT 走线 ≥ 0.3mm; OUT−; OUT+; 马达焊盘 引线焊接; GND 过孔 ×2; OUT± 远离此区域; 图 3 DRV2605L 局部布局示意; 8. 参考资料

位号 | 规格 | 封装建议 | 用途

U13 | DRV2605LDGSR（C527464） | VSSOP-10，0.5mm 间距 | LRA/ERM 触觉驱动

C49 | 1µF / 10V / X5R | 0402 | REG 输出电容

C50 | 1µF / 10V / X5R | 0402 | VDD 高频去耦

C51 | 10µF / 10V / X5R | 0603 | VDD 储能，吸收马达启动电流

M1 | VG0832013D 或同规格 0832 LRA | 焊线 / 焊盘 | Z 轴线性马达

位号 U13、C49–C51、R13 按当前原理图已用编号顺延（至 U12、C48、R12），如有新增请再调整。
6. PCB 布局建议

PCB 顶层（示意，非比例）

OUT± 并行走线 ≥ 0.25mm，尽量短

PPG 模拟前端 / 天线

• 去耦电容：C50 紧贴 10 脚，C51 其次；C49 紧贴 1 脚。电容的地端就近打过孔。

• 电源走线：VBAT 到 VDD 的走线 ≥ 0.3mm。马达启动峰值电流约 100mA。

• 输出走线：OUT+ 和 OUT− 并行走线，宽度 ≥ 0.25mm，尽量短，远离 PPG 模拟信号和天线。

• 马达安装：PCB 上只放两个焊盘，马达用背胶贴在外壳或中框上，不要只靠焊点支撑。

• I²C：DRV2605L 挂在 SENSOR 总线末端即可，不需要额外上拉。
7. 上电验证步骤

步骤 | 操作 | 预期结果

1 | 测 VDD（10 脚）和 REG（1 脚）电压 | VDD ≈ VBAT；EN 拉高后 REG ≈ 1.8V

2 | HAPTIC_EN 拉高，I²C 扫描总线 | 0x5A 有应答

3 | 读 STATUS 寄存器 0x00 | bit[7:5] = 7（DRV2605L 的 DEVICE_ID）

4 | 按《LRA 线性马达选型手册》第 5–6 节写寄存器并执行自动校准 | DIAG_RESULT（bit3）= 0

5 | MODE = 0x00，WAV_SEQ1 = 1，GO = 1 | 马达短振一次（强点击效果）

TI DRV2605L 数据手册：https://www.ti.com/lit/ds/symlink/drv2605l.pdf
立创商城 DRV2605LDGSR：编号 C527464

X-Watch 振动马达 DRV2605L 接线设计 Rev1.0 | 第 4 页

X-Watch LRA 线性马达选型手册 Rev1.0（docs/hardware）

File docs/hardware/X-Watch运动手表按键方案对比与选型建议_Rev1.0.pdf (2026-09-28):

X-Watch 运动手表按键方案对比与选型建议 Rev1.0 | 第 1 页

# 运动手表按键方案对比与选型建议

X-Watch Rev2.0 · 12 个主流运动 / 智能手表系列按键布局对比 · Rev1.0 · 2026-09-28

## 1. 结论速览

给 X-Watch Rev2.0 的建议：右侧 3 键（不带旋转表冠）+ 触摸屏。
K1（2 点）电源 / 主页，沿用现有 SW1，接 DA9168 RIN_N；K2（3 点）红色运动快捷键；K3（4 点）返回 / 计圈。K2、K3 只接 MCU GPIO，三个键统一用 EVPAEDB2A。硬件只需新增 2 个开关、2 个电阻、2 个电容和 2 个 GPIO。

市面上的运动手表按键数量在 2 到 5 个之间，可以分成三类：

类型 | 按键数 | 代表机型 | 特点
纯按键 | 4–5 | Garmin fēnix / Forerunner、Polar Vantage V3、Amazfit T-Rex 3 | 所有操作都能只靠按键完成，戴手套、出汗、游 泳时可靠；按键多，结构和防水成本高
表冠 + 按键 | 3 | Suunto Race、COROS Vertix 2、Apple Watch Ultra、Galaxy Watch Ultra、华为 Watch Ultimate | 表冠负责滚动和确认，另加电源键和一个运动快 捷键；高端运动 / 潜水表主流
表冠 + 按键 / 双键 | 2 | COROS Pace 3、Amazfit Cheetah Pro、华为 Watch GT、Galaxy Watch、Apple Watch | 主要靠触摸屏操作，按键只负责主页和返回；最 简单，偏日常

## 2. 各机型按键明细

机型 | 键 数 | 左侧 | 右侧 | 表冠 | 运动快捷键 | 来源
Garmin fēnix 7 / 8、FR265 / 965 | 5 | LIGHT、UP·MEN U、DOWN | START·STOP、BACK·LA P | 无 | START（红） | 官方手册
Polar Vantage V3 | 5 | LIGHT（上）、B ACK（下） | UP、OK、DOWN | 无 | OK | 官方手册
Amazfit T-Rex 3 | 4 | UP、DOWN | SELECT（上）、BACK（ 下） | 无 | SELECT | 官方手册
Suunto Race | 3 | — | 上键、表冠（中）、下键 | 有 | 上键（开始/暂 停） | 官方手册
COROS Vertix 2 | 3 | — | LIGHT（上）、表冠（中 ）、BACK（下） | 有 | 表冠 | 官方帮助中心
Apple Watch Ultra | 3 | Action 键（橙） | 表冠（上）、侧键（下） | 有 | Action 键 | Apple 支持
Galaxy Watch Ultra | 3 | — | Home、Quick（橙）、B ack | 无 | Quick 键 | SamMobile
华为 Watch Ultimate | 3 | 自定义键 | 表冠（上）、快捷键（下 ） | 有 | 左侧自定义键 | 评测
COROS Pace 3 | 2 | — | 表冠（上）、BACK（下 ） | 有 | — | 官方帮助中心
Amazfit Cheetah Pro | 2 | — | 表冠（上）、按键（下） | 有 | — | 评测
华为 Watch GT 系列 | 2 | — | 表冠（上）、侧键（下） | 有 | — | 公开资料
Galaxy Watch / Apple Watch | 2 | — | Home/表冠（上）、Bac k/侧键（下） | 部分 | — | 公开资料

“公开资料”指厂商产品页与大量评测的共同描述，本次未逐一查官方手册。

## 3. 按键布局总览

5

X-Watch 运动手表按键方案对比与选型建议 Rev1.0; LIGHT; DOWN; START; BACK; Garmin fēnix 7 / 8; Polar Vantage V3; SELECT; Amazfit T-Rex 3; Suunto Race; COROS Vertix 2; Action; Home; Quick; Back; 自定义; COROS Pace 3; Home/表冠; Back/侧键; 电源 / 背光键; 运动 / 确认快捷键（带色标）; 旋转表冠; 普通按键

Apple Watch Ultra

Galaxy Watch Ultra

华为 Watch Ultimate

华为 Watch GT 系列

Amazfit Cheetah Pro

Galaxy Watch / Apple Watch

图 1 12 个系列的按键布局（佩戴视角正视图，左手佩戴；位置为示意，按官方手册和评测整理）

Amazfit T-Rex 3

X-Watch 运动手表按键方案对比与选型建议 Rev1.0 | 第 3 页

## 4. 按键数量分布

2 键 | 4 | Pace 3 / Cheetah Pro / 华为 GT / Galaxy·Apple Watch
3 键 | 5 | Suunto Race / Vertix 2 / Apple Ultra / Galaxy Ultra / 华为 Ultimate
5 键 | 2 | Garmin fēnix·Forerunner / Polar Vantage V3

本文统计的 12 个系列（Garmin 5 键机型合并计 1 个）。有表冠的机型全部集中在 2–3 键。
图 2 各按键数量的机型分布

## 5. 共同规律

- 有表冠就少按键：一个旋转表冠能同时完成“上翻、下翻、确认”，相当于替代 3 个按键，所以有表冠的机型全部是 2–3 键。
- 没有表冠就要 4–5 键：需要独立的上、下、确认、返回，再加电源键，Garmin、Polar、T-Rex 都是这样。
- 高端款都有“运动快捷键”：Garmin 的红色 START、Apple Ultra 的橙色 Action、Galaxy Ultra 的橙色 Quick、华为 Ultimate 的红圈表冠。都用醒目颜色标出来，按一下就能开始运动，不用看屏幕。
- 电源键和复位绑在一起：Garmin 按住 LIGHT 关机 / 重启，T-Rex 3 按住 BACK 5 秒强制重启，Apple 按住侧键开关机。一般只有一个键承担电源功能。
- 按键多集中在右侧：2–3
键的机型几乎都把按键放在右侧，左手佩戴时右手食指最容易按到；左侧多留空或只放一个快捷键。
- 触摸屏是标配：所有新机型都有触摸屏，但专业款保证“只用按键也能完成全部操作”。

## 6. X-Watch 方案评估

结合项目现状评估：显示屏是 1.43" 圆形 AMOLED（DO0143FMST02，466×466，FT3168 触摸），目前只有一个侧键 SW1（EVPAEDB2A），接 DA9168 的 RIN_N 并由 MCU 读取。

方案 | 按键 | 优点 | 缺点 | 评价
A. 维持 1 键 | K1 电源 | 零改动 | 运动中开始 / 暂停 / 计圈都要点屏幕 ，出汗、戴手套时不可靠；无法做“ 按键锁屏” | 不推荐
B. 右侧 2 键 | K1 电源、K3 返回 | 改动最小；类似华为 GT / Galaxy Watch | 没有独立运动键，开始 / 计圈要复用返回键，操作容易冲突 | 可接受
C. 右侧 3 键 | K1 电源、K2 运动、K3 返回 | 覆盖运动场景的全部高频操 作；和 Galaxy Ultra / Suunto Race 布局接近；只在一侧开孔 | 比方案 B 多 1 个键和 1 个开孔 | 推荐
D. 左 3 右 2（5 键） | 照搬 Garmin | 不看屏幕也能完成所有操作 | 两侧都要开孔，圆形 PCB 两侧都要 做板边缺口；结构、防水、成本最高 | 留给后续版 本
E. 表冠 + 按键 | 表冠 + 1–2 键 | 滚动体验最好 | 需要磁编码器或光学传感器、旋转密 封结构；Rev2.0 没有预留 | 不推荐（本 版）

1.43" 圆形 AMOLED; X-Watch Rev2.0; 左侧无按键; • 短按：亮屏 / 回表盘; • 长按 2s：关机菜单; • 按住 12s：硬件复位（DA9168）; • Ship 模式下按住：开机; K2 运动快捷键（3 点，红色）; • 短按：运动列表 / 开始 / 暂停; • 长按：结束运动; • 可在设置里改成其他应用; • 短按：返回上一级; • 运动中短按：计圈; • 长按：最近使用的应用

X-Watch 运动手表按键方案对比与选型建议 Rev1.0 | 第 4 页

## 7. 推荐方案：右侧 3 键

组合键：K2 + K3 同时长按 → 锁定 / 解锁按键和触摸屏（游泳、戴手套时防误触）

佩戴视角正视图（左手佩戴），3 个键都放在右侧 2 / 3 / 4 点位置，统一用 EVPAEDB2A。
图 3 X-Watch Rev2.0 推荐按键布局与功能分配

### 7.1 功能分配

按键 | 位置 | 短按 | 长按 | 其他
K1 电源 / 主页 | 右上 2 点 | 亮屏；任意界面回表盘 | 2s：关机 / 重启菜单（固件实现） | 按住 12s：DA9168 硬件复位；Ship 模式下按住：开机
K2 运动（红色） | 右中 3 点 | 表盘上打开运动列表；运动 中开始 / 暂停 | 运动中结束并保存 | 设置里可改成打开其他应用
K3 返回 / 计圈 | 右下 4 点 | 返回上一级；运动中计圈 | 打开最近使用的应用 | —
K2 + K3 | — | — | 同时长按：锁定 / 解锁按键和触摸屏 | 游泳、戴手套、雨天防误触

固件长按门限要错开：K1 的关机菜单用 2s，远小于 DA9168 的硬件复位 12s（RST_TMR 默认值），两者不会冲突。屏幕上下翻页交给触摸屏，也可以在设置里让 K1 / K3 在菜单中兼做上下翻页。

## 7.2 推荐电路


K1：已有 SW1 电路（见《侧键 EVPAEDB2A 接线设计》）

图 4 三键电路：K1 沿用已有电路，K2 / K3 只接 MCU GPIO

开关 | SW1 EVPAEDB2A | SW2、SW3 EVPAEDB2A（统一手感、统一物料）

连接 | PWR_RIN_N（DA9168）+ D1 + KEY1_MCU | 只接 MCU GPIO，不接 RIN_N

MCU 配置 | 输入 + EXTI 下降沿 | 输入 + EXTI 下降沿，可从 Stop 模式唤醒

GPIO 占用 | 1 个 | 2 个（需在 MCU_IO 页确认有空闲的 1.8V EXTI 引脚）

只有 K1 接 RIN_N。K2、K3 如果也接到 RIN_N，任何一个键被长时间压住（比如在包里）都会让整机断电。位号
SW2–SW3、R16–R17、C53–C54 为建议值，C49–C52 已在其他文档中预留，画图时按实际编号调整。

7.3 结构与 PCB 要点
• 三个键都在右侧 2 / 3 / 4 点，相邻键间隔 30°。按 1.43" 屏的外壳估算，按键中心间距约
11–12mm，手指不容易按错。

• EVPAEDB2A 是板边侧推安装，封装自带 3.8mm × 1.35mm 的板边缺口。圆形 PCB 右侧要做 3
个缺口，缺口处的板框要沿切线方向画平。
• K2 的按键帽做成红色或红圈，K1、K3 用普通颜色，方便盲按时区分。也可以把 K2 做得略微凸出或加纹理。

• 左侧不开孔，外壳防水只需处理一侧的 3 个按键轴（每个都加 O 型圈）。
8. 后续版本演进

版本 | 方案 | 新增工作

Rev2.0（本版） | 右侧 3 键 + 触摸屏 | 新增 SW2、SW3 及外围；固件实现按键映射和 K2+K3 锁屏

Rev3.0（可选 A） | 5 键：左侧加 UP / DOWN（或 LIGHT） | 左侧再做 2 个板边缺口；适合定位专业户外 / 游泳

Rev3.0（可选 B） | K2 换成旋转表冠 | 增加磁编码器（霍尔 / TMR）或光学编码器，设计旋转密封结构

X-Watch 运动手表按键方案对比与选型建议 Rev1.0 | 第 6 页

## 9. 参考资料

佳明 fēnix 7 系列官方手册：https://www8.garmin.com/manuals/webhelp/GUID-C001C335-A8EC-4A41-AB0E-BAC434259F92/EN-US/fenix_7_Series_OM_EN-US.pdf
Polar Vantage V3 官方手册 按键功能：https://support.polar.com/e_manuals/vantage-v3/polar-vantage-v3-user-manual-english/button-functions.htm
Amazfit T-Rex 3 官方手册：https://support.amazfit.com/en/amazfit_t-rex_3/files/user-manual.pdf.pdf
Suunto Race 触摸屏与按键：https://www.suunto.com/Support/Product-support/suunto_race/suunto_race/getting-started/touch-screen-and-buttons/
COROS Button and Watch
Layout：https://support.coros.com/hc/en-us/articles/4406640057492-Button-and-Watch-Layout
COROS Pace 3
操作说明：https://support.coros.com/hc/en-us/articles/20731363493780-Operate-the-COROS-PACE-3-watch
Apple Watch 按键与手势：https://support.apple.com/en-us/105063
SamMobile：Galaxy Watch Ultra 新增按键：https://www.sammobile.com/news/new-extra-button-galaxy-watch-ultra/ Tech Advisor：Huawei Watch Ultimate 评测：https://www.techadvisor.com/article/2019480/huawei-watch-ultimate-review.html
Android Central：Amazfit Cheetah Pro 评测：https://www.androidcentral.com/wearables/amazfit-cheetah-pro-review X-Watch 相关文档：《侧键 EVPAEDB2A 接线设计》《佳明 fēnix 7 按键布局与功能分析》《DO0143FMST02 屏 MIPI 接口设计》

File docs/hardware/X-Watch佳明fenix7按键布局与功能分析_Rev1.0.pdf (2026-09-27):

LIGHT; DOWN; START; BACK; 触摸屏; Touchscreen; 1.3 / 1.4 in MIP; GARMIN; ② LIGHT（电源 / 背光）; 短按：开机 · 点亮屏幕 · 双击开手电; 长按：控制菜单 · 关机; ③ UP · MENU（上 / 菜单）; 短按：向上滚动 Glance 与菜单; 长按：打开主菜单（设置）; ④ DOWN（下）; 短按：向下滚动 Glance 与菜单; 长按：任意界面打开音乐控制; ⑤ START · STOP（开始 / 确认）; 短按：确认选项 · 活动列表 · 开始/停止; 长按：可自定义（热键）; ⑥ BACK · LAP（返回 / 计圈）; 短按：返回 · 活动中记圈/休息/换项; 长按：任意界面打开最近使用的应用; START 键带红色标识 （最常用，最易识别）; 佩戴视角正视图（左手佩戴，屏幕朝上）。编号与佳明官方手册 Device Overview 一致，① 为触摸屏。

X-Watch 参考分析：佳明 fēnix 7 按键布局与功能 Rev1.0 | 第 1 页

# 佳明 fēnix 7 按键布局与功能分析

X-Watch 竞品参考 · 适用 fēnix 7S / 7 / 7X 标准版、太阳能版、Pro 版 · Rev1.0 · 2026-09-27

## 1. 结论速览

fēnix 7 系列一共有 5 个实体按键，外加一块触摸屏（fēnix 系列从 7 代开始加入触摸屏）。按键分布是左 3 右 2：左侧从上到下是 LIGHT、UP·MENU、DOWN，负责电源、背光和上下导航；右侧是 START·STOP 和 BACK ·LAP，负责确认、开始/停止活动和返回。每个键都有短按和长按两种功能，长按功能和部分组合键可以在“热 键（Hot Keys）”里自定义。

编号 | 按键 | 位置 | 短按 | 长按
② | LIGHT | 左上（10 点） | 开机；点亮屏幕；快速按两次打开手电筒 | 打开控制菜单；按住直到关机
③ | UP·MENU | 左中（9 点） | 在 Glance 循环和菜单中向上滚动 | 打开主菜单
④ | DOWN | 左下（8 点） | 在 Glance 循环和菜单中向下滚动 | 任意界面打开音乐控制
⑤ | START·STOP | 右上（2 点） | 确认菜单选项；打开活动列表；开始/停止活 动 | 可通过热键自定义
⑥ | BACK·LAP | 右下（4 点） | 返回上一界面；活动中记圈、休息或多项运 动换项 | 任意界面打开最近使用的应用

来源：佳明 fēnix 7 Standard/Solar/Pro Series Owner's Manual，Device Overview（第 1–2 页）。

## 2. 按键分布图

图 1 fēnix 7 正视图：5 个按键的位置与功能

X-Watch 参考分析：佳明 fēnix 7 按键布局与功能 Rev1.0 | 第 2 页

表圈 / 屏幕（朝上）

底壳（光学心率传感器）

左侧（3 键：导航 / 系统）

DOWN | UP | LIGHT
← 6 点方向 | 12 点方向 →

表圈 / 屏幕（朝上）

底壳（光学心率传感器）

右侧（2 键：动作 / 确认）

START | BACK
← 12 点方向 | 6 点方向 →

从外侧平视各侧面，示意图非比例。右侧只有 2 键，9 点对面的 3 点位置空着，便于拇指从左侧托住表壳按压右侧键。
图 2 左右侧视图：左 3 键、右 2 键

## 3. 各按键功能详解

### ② LIGHT —— 电源 / 背光键（左上）

- 短按：关机状态下开机；开机状态下点亮屏幕背光。
- 快速按两次：打开手电筒。fēnix 7X 标准版和 7 Pro 系列有 LED 手电，按下后前 3 秒内可用 UP/DOWN 调亮度或颜色；其他型号用屏幕全白来照明。
- 长按：打开控制菜单（Controls），里面有勿扰、保存位置、手电、关机等快捷开关。
- 一直按住：手表关机。手册的重启方法就是“按住 LIGHT 直到关机，再按住 LIGHT 开机”。
- 求助功能：设置好紧急联系人后，按住
LIGHT，感觉到三次振动时松开，手表会通过手机向紧急联系人发送求助。

### ③ UP·MENU —— 上翻 / 菜单键（左中）

- 短按：在表盘上向上滚动 Glance 循环；在菜单里向上移动；活动中切换数据页。
- 长按：打开主菜单，可以改表盘、调系统设置、配对传感器、切换省电模式等。手册里大部分设置步骤都从“ Hold MENU”开始。

### ④ DOWN —— 下翻键（左下）

- 短按：向下滚动 Glance 循环和菜单；活动中切换数据页。
- 长按：在任意界面打开音乐控制。

### ⑤ START·STOP —— 开始 / 确认键（右上，红色标识）

- 短按：在表盘上打开活动和应用列表；在菜单里确认选项；活动中开始或停止计时。
- 这是最常用的键，所以放在最顺手的 2 点位置，并用红色标出来，戴手套或光线暗时也容易找到。

### ⑥ BACK·LAP —— 返回 / 计圈键（右下）

- 短按：返回上一界面；活动中记录一圈；多项运动中记录休息或换项。
- 长按：在任意界面打开最近使用的应用列表。

### ① 触摸屏

- 点击选择菜单项；上下滑动滚动 Glance 和菜单；右滑返回。
- 长按表盘上的数据可直接打开对应 Glance（部分表盘不支持）。
- 用手掌盖住屏幕：回到表盘并降低亮度。
- 触摸屏只是辅助操作，所有功能都能只用按键完成，适合戴手套、下雨、游泳等场景。

Watch Face; Glance 循环; 心率 / 天气 / Body Battery…; UP / DOWN; BACK; 活动与应用列表; START; 活动计时中; START 暂停/停止 · LAP 计圈; 主菜单; 设置 / 表盘 / 传感器; 长按 MENU; 控制菜单; 长按 LIGHT; 音乐控制; 任意界面; 长按 DOWN; 最近使用的应用; 长按 BACK; 触摸屏开 / 关; 长按 DOWN + START

X-Watch 参考分析：佳明 fēnix 7 按键布局与功能 Rev1.0 | 第 3 页

## 4. 组合键与特殊操作

操作 | 效果 | 来源
长按 DOWN + START | 开启 / 关闭触摸屏（也可在控制菜单或 系统 > 触摸 里设置） | 官方手册
长按 LIGHT | 打开控制菜单 | 官方手册
按住 LIGHT 直到关机 | 关机；再按住 LIGHT 开机，即重启 | 官方手册
按住 LIGHT，感到 3 次振动时松开 | 向紧急联系人发送求助（需先设置紧急联系人并连接手机） | 官方手册
快速按两次 LIGHT | 打开手电筒 | 官方手册
死机时按住 LIGHT 约 15 秒 | 强制重启，不丢数据 | 第三方教程 / 社区经 验，非官方手册原文
菜单 > 系统 > 热键 | 自定义单个按键和双键组合的长按功能 | 官方手册
菜单 > 系统 > 自动锁定 | 自动锁定按键和触摸屏，可分别设置活动中 / 非活动中 | 官方手册
控制菜单 > 锁定设备 | 手动锁定按键和触摸屏，防止误触 | 官方手册

## 5. 界面导航关系

图 3 从表盘出发，各按键进入的主要界面

## 6. 布局设计分析

- 按功能分组：左侧 3 键管“看”（背光、上下翻页、菜单），右侧 2 键管“做”（开始、确认、返回、计圈）。用户只要记住“左边翻、右边按”，不用看表也能操作。
- 一键多用：5 个键 × 短按/长按 = 10
个基本操作，再加上双键组合和热键自定义，覆盖了几乎所有常用功能，不用增加按键数量。
- 最常用的键放在最顺手的位置：左手戴表时，右手食指最容易按到右上 2 点位置，所以 START 放在这里并加红色标识。

X-Watch 参考分析：佳明 fēnix 7 按键布局与功能 Rev1.0 | 第 4 页
- 对侧支撑：右侧只有 2 键，3
点位置空着。按右侧键时，拇指可以从左侧托住表壳，反过来按左侧键时也一样，按压稳定。
- 电源键兼背光键：LIGHT 同时负责开机、背光、关机和求助，这是用户最常在紧急或黑暗中用到的键，放在左 上角独立位置，不容易和导航键混淆。
- 按键是主要操作方式：触摸屏只是补充。户外运动经常戴手套、出汗、下雨，实体按键更可靠。

## 7. 对 X-Watch 的借鉴

X-Watch Rev2.0 目前只有一个侧键 SW1，接在 DA9168 的 RIN_N 上，同时给 MCU 读取（见《侧键 EVPAEDB2A 接线设计》）。参考 fēnix 7，可以按下面的思路规划：

方案 | 按键 | 说明
最小方案（当前） | 1 键：电源 / 确认 | 短按亮屏或确认，长按菜单，超长按硬件复位；其余操作 靠触摸屏
推荐方案 | 3 键：左上电源/背光 + 右上确认 + 右下返回 | 电源键接 RIN_N（对应 fēnix 的 LIGHT）；确认、返回只接 MCU GPIO。触摸屏负责上下翻页
完整方案 | 5 键：照搬 fēnix 7 布局 | 增加左侧 UP / DOWN，适合戴手套、游泳场景；结构和防水成本最高

硬件要点：不管用几个键，只有“电源键”接 DA9168 的 RIN_N，负责 Ship 模式唤醒和长按硬件复位，对应 fēnix 7 的 LIGHT 键（按住开机、按住关机）。其他按键只接 MCU 的 GPIO，避免误触导致整机断电。每个键都建议用同一款 EVPAEDB2A，统一手感和物料。

## 8. 参考资料

佳明 fēnix 7 Standard/Solar/Pro Series Owner's Manual（英文 PDF，162 页）：https://www8.garmin.com/manuals/webhelp/GUID-C001C335-A8EC-4A41-AB0E-BAC434259F92/EN-US/fenix_7_Series_OM_EN-US.pdf（Device Overview 第 1–2 页；手电筒第 76 页；求助第 110 页；热键、自动锁定第 122–124 页；重启第 131 页）
佳明在线手册 Device Overview：https://www8.garmin.com/manuals/webhelp/GUID-C001C335-A8EC-4A41-AB0E-BAC434259F92/EN-US/GUID-85E597B6-976C-4E1D-AE29-0EBBDDD4613C.html
佳明支持：为 fēnix 7 / 7 Pro 添加热键：https://support.garmin.com/en-US/?faq=jbZhv8loj14TUvcW4l2Le9
DC Rainmaker：Garmin Fenix 7 Pro In-Depth Review：https://www.dcrainmaker.com/2023/05/flashlight-multiband-everyone.html the5krunner：Garmin Fenix 7 & Epix 2 Tricks and Tips：https://the5krunner.com/2022/02/20/garmin-fenix-7-tricks-tips/
强制重启 15 秒：https://www.hardreset.info/devices/garmin/garmin-fenix-7/softreset/（第三方）

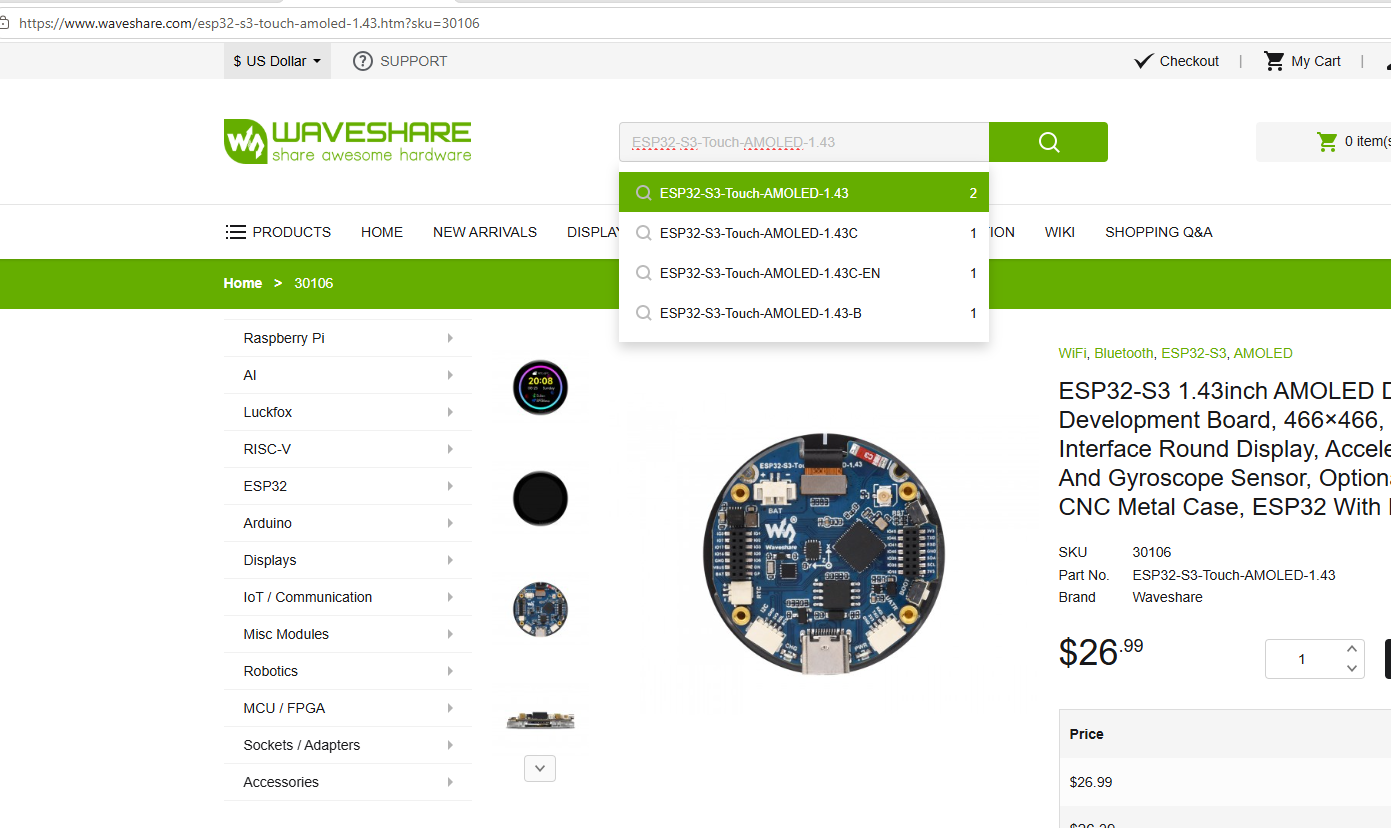
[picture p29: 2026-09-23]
docs/references/Rev2.0/显示屏/ESP32-S3-Touch-AMOLED-1.43.png

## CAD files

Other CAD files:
tools/LC_3D_Module_Download-master/step/ANT-SMD_KH-IPEX-K501-29.step

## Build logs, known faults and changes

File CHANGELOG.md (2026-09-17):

# Changelog

本文件记录项目所有重要变更。格式基于 [Keep a Changelog](https://keepachangelog.com/).

## [Unreleased]

### Added
- 初始化项目模板结构
- 固件分层架构 (app / hal / drivers / services)
- 板级配置系统 (boards/)
- CI/CD 构建流水线
- 构建辅助脚本 (build.py)

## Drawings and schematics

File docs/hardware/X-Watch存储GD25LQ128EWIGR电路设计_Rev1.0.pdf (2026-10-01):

# X-Watch 存储 GD25LQ128EWIGR 电路设计（Rev1.0）

## 设计要点

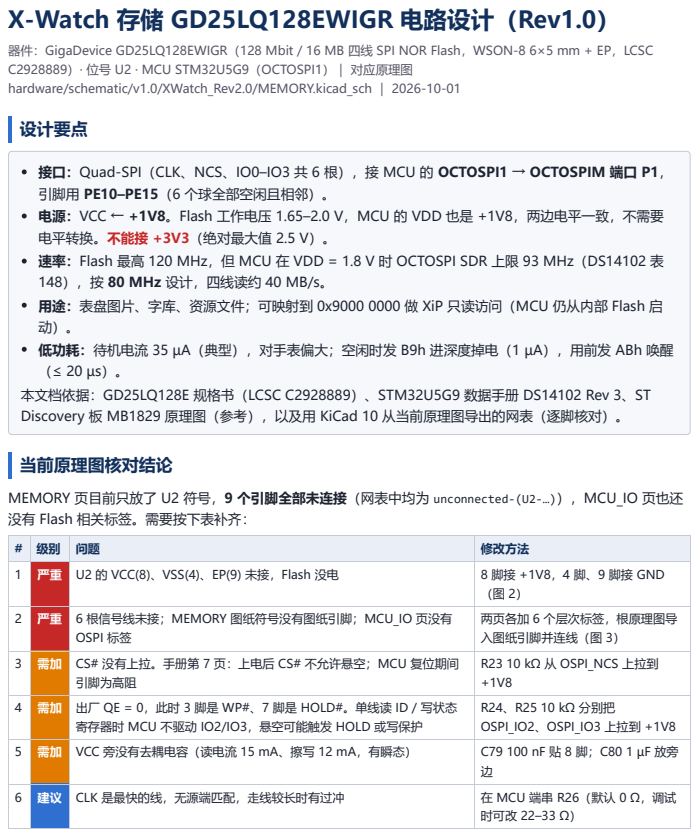
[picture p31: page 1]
当前原理图核对结论

器件：GigaDevice GD25LQ128EWIGR（128 Mbit / 16 MB 四线 SPI NOR Flash，WSON-8 6×5 mm + EP，LCSC
C2928889）· 位号 U2 · MCU STM32U5G9（OCTOSPI1）｜ 对应原理图
hardware/schematic/v1.0/XWatch_Rev2.0/MEMORY.kicad_sch ｜ 2026-10-01

接口：Quad-SPI（CLK、NCS、IO0–IO3 共 6 根），接 MCU 的 OCTOSPI1 → OCTOSPIM 端口 P1，
引脚用 PE10–PE15（6 个球全部空闲且相邻）。
电源：VCC ← +1V8。Flash 工作电压 1.65–2.0 V，MCU 的 VDD 也是 +1V8，两边电平一致，不需要
电平转换。不能接 +3V3（绝对最大值 2.5 V）。
速率：Flash 最高 120 MHz，但 MCU 在 VDD = 1.8 V 时 OCTOSPI SDR 上限 93 MHz（DS14102 表
148），按 80 MHz 设计，四线读约 40 MB/s。
用途：表盘图片、字库、资源文件；可映射到 0x9000 0000 做 XiP 只读访问（MCU 仍从内部 Flash 启
低功耗：待机电流 35 µA（典型），对手表偏大；空闲时发 B9h 进深度掉电（1 µA），用前发 ABh 唤醒
本文档依据：GD25LQ128E 规格书（LCSC C2928889）、STM32U5G9 数据手册 DS14102 Rev 3、ST
Discovery 板 MB1829 原理图（参考），以及用 KiCad 10 从当前原理图导出的网表（逐脚核对）。

MEMORY 页目前只放了 U2 符号，9 个引脚全部未连接（网表中均为 unconnected-(U2-…)），MCU_IO 页也还
没有 Flash 相关标签。需要按下表补齐：

# | 级别 | 问题 | 修改方法
1 | 严重 | U2 的 VCC(8)、VSS(4)、EP(9) 未接，Flash 没电 | 8 脚接 +1V8，4 脚、9 脚接 GND （图 2）

2 | 严重 | 6 根信号线未接；MEMORY 图纸符号没有图纸引脚；MCU_IO 页没有 OSPI 标签 | 两页各加 6 个层次标签，根原理图导 入图纸引脚并连线（图 3）

3 | 需加 | CS# 没有上拉。手册第 7 页：上电后 CS# 不允许悬空；MCU 复位期间 引脚为高阻 | R23 10 kΩ 从 OSPI_NCS 上拉到 +1V8

4 | 需加 | 出厂 QE = 0，此时 3 脚是 WP#、7 脚是 HOLD#。单线读 ID / 写状态 寄存器时 MCU 不驱动 IO2/IO3，悬空可能触发 HOLD 或写保护 | R24、R25 10 kΩ 分别把 OSPI_IO2、OSPI_IO3 上拉到 +1V8

5 | 需加 | VCC 旁没有去耦电容（读电流 15 mA、擦写 12 mA，有瞬态） | C79 100 nF 贴 8 脚；C80 1 µF 放旁 边

6 | 建议 | CLK 是最快的线，无源端匹配，走线较长时有过冲 | 在 MCU 端串 R26（默认 0 Ω，调试 时可改 22–33 Ω）

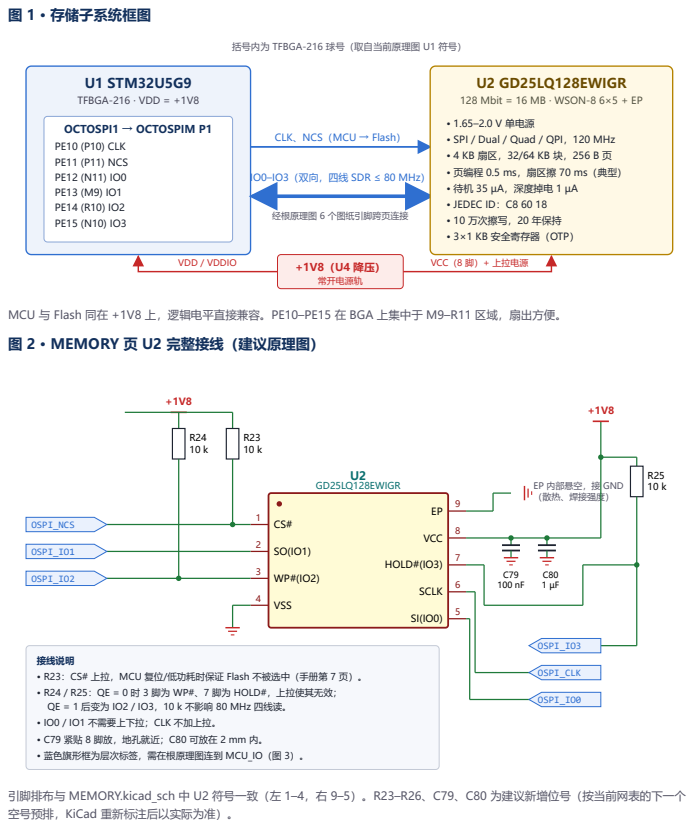
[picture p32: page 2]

括号内为 TFBGA-216 球号（取自当前原理图 U1 符号）

U2 GD25LQ128EWIGR
128 Mbit = 16 MB · WSON-8 6×5 + EP
• 1.65–2.0 V 单电源
• SPI / Dual / Quad / QPI，120 MHz
• 页编程 0.5 ms，扇区擦 70 ms（典型）
• 待机 35 µA，深度掉电 1 µA
• JEDEC ID：C8 60 18
• 10 万次擦写，20 年保持
• 3×1 KB 安全寄存器（OTP）

CLK、NCS（MCU → Flash）

IO0–IO3（双向，四线 SDR ≤ 80 MHz）

MCU 与 Flash 同在 +1V8 上，逻辑电平直接兼容。PE10–PE15 在 BGA 上集中于 M9–R11 区域，扇出方便。
图 2 · MEMORY 页 U2 完整接线（建议原理图）

接线说明
• R23：CS# 上拉，MCU 复位/低功耗时保证 Flash 不被选中（手册第 7 页）。
• R24 / R25：QE = 0 时 3 脚为 WP#、7 脚为 HOLD#，上拉使其无效；
QE = 1 后变为 IO2 / IO3，10 k 不影响 80 MHz 四线读。
• IO0 / IO1 不需要上下拉；CLK 不加上拉。
• C79 紧贴 8 脚放，地孔就近；C80 可放在 2 mm 内。
• 蓝色旗形框为层次标签，需在根原理图连到 MCU_IO（图 3）。

引脚排布与 MEMORY.kicad_sch 中 U2 符号一致（左 1–4，右 9–5）。R23–R26、C79、C80 为建议新增位号（按当前网表的下一个
空号预排，KiCad 重新标注后以实际为准）。

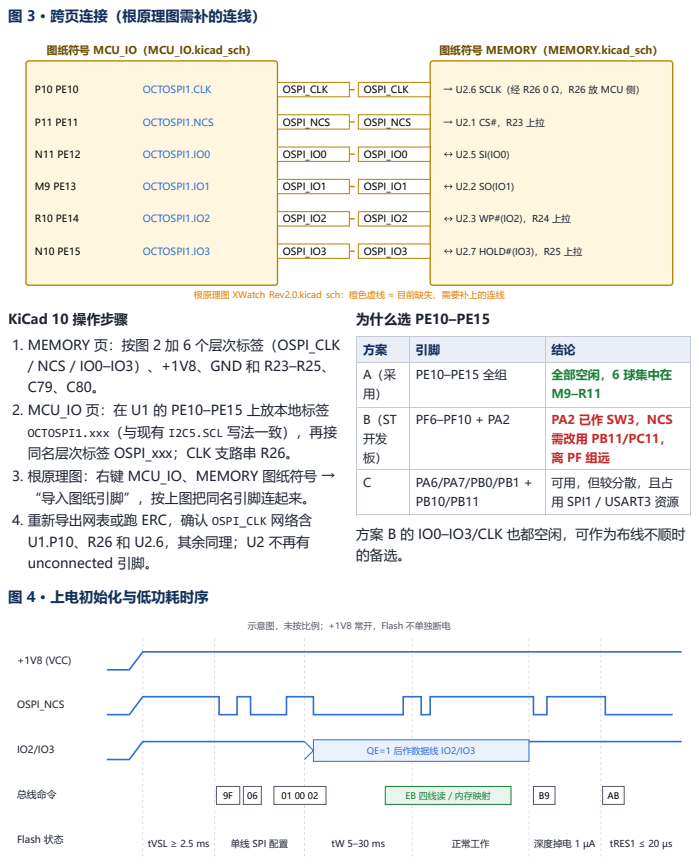
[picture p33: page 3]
图 3 · 跨页连接（根原理图需补的连线）; 图纸符号 MCU_IO（MCU_IO.kicad_sch）; 图纸符号 MEMORY（MEMORY.kicad_sch）; OCTOSPI1.CLK; OCTOSPI1.NCS; OCTOSPI1.IO0; OCTOSPI1.IO1; OCTOSPI1.IO2; OCTOSPI1.IO3; OSPI_CLK; OSPI_NCS; OSPI_IO0; OSPI_IO1; OSPI_IO2; OSPI_IO3; → U2.6 SCLK（经 R26 0 Ω，R26 放 MCU 侧）; ↔ U2.7 HOLD#(IO3)，R25 上拉; 为什么选 PE10–PE15; +1V8 (VCC); 总线命令; Flash 状态; QE=1 后作数据线 IO2/IO3; EB 四线读 / 内存映射; tVSL ≥ 2.5 ms; 单线 SPI 配置; 正常工作; 深度掉电 1 µA tRES1 ≤ 20 µs

根原理图 XWatch Rev2.0.kicad sch：橙色虚线 = 目前缺失、需要补上的连线

KiCad 10 操作步骤
1. MEMORY 页：按图 2 加 6 个层次标签（OSPI_CLK
/ NCS / IO0–IO3）、+1V8、GND 和 R23–R25、
2. MCU_IO 页：在 U1 的 PE10–PE15 上放本地标签
OCTOSPI1.xxx（与现有 I2C5.SCL 写法一致），再接
同名层次标签 OSPI_xxx；CLK 支路串 R26。
3. 根原理图：右键 MCU_IO、MEMORY 图纸符号 →
“导入图纸引脚”，按上图把同名引脚连起来。
4. 重新导出网表或跑 ERC，确认 OSPI_CLK 网络含
U1.P10、R26 和 U2.6，其余同理；U2 不再有
unconnected 引脚。
图 4 · 上电初始化与低功耗时序

方案 | 引脚 | 结论
A（采 用） | PE10–PE15 全组 | 全部空闲，6 球集中在 M9–R11

B（ST 开发 板） | PF6–PF10 + PA2 | PA2 已作 SW3，NCS 需改用 PB11/PC11， 离 PF 组远

C | PA6/PA7/PB0/PB1 + PB10/PB11 | 可用，但较分散，且占 用 SPI1 / USART3 资源

方案 B 的 IO0–IO3/CLK 也都空闲，可作为布线不顺时
的备选。

示意图，未按比例；+1V8 常开，Flash 不单独断电

Flash 关键时序（规格书 8.1 / 8.6 节）

参数 | 符号 | 值
VCC 达标后到可访问 | tVSL | ≥ 2.5 ms
写保护阈值 | VWI | 1.0–1.5 V
CS# 高电平最短时间 | tSHSL | ≥ 20 ns
写状态寄存器时间 | tW | 5 / 30 ms（典型/最大）
进入深度掉电 | tDP | ≤ 20 µs
退出深度掉电 | tRES1 | ≤ 20 µs
软复位后（擦写中） | tRST_E | ≤ 12 ms
时钟（除 03h 外） | Fc | ≤ 120 MHz

固件初始化顺序（摘要）

// OCTOSPI1：单 Flash，DEVSIZE = 24 (16 MB)
// 时钟 160 MHz / 2 = 80 MHz，CSHT ≥ 2 周期
delay ≥ 2.5 ms | // 上电后 tVSL
66h ; 99h ; delay 12 ms | // 软复位（防止热复位时处
于擦写中）
9Fh → 期望 C8 60 18 | // 读 JEDEC ID
35h → 若 QE(bit1) = 0：
06h ; 01h 00h 02h | // SR1=00, SR2 置 QE
轮询 05h 直到 WIP = 0
// 读：EBh，1-4-4，24 位地址
// 模式字节 2 周期 + 4 个空周期
// 写：06h + 32h（四线页编程，≤ 256 B） // 擦：20h（4 KB）/ 52h / D8h
// 空闲：B9h；使用前：ABh + 20 µs
QE 是非易失位，只需在首次上电（或产线烧录时）写
一次；写之前先读回，避免每次开机都擦写状态寄存
器。
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

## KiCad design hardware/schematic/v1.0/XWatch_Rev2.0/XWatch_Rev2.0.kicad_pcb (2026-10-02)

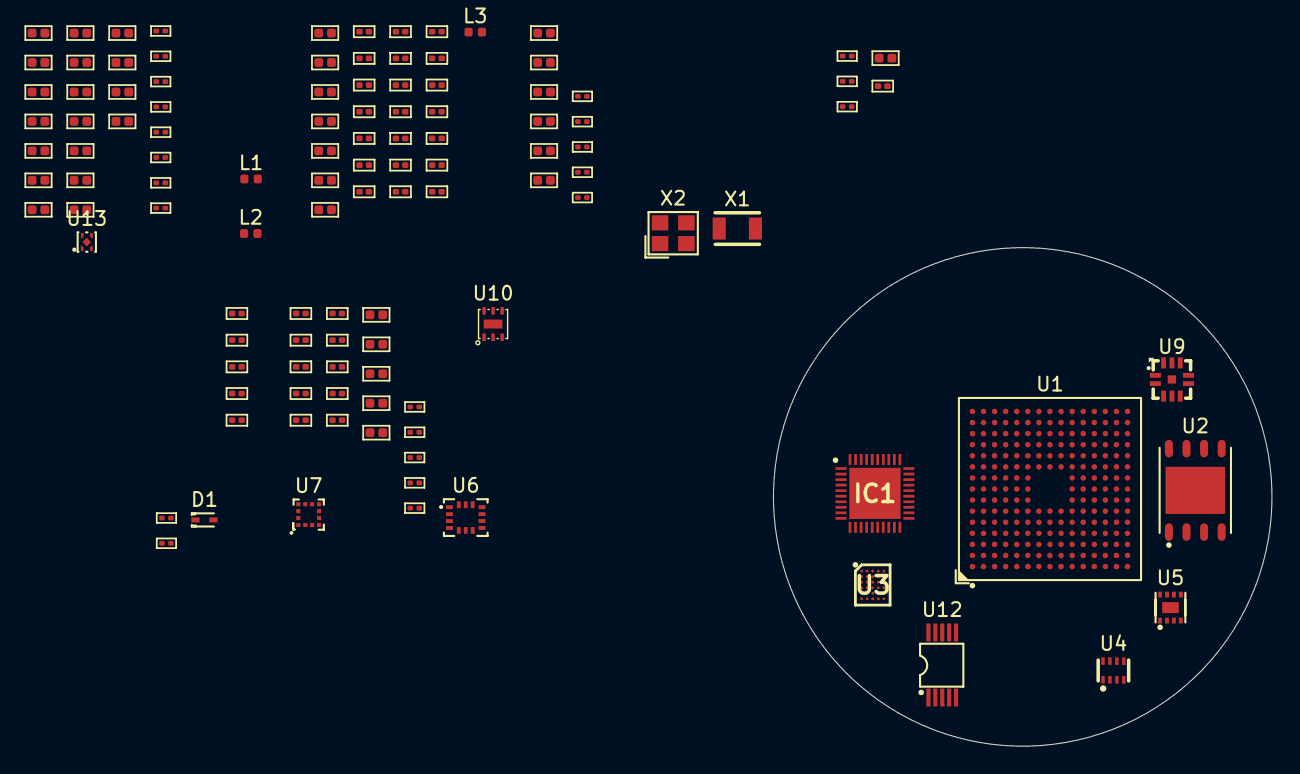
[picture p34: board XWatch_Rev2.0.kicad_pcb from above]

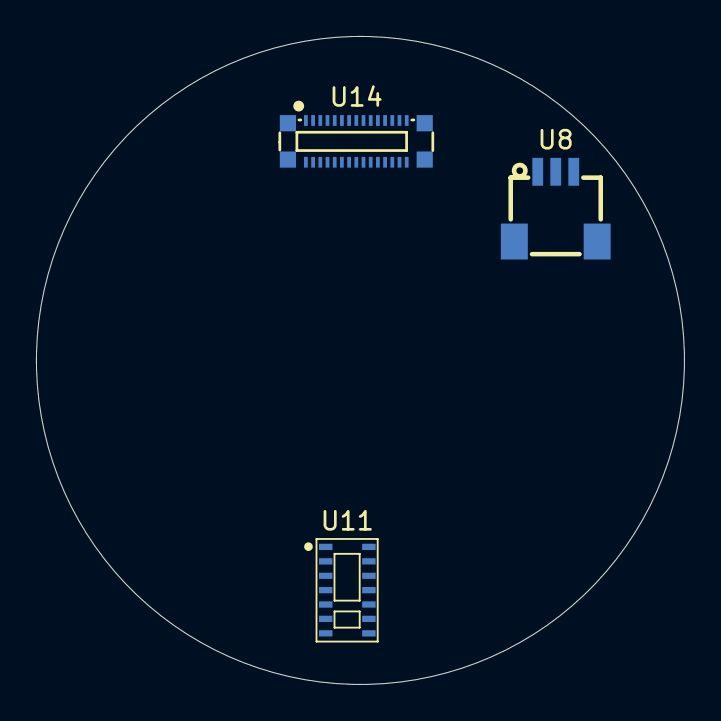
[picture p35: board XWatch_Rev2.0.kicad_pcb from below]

Board: 2 copper layers, 36.0 x 36.0 mm, 118 parts (3 on the bottom side), 48 nets, no tracks yet.

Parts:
C1, C2: 5.6pF; GEN_C_0201
C3, C4: 10pF; GEN_C_0201
C5, C15, C33: 4.7uF; GEN_C_0402
C6, C9, C10, C16, C17, C30, C46, C59, C63, C78: 10uF; GEN_C_0402
C7, C14, C49, C73, C75, C77: 100nF; GEN_C_0402
C8: 47nF; GEN_C_0402
C11, C12, C13, C41, C42: 2.2uF; GEN_C_0402
C18, C19, C34, C36, C61, C62, C64, C65, C66, C68, C74, C76: 1uF; GEN_C_0402
C20, C21, C22, C23, C24, C25, C26, C27, C28, C29, C31, C32, C35, C37, C38, C39, C40, C43, C44, C45, C47, C48, C50, C51, C53, C54, C55, C56, C57, C58, C60, C67: 100nF; GEN_C_0201
C52: 220nF; GEN_C_0201
D1: RB520S-30; RB520S-30_C7502701
IC1: nRF52833-QDAA-R; QFN40P500X500X90-41N
L1, L2, L3: 2.2uH; L_0402_1005Metric
R3, R17, R19: 100K; GEN_R_0201
R4, R5, R13, R14: 4.7K; GEN_R_0201
R6, R7, R8, R15, R16, R18, R20, R21, R23, R24, R25: 10K; GEN_R_0201
R9: 24.9 k 1%; GEN_R_0201
R10: 38.3 k 1%; GEN_R_0201
R11, R12: 2.2K; GEN_R_0201
R22: 0; GEN_R_0201
U1: STM32U5G9NJH6Q
U2: GD25LQ128EWIGR
U3: DA9168; BGA30C40P5X6_214X254X56
U4: TPS62840DLCR
U5: MAX17048G_T10
U6: LSM6DSOXTR
U7: LIS2MDLTR
U8: SM03B-SRSS-TB_LF_SN_P
U9: LPS27HHWTR
U10: OPT3001DNPR
U11: MAX30101EFD_T
U12: DRV2605LDGSR
U13: SK6018D4-33
U14: AXE530127-DO0143FMST02; AXE530127
X1: 32.768KHZ; NX3215SA_32_768KHZ_EXS00A-MU00525
X2: 16MHZ; TXM16M0004252CBCEO00T

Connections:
+1V8: C6.1, C20.1, C21.1, C22.1, C23.1, C24.1, C25.1, C26.1, C27.1, C28.1, C29.1, C30.1, C31.1, C32.1, C33.1, C38.1, C39.1, C40.1, C46.1, C47.1, C50.1, C51.1, C53.1, C54.1, C55.1, C56.2, C57.1, C60.1, C61.1, C67.2, C68.2, C75.2, C76.2, L1.2, R4.1, R5.1, R6.1, R7.1, R11.1, R12.1, R13.1, R14.1, R15.1, R16.1, R18.1, R20.1, R21.1, R23.1, R24.1, R25.2, U1.C2 (VBAT), U1.E8 (VDDIO2), U1.E9 (VDDUSB), U1.F5 (VDD), U1.F8 (VDD), U1.G5 (VDDDSI), U1.G11 (VDDIO2), U1.H11 (VDD), U1.J5 (VDD), U1.J11 (VDD), U1.K11 (VDD), U1.L7 (VDD), U1.L8 (VDD), U1.L9 (VDD), U1.L11 (VDD), U1.R12 (VDDSMPS), U2.8 (VCC), U4.8 (VOS), U6.5 (VDDIO), U6.8 (VDD), U6.12 (CS), U7.3 (CS), U7.9 (Vdd), U7.10 (Vdd_IO), U9.1 (Vdd_IO), U9.6 (CS), U9.10 (VDD), U10.1 (VDD), U11.11 (VDD), U14.25 (VDDIO)
+3V3: C66.1, C73.1, C74.1, U13.1 (VOUT), U14.11 (TP_VCC), U14.23 (VCI_IN)
/DSI_LCD/TP_INT: R20.2, U14.7 (TP_INT)
/DSI_LCD/TP_SCL: R14.2, U14.3 (TP_SCL)
/DSI_LCD/TP_SDA: R13.2, U14.5 (TP_SDA)
/MEMORY/OSPI_IO2: R23.2, U2.3 (WP#(IO2))
/MEMORY/OSPI_IO3: R25.1, U2.7 (HOLD#(IO3))
/MEMORY/OSPI_NCS: R24.2, U2.1 (CS#)
/PWR/BAT_NTC: R9.2, R10.1, U3.D3 (TMP__SNS), U8.2 (NTC)
/PWR/EN_3V3: R19.1, U13.3 (EN)
/PWR/FG_ALRT_N: R7.2, U5.5 (ALRT#)
/PWR/PWR_CHG_EN_N: R3.1, U3.E3 (CHG__EN_N)
/PWR/PWR_INT_N: R6.2, U3.F4 (INT_N)
/PWR/PWR_RIN_N: C49.1, U3.D4 (RIN_N)
/PWR/PWR_SCL: R4.2, U3.F5 (SCL), U5.7 (SCL)
/PWR/PWR_SDA: R5.2, U3.E4 (SDA), U5.8 (SDA)
/SENSOR/ALS_INT_N: R15.2, U10.5 (INT)
/SENSOR/DRV_REG: C64.2, U12.1 (REG)
/SENSOR/HAPTIC_EN: R17.1, U12.5 (EN)
/SENSOR/MAG_C1: C52.1, U7.5 (C1)
/SENSOR/PPG_INT_N: R16.2, U11.13 (INT#)
/SENSOR/SENSOR_SCL: R12.2, U6.13 (SCL), U7.1 (SCL/SPC), U9.2 (SCL/SPC), U10.4 (SCL), U11.2 (SCL), U12.2 (SCL)
/SENSOR/SENSOR_SDA: R11.2, U6.14 (SDA), U7.4 (SDA/SDI/SDO), U9.4 (SDA/SDI/SDO), U10.6 (SDA), U11.3 (SDA), U12.3 (SDA)
GND: C1.1, C2.1, C3.1, C4.2, C5.2, C6.2, C7.2, C9.2, C10.2, C11.2, C12.2, C13.2, C14.2, C15.2, C16.2, C17.2, C18.2, C19.2, C20.2, C21.2, C22.2, C23.2, C24.2, C25.2, C26.2, C27.2, C28.2, C29.2, C30.2, C31.2, C32.2, C33.2, C34.2, C35.2, C36.2, C37.2, C38.2, C39.2, C40.2, C41.2, C42.2, C43.2, C44.2, C45.2, C46.2, C47.2, C48.2, C49.2, C50.2, C51.2, C52.2, C53.2, C54.2, C55.2, C56.1, C57.2, C58.2, C59.2, C60.2, C61.2, C62.2, C63.2, C64.1, C65.2, C66.2, C67.1, C68.1, C73.2, C74.2, C75.1, C76.1, C77.1, C78.1, R3.2, R8.2, R10.2, R17.2, R19.2, R22.1, U1.A1 (VSS), U1.A15 (VSS), U1.E10 (VSS), U1.F6 (VSS), U1.F7 (VSS), U1.F9 (VSS), U1.F10 (VSS), U1.G6 (VSSDSI), U1.G10 (VSS), U1.H2 (VSSDSI), U1.H6 (VSSDSI), U1.H10 (VSS), U1.H15 (VSS), U1.J2 (VSSDSI), U1.J6 (VSS), U1.J10 (VSS), U1.J15 (VSS), U1.K5 (VREFM), U1.K6 (VSSA), U1.K7 (VSS), U1.K8 (VSS), U1.K9 (VSS), U1.K10 (VSS), U1.L10 (VSS), U1.P12 (VSSSMPS), U1.R1 (VSS), U1.R15 (VSS), U2.4 (VSS), U2.9 (EP), U3.A1 (GND), U3.B1 (AGND), U3.E5 (EN), U4.1 (GND), U4.3 (MODE), U4.5 (VSET), U4.6 (STOP), U5.1 (CTG), U5.4 (GND), U5.6 (QSTRT), U5.9 (EP), U6.1 (SDO/SA0), U6.2 (SDX), U6.3 (SCX), U6.6 (GND), U6.7 (GND), U7.6 (GND), U7.8 (GND), U8.3 (BAT-), U8.4, U8.5, U9.3 (Reserved), U9.5 (SDO/SA0), U9.8 (GND), U9.9 (GND), U9.11 (GND), U10.2 (ADDR), U10.3 (GND), U10.7 (EP), U11.4 (PGND), U11.12 (GND), U12.4 (IN/TRIG), U12.8 (GND), U13.2 (GND), U13.5 (GND), U14.1 (GND), U14.2 (DCX_RS), U14.4 (WRX_SCL), U14.8 (SDI3), U14.10 (SDI2), U14.14 (RDX_SDIO0), U14.15 (IM1), U14.16 (GND), U14.17 (IM0), U14.22 (GND), U14.28 (GND), U14.Y1, U14.Y2, U14.Z1, U14.Z2, X2.4
unnamed: C3.2, X2.2
unnamed: D1.2 (A), R18.2, U1.N4 (PA0-WKUP1)
unnamed: C34.1, C35.1, C36.1, C37.1, U1.L5 (VREFP), U1.L6 (VDDA)
unnamed: L3.2, U1.R11 (VLXSMPS)
unnamed: C48.1, U1.R2 (NRST)
unnamed: C2.2, U1.B1 (PC14-OSC32_IN), X1.2
unnamed: C1.2, U1.C1 (PC15-OSC32_OUT), X1.1
unnamed: U1.N1 (PH0-OSC_IN), X2.3 (OSC2)
unnamed: C4.1, U1.N2 (PH1-OSC_OUT), X2.1 (OSC1)
unnamed: R8.1, U1.B4 (PH3-BOOT0)
unnamed: C8.1, L2.1
unnamed: R9.1, U3.C5 (ILIMIT)
unnamed: C15.1, U3.C4 (REF)
unnamed: C8.2, U3.C3 (VBTS)
unnamed: C16.1, C17.1
unnamed: C12.1, U3.B5 (VOUT1)
unnamed: C13.1, U3.D5 (VOUT2)
unnamed: L1.1, U4.7 (SW)
unnamed: R21.2, U14.6 (CS)
unnamed: R22.2, U14.12 (SDO_SDI1)
VBAT: C7.1, C11.1, C14.1, C62.1, C63.1, U3.F3 (VBAT__SNS), U5.2 (CELL), U5.3 (VDD), U8.1 (BAT+), U12.6 (VDD/NC), U12.10 (VDD)
VBUS: C18.1, C19.1, U3.A5 (VBUS__SNS)
VDD11: C41.1, C42.1, C43.1, C44.1, C45.1, L3.1, U1.E6 (VDD11), U1.E11 (VDD11), U1.F11 (VDD11USB), U1.H5 (VDD11DSI), U1.R13 (VDD11)
VSYS: C5.1, C9.1, C10.1, C58.1, C59.1, C65.1, C77.2, C78.2, L2.2, U4.2 (VIN), U4.4 (EN), U11.9 (VLED+), U11.10 (VLED+), U13.4 (VIN), U14.29 (VBAT), U14.30 (VBAT)

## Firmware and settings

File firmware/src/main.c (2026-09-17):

/**
 * @file main.c
 * @brief 固件入口点
 *
 * 职责:
 *   - 系统初始化 (时钟/电源/外设)
 *   - 启动各服务模块
 *   - 进入主循环或 RTOS 调度
 */

#include "hal/hal_init.h"
#include "app/app_main.h"
#include "services/service_manager.h"

int main(void)
{
    /* 1. 硬件抽象层初始化 */
    hal_init();

    /* 2. 服务层启动 */
    service_manager_init();

    /* 3. 应用层入口 */
    app_run();

    /* 不应到达此处 */
    while (1) {
        /* idle / WFI */
    }

    return 0;
}

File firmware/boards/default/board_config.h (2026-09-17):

/**
 * @file board_config.h
 * @brief 默认板级配置
 *
 * 此文件定义默认硬件引脚映射和参数。
 * 不同硬件版本应创建独立的 boards/<board_name>/board_config.h
 */

#ifndef BOARD_CONFIG_H
#define BOARD_CONFIG_H

/* ---- MCU 配置 ---- */
#define BOARD_NAME              "default"
#define MCU_TYPE                "STM32L4R9AII6U"
#define SYSTEM_CLOCK_HZ         120000000

/* ---- UART 引脚映射 ---- */
#define UART_DEBUG_TX_PIN       GPIO_PIN_9    /* PA9  */
#define UART_DEBUG_RX_PIN       GPIO_PIN_10   /* PA10 */
#define UART_DEBUG_BAUDRATE     115200

/* ---- SPI 引脚映射 ---- */
#define SPI_SCK_PIN             GPIO_PIN_5
#define SPI_MISO_PIN            GPIO_PIN_6
#define SPI_MOSI_PIN            GPIO_PIN_7
#define SPI_CS_PIN              GPIO_PIN_4

/* ---- I2C 引脚映射 ---- */
#define I2C_SCL_PIN             GPIO_PIN_6    /* PB6 */
#define I2C_SDA_PIN             GPIO_PIN_7    /* PB7 */

/* ---- LED / 按键 ---- */
#define LED_STATUS_PIN          GPIO_PIN_13   /* PC13 */
#define BTN_USER_PIN            GPIO_PIN_0    /* PA0  */

#endif /* BOARD_CONFIG_H */

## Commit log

2026-09-17 Ignore KiCad local history and lock files
2026-09-17 Add README; set default board MCU to STM32L4R9AII6U
2026-09-17 Switch license to MIT
2026-09-17 Add project-local KiCad symbol and footprint libraries
2026-09-17 Update KiCad project settings and schematic
    [XWatch_Rev1.0.kicad_sch]
2026-09-17 Add MCU and display connector symbols, UFBGA-169 footprint, LCSC STM32L4R9AII6 import and schematic sheets
    [Display.kicad_sch, MCU.kicad_sch, XWatch_Rev1.0.kicad_sch]
2026-09-17 Track .wrl models with Git LFS; drop missing JLCImport footprint library
2026-09-17 Add Rev1.0 reference docs and component selection reports
    - Reorganize references into MCU/开发板/显示屏/连接器/芯片手册/架构 folders
    - Add GNSS module references (SE873K5-D, LC79H) with Chinese summaries
    - Add sensor references (BMI270 docs, LSM6DSOX AN5273) with summaries
    - Add SGM38046 AMOLED power supply datasheet and summary
    - Add hardware module partition and commercial smartwatch teardown / chip selection reports
2026-09-17 Add schematic sub-sheets and component libraries for Rev1.0
    - Add Power, GNSS, Sensors, Memory and Connectivity schematic sheets
    - Add symbols/footprints for DA9168, SGM38046, MAX86141, BMI270, LSM6DSOX, LIS2MDL, AK09918C, NT3H1101
    - Add 3D models for new parts
    [Connectivity.kicad_sch, GNSS.kicad_sch, MCU.kicad_sch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]
2026-09-17 sch and pcb update
    [Connectivity.kicad_sch]
2026-09-18 doc and sch update
    [Audio.kicad_sch, Display.kicad_sch, MCU.kicad_sch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]
2026-09-20 sch and doc update
    [Display.kicad_sch, MCU.kicad_sch, Power.kicad_sch]
2026-09-21 sch update
    [Power.kicad_sch]
2026-09-23 add rev2.0
    [DSI_LCD.kicad_sch, MCU.kicad_sch, MCU_IO.kicad_sch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]
